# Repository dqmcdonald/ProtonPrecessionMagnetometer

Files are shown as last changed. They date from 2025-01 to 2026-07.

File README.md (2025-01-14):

Design files for a Proton Precession Magnetometer

Based on "Signals from the Subatomic World" by Stefan and Richard Hollos
https://books.google.co.nz/books/about/Signals_from_the_Subatomic_World_How_to.html

There are several related designs here including SVG files for cutting the coil formers and supports and
Kicad files for the pulse controller and signal amplipher. 

Hardware:

	PPM Amplifier v1.0 - initial failed design for signal amplifier

	PPM Amplifier v2.0 

  	PPM Mosfet Bank - PCB for coil switching mosfets

	Pulse Controller - Arduino based controller and ADC for data collection

	Various design files for polarising and sensor coil formers. 

Software:

	PPMPulseControllerADC - Arduino sketch for pulse control and signal 
				collection

	RPiPythonCode - Python scripts to run on the Raspberry Pi - overall
			control and final analysis.

There are some KiCad symbols and footprints in other respositories https://github.com/dqmcdonald/DQM_kicad_new.pretty and https://github.com/dqmcdonald/DQM_kicad

Quentin McDonald

October 2024

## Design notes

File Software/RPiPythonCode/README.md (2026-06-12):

# Proton Precession Magnetometer — Raspberry Pi Software

Python software for controlling and analysing a Proton Precession Magnetometer (PPM).
The system polarises a water sample with an electromagnet, then measures the Larmor
precession frequency of the protons as they relax back into alignment with Earth's
field.  The Larmor frequency is directly proportional to the total magnetic field
strength:

```
B (µT) = f (Hz) / 42.5775
```

---

## Hardware

| Component | Detail |
|---|---|
| Controller | Raspberry Pi (any model with a UART) |
| Microcontroller | Arduino Pro Mini |
| Serial connection | auto-detected (USB adapter or `/dev/serial0`), 250000 baud — override with `--port` |
| Coil | Solenoid wound around a water-filled sample bottle |

The Arduino controls the polarising coil (MOSFET switched) and samples the precession
signal via an ADC.  The Raspberry Pi sends configuration commands and retrieves the
raw sample data over serial.

### Coil and sample orientation

For maximum signal the coil axis must be **perpendicular to Earth's field**.
Earth's field lies entirely in the North–vertical plane, so there are two
equally valid setups:

- **Option A (recommended):** Orient the coil axis **East–West**, level.
  No tilt required — East is always perpendicular to Earth's field.
- **Option B:** Orient the coil axis in the North–South vertical plane,
  tilted `(90° − inclination)` above horizontal with the North end elevated.
  At 68°35′ inclination this is 21.4° above horizontal.

Run `ppm_geometry.py` for a diagram and full explanation tailored to your location.

---

## Installation

```bash
pip install pyserial numpy matplotlib scipy
```

All dependencies run on Raspberry Pi OS without additional system packages.

---

## Running a measurement

```bash
python ppmrun.py [options]
```

Each run creates a timestamped directory under `data/` containing the raw data
files, plots, and a log.

### Common examples

```bash
# Single run with default settings
python ppmrun.py

# Tag the run for easy identification
python ppmrun.py --tag outdoor_test

# Average 5 runs (improves SNR by √5)
python ppmrun.py --runs 5 --tag hillside

# Adjust hardware timing (e.g. longer polarisation)
python ppmrun.py --on-time 8000 --sample-time 2000

# Narrow the bandpass filter around the expected Larmor frequency
python ppmrun.py --low-freq 2200 --high-freq 2700

# Background subtraction: collect 2 coil-off acquisitions first and subtract
# their spectrum (suppresses mains harmonics inside the Larmor band)
python ppmrun.py --runs 3 --background-runs 2

# Re-analyse an existing data file without any hardware
python ppmrun.py --input data/ppm1.dat --tag reanalysis

# Re-analyse using an old no-sample recording as the background
python ppmrun.py --input data/ppm1.dat --background-input data/nosample.dat

# Collect data without generating plots
python ppmrun.py --no-plots
```

### All options

| Option | Default | Description |
|---|---|---|
| `--input FILE` | — | Re-analyse an existing `.dat` file; no hardware required |
| `--tag TAG` | `PPM` | Prefix for the output directory name |
| `--runs N` | `1` | Number of measurement cycles to average |
| `--background-runs N` | `0` | Coil-off acquisitions to collect for background spectral subtraction |
| `--background-input FILE` | — | Existing `.dat` file to use as the background instead of collecting one |
| `--on-time MS` | `6000` | Coil polarisation duration (ms) |
| `--sample-time MS` | `1500` | Sampling duration after coil off (ms) |
| `--sample-rate HZ` | `16000` | Requested ADC sample rate (Hz) |
| `--delay MS` | `500` | Delay between coil-off and sampling start (ms) |
| `--cool-down MS` | `10000` | MOSFET cool-down time between runs (ms) |
| `--low-freq HZ` | `2300` | Bandpass filter lower cutoff (Hz) |
| `--high-freq HZ` | `3300` | Bandpass filter upper cutoff (Hz) |
| `--fft-threshold MAG` | `0.0005` | Minimum periodogram magnitude for peak detection |
| `--no-plots` | off | Skip generating PNG graphs |
| `--output-dir DIR` | `data/` | Base directory for output |

### Output files

Each run produces a directory `data/<TAG>_YYYY_MM_DD_HH_MM_SS/` containing:

| File | Description |
|---|---|
| `run_00.dat`, `run_01.dat`, … | Raw ADC data for each measurement cycle |
| `background_00.dat`, … | Raw ADC data for each background (coil-off) acquisition |
| `original_00.png`, … | Three-panel plot of the raw signal (start / middle / end) |
| `filtered_00.png`, … | Same plot after bandpass filtering |
| `fft_averaged.png` | FFT periodogram averaged across all runs |
| `ppm.log` | Timestamped log of the session |

### Interpreting results

The strongest FFT peak is reported together with the implied field strength:

```
Strongest peak: 2435.3 Hz  →  B = 57.20 µT
Other candidates: 2448.1 Hz (mag=0.0008), 2421.7 Hz (mag=0.0006)
```

Expected Larmor frequency for your location (inclination 68°35′, ~57 200 nT):
**≈ 2435 Hz**.  If the reported peak is substantially higher or lower the signal
may be dominated by interference rather than genuine proton precession — check
hardware connections and coil orientation.

---

## Multi-run averaging

The `--runs N` flag collects N complete measurement cycles and averages their
FFT periodograms before peak detection.  Averaging in the frequency domain
does not require the signals to be phase-aligned; SNR improves by approximately
√N.  Each cycle includes the full polarisation + cool-down sequence, so N = 5
takes roughly `N × (ON_TIME + DELAY + SAMPLE_TIME + COOL_DOWN)` seconds
(≈ 90 s with default timings).

---

## Background subtraction

The `--background-runs N` flag collects N **background acquisitions** before
the measurement runs.  A background acquisition (firmware command `BKGND`)
samples the amplifier output with the polarising coil never energised, so it
records only amplifier noise and ambient interference.  Background runs are
fast: there is no polarise, settle, or cool-down phase.

The averaged background spectrum is rescaled to match the measurement noise
floor (the records are individually normalised, so absolute levels differ) and
subtracted from the measurement spectrum before peak detection.  This
suppresses **stationary** interference — anything present whether or not the
protons were polarised.  The headline case is mains harmonics: the 49th
harmonic of 50 Hz lands at **2450 Hz, inside the Larmor band**, where the
bandpass filter cannot touch it.  The genuine precession peak is unaffected
because it only exists in the polarised runs.

`--background-input FILE` uses an existing `.dat` recording (such as an old
no-sample run) as the background instead of collecting one; this also works in
`--input` re-analysis mode with no hardware attached.  The reported SNR is
always measured against the *unsubtracted* noise floor.

---

## Data file format

`.dat` files use a plain-text format:

```
<num_samples>
<actual_sample_rate_hz>
<sample_0>
<sample_1>
…
```

All values are integers.  Files can be re-analysed at any time with `--input`.

---

## Serial protocol

Command and control is ASCII.  Each command is a 5-character token with an
optional integer parameter, terminated by `\n` (e.g. `ONTIM 6000`), and the
Arduino replies with an acknowledgement line.  `EXECU` triggers a full
polarise-wait-sample cycle; `BKGND` triggers a sample-only background
acquisition with the coil never energised (no settle delay, no cool-down).

Measurement data, however, is returned as a single little-endian **binary**
frame.  This is roughly 3× more compact than a line-based ASCII format and
avoids per-sample text parsing for the tens of thousands of samples in a run:

```
bytes 0-3   marker  b'PPMD'
bytes 4-7   actual_sample_rate  (uint32)
bytes 8-11  num_samples         (uint32)
then        num_samples × int16 samples (signed two's complement)
```

The on-disk `.dat` files remain plain text (see above); only the
over-the-wire transfer is binary.

---

## Geometry diagram

```bash
python ppm_geometry.py                          # uses built-in inclination 68°35′
python ppm_geometry.py --inclination 51.5       # London, for example
python ppm_geometry.py --output my_diagram.png
```

Prints a text explanation of the coil orientation and saves a two-option diagram
showing the East–West horizontal setup (Option A) and the tilted meridian-plane
setup (Option B).

---

## Module reference

### `PPM.py`

Hardware interface.  Communicates with the Arduino over serial.

```python
ppm = PPM.PPMRun(logger)
ppm.configure(on_time=6000, sample_time=1500, sample_rate=16000,
              delay=500, cool_down=10000)
ppm.sendConfiguredValues()
ppm.doMeasurement(output_path="data/my_run/run_00.dat")

# Sample-only background acquisition (coil never energised)
ppm.doMeasurement(output_path="data/my_run/background_00.dat", background=True)

sample_rate = ppm.getActualSampleRate()   # Hz, as measured by Arduino
signal      = ppm.getSignalData()         # numpy array of ADC counts
```

### `PPMCalc.py`

Signal processing.  Works entirely on in-memory data; no hardware dependency.

```python
# Load from a saved file
sample_rate, num_samples, data = PPMCalc.load_from_file("data/ppm1.dat")

calc = PPMCalc.PPMCalc(sample_rate, sample_time_ms, data)

calc.plotSignal("raw.png")                # three-panel start/middle/end plot
calc.filterSignal(2300, 3300)             # Butterworth bandpass filter in-place
calc.plotSignal("filtered.png")
calc.plotAmplitudeEnvelope("envelope.png")  # RMS amplitude vs time

peaks = calc.doFFT("fft.png",             # returns [(freq_hz, magnitude), …]
                   low_freq=2300,         # sorted by magnitude descending
                   high_freq=3300,
                   threshold=0.0005)
```

### `ppmrun.py`

Main entry point.  Orchestrates hardware collection, analysis, and reporting.
Importable functions:

| Function | Description |
|---|---|
| `build_parser()` | Returns the `argparse.ArgumentParser` |
| `setup_run_dir(base_dir, tag)` | Creates and returns a timestamped run directory |
| `load_input_file(filepath)` | Loads a `.dat` file for re-analysis |
| `analyse(runs_data, args, run_dir, …)` | Filters, averages FFTs (optionally background-subtracted), returns `(peaks, snr)` |
| `background_periodogram(background_data, args)` | Averaged spectrum of background acquisitions |
| `subtract_background(f, den, bg_f, bg_den, lo, hi)` | Rescales and subtracts a background spectrum |
| `report_peaks(peaks, logger, snr)` | Prints peak frequencies, field strength, and SNR |

---

## Tests

```bash
python -m unittest discover -v
```

87 tests covering signal processing, file I/O, hardware communication (serial
port mocked, including the binary data frame and background acquisitions),
CLI argument parsing, background spectral subtraction, and the analysis
pipeline.  The test suite runs without hardware and without `pyserial`
installed.

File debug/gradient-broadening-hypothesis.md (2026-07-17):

# Why has there *never* been a signal? — binary-failure analysis & the gradient-broadening hypothesis (2026-07-12)

After the 07-12 "site1" runs (larger sample bottle filling one sensor coil,
rig moved ~20 m from the building) still showed nothing — comb-notch Larmor
gap empty, envelope flat, sample ≈ no-sample — the question changed from
*"why is the signal weak?"* to *"why has nothing with FID shape ever
appeared, at any point, in any data set?"* This note works that question
through the physics budget and the verification record, and lands on one
surviving hypothesis with a concrete, mostly-free test plan.

> **STATUS 2026-07-16 — ✅ HYPOTHESIS VINDICATED. Test 3 (off-site,
> non-basalt) produced the FIRST CONFIRMED PROTON FID.** The rig, **unchanged**
> from its basalt configuration, was driven ~10 km off the volcanic peninsula
> to the Groynes (braided-river sediment/gravel flats) and showed a clean
> decaying proton line: **2431.4 Hz, SNR 26–32 dB/run, T2\* ≈ 1.0 s**, present
> ONLY with the water sample, killed by a ferrous toolbox set beside the coils,
> and off the 50 Hz mains comb (2431 = 48.6 × 50). **B = 57.11 µT, matching the
> regional observatory to ~0.1%.** This lands squarely on the §4 Test 3 fork —
> *"signal appears off-site → gradient broadening confirmed."* The 2-month total
> null was **environmental**: basalt static-field gradients crushed T2\* below
> the ~40 ms amplifier-blind window at home; on sediment T2\* returns to ~1 s and
> the FID sits in plain sight, exactly as §3 predicted. Full data + analysis:
> `Software/RPiPythonCode/data/groynes/` and the 2026-07-16 section of
> `magnetometer-debug-notes.md`.
>
> **UPDATE 2026-07-17 — Test 1 (gradient survey) run; see §4 Test 1 RESULT.**
> The home site's lower deck measures **5660 nT across 150 mm (37.7 nT/mm)** —
> 19× the 300 nT threshold ⇒ ΔB ≈ 3200 nT across the bottle ⇒ **T2\* ≈ 2.3 ms**,
> dead inside the 40 ms blind window. The null is now explained *quantitatively*
> at the home site itself, not just by inference from the off-site success.
> **But the killer looks like a discrete shallow object (~4–6 cm down — a deck
> screw / bracket), not the basalt**: the anomaly is a 75 mm-wide +6 µT spike, not
> a regional gradient. The broad +0.7–2.0 µT pedestal from the mass enclosed under
> the deck (tank/pipework/rebar) is *nearly harmless* — a uniform offset shifts
> the Larmor frequency but does not broaden the line. **So the lower deck may be
> recoverable by moving ~150 mm, and "basalt" may be the wrong villain at home.**
> Note the phone cannot clear any site: its drift floor (~830 nT / 30 s) is ~100×
> the 7.5 nT that T2\*≈1 s requires — it can only *reject*.
>
> **What this settles and what remains.** The *instrument* is now proven
> end-to-end — the design works. The open problem is no longer "is there a
> signal" but "make it work AT HOME on basalt," which is a **gradient-mitigation**
> task, not rig debugging. Both home-enabling levers attack the same "FID dies
> inside the ~40 ms blind window" bottleneck from opposite ends:
> **(a) smaller sample** — lengthen the gradient-limited T2\* so more FID survives
> the dead time (free, passive; costs signal amplitude — see the tradeoff
> analysis in the 2026-07-16 debug-notes section); **(b) Test 2b input clamp** —
> shorten the dead time so a full-size, short-T2\* sample is observable (hardware,
> keeps signal). See the ranked next-steps list in `magnetometer-debug-notes.md`.
>
> ---
> *Superseded status (2026-07-14, kept for the reasoning trail): hypothesis
> UNTESTED but CORNERED — `delay = 5` showed the blind window is set by
> amplifier overload recovery (~40 ms), not firmware `DELAY`; that bounded T2\*
> to either ≲ 40 ms (hidden) or nonexistent, promoting Test 3 to the decisive
> fork. Test 3 has now resolved it in favour of the hypothesis. Details in §4.*

---

## 1. The physics budget says detection should be EASY — so the failure is binary

From Design calc 2 (2026-06-13, `magnetometer-debug-notes.md`): water proton
magnetization at the measured ~8 A polarizing current gives **ε_pk ≈ 0.3 µV**
at the sensor coil, → **SNR ≈ 40+ dB single-shot untuned**, more with the
tuned tank (measured Q ≈ 5). Every scaling input in that calc is now
*measured*, not assumed: 8 A restored (07-04), quench non-adiabatic (07-03),
tank tuned to 2435 Hz (06-21), filling factor maximized (07-12 big bottle).

**Cross-check against the book's own result:** Fig 7.6 (FFT of filtered
data, Longmont CO) shows the proton peak at ~1650 counts over a ~100-count
floor — only **16× ≈ 24 dB**. The book's signal is *not* extraordinarily
strong; it is exactly what a working rig at this design point produces, and
it is *within the SNR range this rig already logs for mains harmonics*.

**Implication:** we are not 3 dB of averaging away from a detection. A
signal predicted at 25–40 dB that shows **0 dB, always,** means some element
is zeroing it categorically — a binary failure, not a marginal one.

## 2. Binary failures already excluded by the verification record

| Candidate binary failure | Excluded by | Date |
|---|---|---|
| Polarize pulse not firing | LED red over on-time + compass deflect + clamp 8 A | 07-03/04 |
| Adiabatic (slow) quench | Shunt: full collapse ≤ 66 µs vs 411 µs Larmor period | 06-12, 07-03/04 |
| Sensor coil miswired / gradiometer backwards | Sig-gen test-coil: signal ONLY inside one coil, **null when centred** — that null is the signature of correct series-opposition; a same-sense miswire would *add* for a centred source | 06-13 |
| Sensor coil open / wrong L / tank off-frequency | Ring-down: 412–416 µs period = 2.40–2.43 kHz, L ≈ 5.5 mH consistent | 06-19/21 |
| Receive chain dead (coil→amp→ADC→software) | 2436–2440 Hz injection through sensor coil: 52–60 dB, B calibration correct to 0.1% | 06-13, 06-21 |
| Pipeline fabricating/losing peaks | Grounded & shorted runs: clean "No peaks found" | 06-13, 06-21 |
| Polarizing-axis geometry null | Impossible for a horizontal EW axis: field (dip 68.6°) ⊥ East axis regardless of declination (cos∠ = cos I·sin D ≤ ~0.13 for any plausible D → ≥ 82° from parallel). NS is only cos-factor worse (×0.93), yet equally empty — orientation can modulate, not null | 06-25→07-12 data |
| Mains masking a buried line | Comb-notch: Larmor gap (2412–2438 Hz) is *empty* after notching, sample ≈ reference | 07-01, 07-12 |
| Filling factor | Big bottle fills the coil volume | 07-12 |

Nothing on this list can be the killer. What's left must be something the
tests so far are structurally blind to.

## 3. The surviving suspect: T2* crushed by local static-field gradients

### The loophole in every decay test run to date

All acquisitions use `DELAY ≥ 25 ms` between quench and first sample, and
the decay discriminators (quarter-ratio in `comb_notch.py`; even the 07-12
fine 15 ms-window test) only see **t > 25 ms**. If T2* ≈ 10 ms:

- at t = 25 ms the FID amplitude is already e^(−2.5) ≈ **8%** of ~0.3 µV ≈ 25 nV;
- its energy is spread over Δf = 1/(π·T2*) ≈ **30+ Hz** — wider than the
  25 Hz Larmor gap itself;

→ invisible to every test at any averaging depth. **A short-T2* FID has
never been excluded — it has never been *observable* with these settings.**

### Why short T2* is plausible at THIS site and not the book's

T2* in Earth's field is set by ΔB across the sample: Δf = 0.0426 Hz/nT · ΔB,
T2* ≈ 1/(π·Δf).

| ΔB across 10 cm sample | Linewidth | T2* |
|---|---|---|
| 30 nT | 1.3 Hz | 0.25 s (book-like) |
| 300 nT | 13 Hz | 24 ms (marginal at DELAY 25) |
| 500 nT | 21 Hz | **15 ms (dead before sampling)** |

- **Geology:** the book's rig ran in Longmont CO — flat sedimentary plains,
  typical gradients ~10 nT/m. This site is a **basalt volcanic peninsula**
  with documented anomalies of ±1000s nT over metres (06-24 addendum) —
  gradients of 3–5 µT/m near inhomogeneous flows are entirely plausible,
  giving 300–500 nT across the sample.
- **Rig-local ferrous sources:** a single steel screw at 10 cm produces
  µT-scale ΔB; platform brackets, the SLA battery, and a steel bottle cap
  are all candidates.
- Book Fig 7.6's peak is ~1–2 bins (~0.5–1 Hz) wide → their T2* ≳ 0.5 s.
  The authors could afford to *drop the first 0.2 s* of every record (Ch. 7)
  and still see it. On basalt that luxury may not exist.
- **Irony:** the 07-12 larger bottle *worsens* gradient broadening — more
  protons, but spanning more ΔB. (If gradients dominate, a *smaller* sample
  has a longer T2*.)

This directly formalizes the "could the local environment be broadening the
signal?" question raised 2026-07-12 — the answer is: it's the one mechanism
left standing, and it's testable for free.

## 4. Test plan (ranked)

### Test 1 — Static gradient survey at the sensor position (free, ~30 min, decisive)

Phone magnetometer (Physics Toolbox or similar) taped to a **wooden** stick;
rig, battery, and anything ferrous moved a few metres away. Map total field
|B| on a grid over ±15 cm around where the sample sits (e.g. 5×5 horizontal
+ two heights), phone in fixed orientation, average a few seconds per point.
Separately wave it near the platform hardware and the bottle cap.

**Decision thresholds:**
- ΔB > ~300 nT across the sample volume → **gradient broadening is the
  killer**; fix is site/hardware (Tests 2–3), not electronics.
- ΔB < ~100–200 nT → gradients exonerated; go to Test 4.

Caveat: phone resolution/noise ~0.1–0.6 µT — average readings, keep
orientation fixed; it resolves the >300 nT threshold but not much below it.

#### ✅ RESULT 2026-07-17 — lower deck FAILS by 19×; and the killer is a *discrete shallow object*, not the basalt

Phone (Physics Toolbox) on a 1 m plywood batten, fixed N/S orientation, 150 mm
traverse, 5 s dwells, two heights 100 mm apart. Lower deck (the historic
measurement position) vs upper deck (+3.5 m). Data + analysis:
`phone_magnetometer_data/` (`plot_gradient_survey.py` → `gradient_survey_2026-07-17.png`).

| | lower deck | upper deck (+3.5 m) |
|---|---|---|
| |B| median | 58.95 µT | 56.65 µT |
| spread across 150 mm | **5660 nT** | 1015 nT |
| mean gradient | **37.7 nT/mm** | ≤ 6.8 nT/mm |
| ΔB across the 85 mm bottle | **3207 nT** | ≤ 575 nT |
| implied linewidth / T2\* | 137 Hz / **2.3 ms** | ≥ 24 Hz / ≤ 13 ms |
| **phone's own drift floor** | 568 nT | 834 nT |
| verdict | **REAL — 10× the floor** | **1.2× the floor — unresolvable** |

**Lower deck: condemned.** 5660 nT is 19× the pre-registered 300 nT threshold and
10× the phone's own drift, so it is unambiguously real. ΔB ≈ 3200 nT across the
bottle ⇒ **T2\* ≈ 2.3 ms** — born and dead deep inside the ~40 ms blind window,
with room to spare. This is a complete, quantitative explanation of the 2-month
null and it lands exactly where §3's table predicted.

**Upper deck: NOT exonerated — un-measured.** Its 1015 nT is only **1.2× the
phone's own drift floor**, i.e. statistically indistinguishable from the phone
lying motionless on a table. The §4 caveat above turns out to be *optimistic*
over a traverse this long: while stationary the phone wanders 810–890 nT p2p and
random-walks to ~830 nT over 28 s — ~100× the **7.5 nT** that the Groynes
T2\*≈1 s actually implies. **The phone is a *reject* instrument, not an *accept*
one.** It cannot clear any site, and no better phone protocol changes that.

##### The lower-deck anomaly is TWO sources, and only one of them matters

The traverse is not a smooth gradient — it is flat at 57.9 µT, steps to a 63.2 µT
plateau, steps back to 59.1, settles at 58.4. Level-1 dwells at 0 / 75 / 150 mm,
as anomaly above the 57.11 µT regional field: **+0.74 / +6.09 / +2.03 µT.**

1. **A sharp SPIKE** — peak +6.1 µT, down 4.4× within 75 mm. Inverting the
   falloff puts the source **~58 mm away if compact (1/r³), ~41 mm if a long
   pipe/bar (1/r²)**. Either way it is *small and shallow* — a few cm under the
   boards. A tank or rebar mesh cannot do this: it would give a broad flat-topped
   anomaly metres wide, not a 75 mm-scale peak. §3 already notes *"a single steel
   screw at 10 cm produces µT-scale ΔB"* — at ~5 cm, **a single deck screw, nail
   plate, or joist bracket fully accounts for this spike.**
2. **A broad PEDESTAL** — *every* lower-deck dwell sits +0.7 to +2.0 µT above
   regional. *This* is the signature of the large hidden mass (old water tank /
   pipework / rebar known to be enclosed under the wooden deck).

**Crucially, the pedestal is nearly harmless.** A uniform offset shifts the Larmor
frequency; it does not broaden the line. **Only the gradient broadens.** So the
big buried tank is very likely *not* what has been killing the signal — the
shallow spike is.

**⇒ The lower deck may be recoverable without moving decks at all.** The spike is
localized; the flat regions between dwells are at the phone's floor (i.e. also
un-measured, not proven bad). **The open question is where the rig actually sat
relative to the +6 µT spike** — if the sample has been sitting on top of a deck
screw, pulling that screw may be the entire fix. Worth 5 minutes with the phone
before hauling the rig upstairs.

**A source this shallow makes Test 3b (raise the sensor) the strongest lever on
the list — see the 2026-07-17 update there.** Modelled as a dipole at d ≈ 5 cm
falling as 1/(d+h)³, the attenuation of this spike is **~340× at h = 0.3 m** and
**~9,000× at h = 1 m**, versus only **~32× for moving 150 mm sideways.** A short
non-ferrous stand plausibly beats both relocating and Test 2b, because it attacks
ΔB itself rather than fighting the dead time. Ranked home actions after this
survey: **(1) find/pull the screw, (2) raise the sensor ~0.3–1 m on a wood/PVC
stand, (3) shrink the sample, (4) Test 2b.**

**Method note for any repeat — do NOT repeat the slow traverse.** A 30 s sweep is
the *worst* use of this sensor: it accumulates the full random walk between first
and last point. The drift scales as 90 nT @ 1 s → ~140–230 nT @ 3 s → ~570–830 nT
@ 28 s. Use **rapid A/B/A/B swaps** (2 s per point, 8–10 repeats): each difference
carries only ~125–195 nT of drift, and √N averaging gives **~40–60 nT** — a ~15×
improvement, and the only phone protocol that clears 300 nT with confidence. It
still tops out ~5× above the 7.5 nT budget, which is the point.

*Data caveats:* the phone screensaver (~30 s timeout) truncated both logs — 4–5 of
the planned 6 dwells survived in each, so the 100 mm vertical pair never got
measured. Everything after each gap is at a different sensor attitude (phone
picked up) and was discarded. Neither loss affects the verdicts above.

### Test 2 — Minimum-DELAY run (one config change) — ✅ RUN 2026-07-14; RESULT BELOW

Firmware accepts any `DELAY` value (no lower bound in
`PPMPulseControllerADC.ino`; it's a plain `delay(sample_delay)`). Quench
ring is done in ~0.3 ms and the tank rings down with τ = Q/(πf) ≈ 0.7 ms, so
**`delay = 5`** is safe. Run sample + matched no-sample, then inspect the
first ~30 ms of the comb-notched gap-band envelope at ~2 ms resolution.
A fast-decaying early bump present only with sample = the broadened FID
caught directly. (Watch for amp/transformer recovery artifacts in the
no-sample control — they'll be common to both if benign.)

#### ⚠ RESULT 2026-07-14 — the parenthetical caveat above turned out to be the whole story

Ran `delay = 5` (`data/delay/SAMPLE_5MS_2026_07_14_16_39_12`, 12 signal +
6 background). The coil-pulsed runs do show a big decaying in-band excess the
coil-off backgrounds lack — head(5–35 ms)/tail(1–2 s) envelope ratio
**6.26 ± 0.43** across all 12 runs vs **1.02** for backgrounds. **It is not an
FID:**

| observation | value | reading |
|---|---|---|
| peak count, 5–10 ms after quench | 31276 = **95% of full scale** (RMS 20565 vs steady 2060) | front end is **railed** |
| envelope decay constant | **τ ≈ 38 ms** | tank would be 0.65 ms; water T2\* is 1–2.5 s → neither |
| strongest early bin | **2349 Hz** | 47 × 50 mains, already proven pinned to mains (06-28 retune test) |
| Larmor gap (2405–2445) excess | only 1.9× over background | nothing there |

It is the pulse-induced ring parking on a mains harmonic, seen through a
saturated amplifier — a *steady* line only appears to "decay" because the
clipped gain is recovering.

**This test cannot answer the question in its current form, and Test 2's premise
was wrong.** The blind window is not set by the firmware `DELAY` at all — it is
set by **amplifier overload recovery**. The first genuinely usable sample is
~15–25 ms and the front end is not settled until **~40 ms**, essentially where
`delay = 25` already was. Shortening `DELAY` moves the *sampling* window earlier
but the *amplifier* is still saturated there, so nothing is gained.

**Consequence for the hypothesis: it is neither confirmed nor refuted — it is
still untestable.** If T2\* really is 10–15 ms, the FID is born and dies entirely
inside the interval where the front end is blind. The hypothesis' central
loophole ("no decay test has ever been able to see a short-T2\* FID") therefore
*stands*, but the fix is not a shorter delay — see Test 2b.

#### Dead-time budget: ours vs the book — and the T2\* bound it implies

The book has **no input protection either**; its answer to the overload is
simply to wait it out — `DELAY = 100 ms`, then discard the first 2000 points at
16384 Hz (= 122 ms), so **~222 ms of dead time** before it starts looking. That
is affordable *at Longmont*: at T2\* = 1–2.5 s it costs only ~9–20% of the FID.
The architecture therefore **quietly assumes a long T2\***. Against a 10–15 ms
T2\*, 222 ms of dead time leaves e^(−222/12) ≈ 10⁻⁸ of the signal — not degraded,
annihilated. **So a working book rig tells us nothing about whether this design
*could* work at a short-T2\* site: at the book's site the question never arises.**

**Our dead time is ~40 ms of amplifier recovery — about 5× better than the
book's 222 ms.** We are looking considerably *earlier* than a known-working
instrument, not later. That inverts the usual reading of a null result:

> If a normal, long-T2\* proton signal existed at this site, we would see it
> **more easily than the book does**, not less. We don't.

Combining that with the 07-14 envelope data bounds T2\* directly:

- **T2\* between ~50 ms and 2 s — EXCLUDED.** An FID in that range would leave a
  decaying excess in the 55–205 ms window; there is none (1.14× then 1.03× over
  background, and even that is the amplifier's own recovery tail).
- **T2\* ≲ 40 ms — still completely invisible**, because the front end is blind
  exactly there.

There is no comfortable middle left: **either T2\* is short enough to hide inside
the 40 ms blind window (the hypothesis, now cornered into almost exactly the
10–15 ms it predicted), or there is no signal at all.** Both remaining branches
are settled by Test 3, which needs no hardware change — see there.

### Test 2b — Stop the front end saturating (NEW; the home-enabling hardware fix)

Nothing downstream can see a short-T2\* FID until the amplifier survives the
quench without clipping. Fix: a clamp at the **INA217 inputs** (U1, the first
stage). The existing ±9.1 V zener limiter sits at the *output* of the chain
(OP177G): it protects the ADC but does nothing for the in-amp being slammed.
Target: recovery in milliseconds, not tens of them, so that a 10–15 ms FID is
actually observable. Re-run Test 2 afterwards.

**What the clamp does — and does not — do.** It is *not* meant to keep U1
linear through the transient (no passive diode can: U1's gain is 1958, so it
saturates at only ~5 mV differential — see amp-v2.0-design-review.md item 1 —
and a silicon clamp holds ±0.6 V, still ~120× into overload). Its job is to
**limit overdrive depth**, since overload-recovery time scales with how hard
the input was driven: clamping a ~30 V kick to ~0.6 V cuts overdrive from
~6000× to ~120× (~50×), which is the lever that should pull the 40 ms recovery
down toward a few ms.

**Where the diodes go — each input to GROUND (recommended for this topology).**
The sensor coil lands on J2 with its electrical **centre grounded at J2.3**
(the gradiometer mid-point; amp-v2.0-design-review.md item 2), so the two coil
ends drive **U1 pin 4 (V_IN−)** and **pin 5 (V_IN+)** push-pull about ground.
Put an **anti-parallel diode pair from each input node to GND** (4 diodes, or
two dual packages) — this bounds each pin to ±one diode drop and, because the
centre tap already references ground, clamps both the differential and the
common-mode excursion.

```
 J2.1 ─[½ coil]─┬─ Rs(opt) ─┬──────── U1 pin 4 (V_IN−)
 J2.3 ─ GND     │           ⊥ D1a▼ D1b▲ → GND
 J2.2 ─[½ coil]─┴─ Rs(opt) ─┬──────── U1 pin 5 (V_IN+)
                            ⊥ D2a▼ D2b▲ → GND
```

Alternatives: *across the coil* (pin 4↔pin 5) is a simpler 2-diode differential
clamp — fine here since the grounded CT largely pins the common mode — but it
leaves common-mode unbounded, so to-ground is preferred. *Clamping to the ±12 V
rails* is the textbook in-amp method but clamps at ±12.6 V, far too loose for a
part that saturates at 5 mV — not useful here.

**Diode spec.** The usual worry (clamp leakage injecting offset into a µV path)
is a **non-issue here**: the source impedance is only ~3 Ω through half the
coil, so even 25 nA of leakage is ~75 nV of offset and the shot noise is
~0.01 pV/√Hz. So the choice is driven by **clamp tightness and surge survival**,
not leakage.

| Parameter | Want | Note |
|---|---|---|
| Type | fast **silicon** switching diode | 0.6 V clamp; Schottky (0.3 V) clamps marginally tighter and its µA leakage is tolerable at 3 Ω, but U1 saturates either way so the gain is small |
| trr | < ~50 ns | catch the fast quench edge |
| Surge IFSM | ≥ ~1–2 A non-repetitive | survive the kick |
| Capacitance | < ~5 pF | irrelevant at 2.4 kHz / low-Z |

Concrete parts: **1N4148 / 1N4148W** (cheap, trr ~4 ns, ~2 A surge, <1 nA typ
leakage — two per input to GND); or **BAV199** (SOT-23 dual low-leakage, tidy
per-input pair); **BAS416** if belt-and-braces ultra-low leakage is wanted (not
needed at 3 Ω). Avoid Schottky only if the front end later moves to a high-Z
input.

**Series resistor Rs (optional).** The coil's ~5.4 mH already limits di/dt into
the clamp, so a bare 1N4148 will likely survive. To guarantee it, add
**10–22 Ω** per input between coil and clamp node (clamp on the IC side of Rs).
Noise cost is small — 2× 13 Ω raises front-end noise ~1.3 → ~1.45 nV/√Hz
(~12 %). Keep ≤ ~22 Ω; 100 Ω would double the noise.

**Before cutting copper:** scope U1 pin 4/5 to GND (10× probe) during a quench
to measure the *actual* transient amplitude and duration — that confirms the
surge rating and whether Rs is needed. **Expect partial success:** the ±0.6 V
clamp reduces recovery depth but does not restore linearity, so if the scope
still shows recovery too long after clamping, escalate to **active input
blanking** — a small FET that shorts/disconnects the U1 inputs during the
polarize+quench window and releases just before sampling. That is the definitive
fix (keeps U1 out of overload entirely) but a bigger change; try the passive
clamp first. (U1 also has weak internal input-protection diodes; the external
clamp offloads them regardless.)

**Control still owed on Test 2 either way:** `BKGND` never energises the coil,
so it cannot reproduce a pulse-induced transient, and the 07-14 session had no
coil-pulsed no-sample run. Run one at `delay = 5` (same settings, bottle
removed). If the early excess is unchanged without the sample, it is 100%
amp/mains, as the numbers above imply.

### Test 3 — One session on non-basalt ground — ✅ **RUN 2026-07-16: SIGNAL APPEARED — hypothesis confirmed**

> **RESULT (Groynes, sediment/gravel flats, ~10 km off-basalt, rig unchanged):**
> first confirmed proton FID — 2431.4 Hz, SNR 26–32 dB/run, **T2\* ≈ 1.0 s**,
> sample-dependent, off the mains comb, killed by a nearby ferrous mass, B =
> 57.11 µT (observatory-matched to 0.1%). This is the "signal appears off-site"
> branch below → **gradient broadening confirmed**. See the top-of-file STATUS
> block and the 2026-07-16 debug-notes section for the full five-proof writeup
> and next steps. The rest of this section is the pre-run rationale.

A beach / alluvial flat kills the basalt gradient AND the mains comb in one
trip (rig is already fully battery-portable). If Test 1 shows big gradients,
this is the confirming experiment: a clean site should produce a
book-quality narrow line if broadening is the whole story.

**Promoted 2026-07-14** (planned for ~2026-07-16). Given the T2\* bound above,
this is now the experiment that settles the question, and it needs **no hardware
change at all**. At a low-gradient site T2\* should return to 1–2.5 s, and such
an FID is only ~2–4% decayed by the time our amplifier clears at 40 ms — it would
sit there in plain sight with the rig exactly as it stands today.

- **Signal appears off-site** → gradient broadening **confirmed**. The basalt
  site then needs Test 2b (input clamp) to be usable at all, and we know exactly
  why.
- **Nothing appears off-site either** → the hypothesis is **dead**, and the fault
  is something the verification record has not caught.

Use **`delay = 25`**, not 5: the 5 ms buys nothing while the amplifier is blind
for ~40 ms regardless, and 25 keeps the capture directly comparable with every
historical run. Take a coil-pulsed no-sample control at the same site.

### Test 3b — Raise the sensor off the ground: Test 3 done *vertically* (home fix, ~free to test)

Test 3 escaped the basalt by moving ~10 km **horizontally**. Height is the same
escape done **vertically, in place** — a partial relocation that stays at home.
It attacks a *different* part of the bottleneck than the smaller-sample / input-
clamp levers: those help a short-T2\* FID *survive the dead time*; raising the
sensor instead tries to **lengthen T2\* itself by reducing the gradient the sample
sits in.**

**Why it should work (and how far).** For a distributed near-surface source like
basalt, elevation acts as **upward continuation** — a low-pass spatial filter. A
gradient component of horizontal wavelength λ is attenuated with height h by
≈ **exp(−2π·h/λ)**:

| gradient content | at h = 1 m | reading |
|---|---|---|
| short-wavelength inhomogeneity, λ ≈ 2 m | exp(−π) ≈ **0.04** (~23×) | the steepest gradients — killed fast |
| regional / flow-scale, λ ≈ 30 m | ≈ 0.8 (~20% off) | barely touched, but already *gentle* (little ΔB across 10 cm) |

The gradient crushing T2\* is almost certainly dominated by the short-wavelength
content — an infinite *uniform* half-space has zero gradient, so all of ΔB comes
from the lateral departures-from-uniformity, i.e. exactly what height suppresses.
Dragging 400 nT toward the book-like <30 nT needs ~10–15×, which 1–2 m plausibly
buys **if** the anomaly is short-wavelength.

**The bound.** Height only helps against **ground/geology**. It does **nothing**
against **rig-local ferrous** (bottle cap, brackets, battery, a stray screw) —
those ride up with the sensor, so their r is unchanged. Height and de-ferrousing
(§B.4) are complementary, not substitutes; the survey (Test 1) separates the two.

**The free test — it's already latent in Test 1.** Test 1 maps |B| at *two
heights*; that two-height data **is** the vertical-decay measurement. It tells you
directly whether raising the rig buys the needed ~10–15× or only ~1.5× **before
building anything.** If the two-height ratio is promising, confirm with a live
run on a **non-ferrous** (wood/PVC) stand, sample raised ≥ 1 m, `delay = 25`,
plus the coil-pulsed no-sample control; watch `envelope_NN.png` for a lengthened
T2\*.

> **⚠ UPDATE 2026-07-17 — Test 1 has run; this section needs two corrections, and
> the net is STRONGLY in this lever's favour. See §4 Test 1 RESULT.**
>
> **1. The "free test" did not happen.** The phone screensaver (~30 s timeout)
> truncated both logs before the second height level completed, so **the
> two-height pair was never measured.** The only vertical data is the
> lower-vs-upper-deck comparison (Δh = 3.5 m: 5660 → 1015 nT), which is a coarse
> stand-in — and it confounds height with location, since the decks are not the
> same spot. It is *consistent* with height helping; it does not isolate it.
>
> **2. The λ table above is the WRONG model for what was actually found, and it
> badly understates this lever.** That table assumes a *distributed* basalt
> source. The measured killer is a **compact object ~5 cm below the sensor**
> (a deck screw or bracket — see Test 1 RESULT). A compact shallow source is the
> **shortest-wavelength content that exists**, i.e. exactly the case upward
> continuation annihilates rather than merely attenuates. Modelled as a dipole
> falling as 1/(d+h)³ with d = 5 cm:
>
> | raise the sensor by | attenuation of the +6 µT spike |
> |---|---|
> | 0.3 m | **~340×** |
> | 1.0 m | **~9,000×** |
> | 2.0 m | ~69,000× |
>
> For comparison, moving **150 mm sideways** buys only ~32×. **For a source this
> shallow, height beats lateral offset by orders of magnitude** — a ~300 mm
> non-ferrous stand may be all that is required, and it is cheaper than either
> relocating decks or Test 2b.
>
> **3. The "geology only" bound needs restating.** This section says height helps
> against ground/geology but not rig-local ferrous. The measured source is
> *neither*: it is in the **deck structure** — it does not ride up with the
> sensor (so height works on it), but it also is not the basalt (so §B.4's
> de-ferrousing works on it too, by moving away or pulling the screw). The
> correct dichotomy is **"does it move with the sensor?"**, not
> "geology vs ferrous". This one doesn't. **Height and §B.4 are both live.**

Caveats: keep the whole support and polarizing-coil geometry non-ferrous; there
is a mechanical ceiling, and against a long-wavelength anomaly you hit
diminishing returns before book quality (the survey tells you which regime you're
in first). If height becomes an operating parameter it **must be logged** — the
sensitivity cuts both ways, and inconsistent height would itself masquerade as a
field change.

### Test 4 — Only if the survey is clean: re-verify the budget's inputs

If gradients are exonerated, some budget assumption is broken. Measure
(a) the polarizing field actually present *at the sample* — phone
magnetometer at reduced current (~0.5 A so the sensor isn't saturated),
scale linearly to 8 A; expect ~60–70 G equivalent at centre; and
(b) absolute receive sensitivity — a calibrated µV-level injection
(divider + test coil per the 06-13 setup) to put a hard number on the
smallest detectable coil EMF.

## 5. Tilt sweep: demoted

The planned tilt sweep can't explain or fix a *total* null: geometry gives
the horizontal-EW polarizing axis ≥ 82° from the field for any plausible
declination error, and orientation errors only cost cos-factors (NS, which
is geometrically 21° worse, is just as empty). Run the gradient survey
first; revisit tilt only as an optimization *after* a first detection.

---

*Session data behind this note: `Software/RPiPythonCode/data/site1/`
(SAMPLE/NOSAMPLE × EW/NS, 2026-07-12), comb-notch plots
`comb_notch_spectrum_EW.png` / `_NS.png` in the same dir. Prior EMF budget:
"Design calc 2" in `magnetometer-debug-notes.md` (2026-06-13).*

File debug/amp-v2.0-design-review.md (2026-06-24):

# PPM Amplifier v2.0 — KiCad Design Review (2026-06-13)

Reviewed: `Hardware/PPM Amplifier v2.0` (`.kicad_sch` + `.kicad_pcb`).
Tools run: schematic analyzer, PCB analyzer (`--full`), cross-domain, EMC
pre-compliance, ngspice. 45 components, 53 nets, 130×60 mm, 2-layer, all-SMD.

**Verification basis: CONSISTENCY ONLY.** No MPNs on the BOM (0/27) and no
`datasheets/` directory (analyzer DS-001 + SS-001 errors). Every pin-level claim
below is read from the *custom* `DQM:` library symbols and the netlist — it is
**not** verified against manufacturer datasheets. The two custom analog ICs
(U1/U2) are the weakest point and need datasheet confirmation (see Blocker 1).

---

## Verdict

The architecture is sound and the layout is genuinely good for a high-gain
analog board (clean left-to-right flow, transformer breaking the DC chain,
full decoupling, output limiter). After verifying the parts from the board
photos and confirming the coil wiring, **both original blockers are cleared**:
the in-amps and transformer are correct and genuine, and the input bias-return
is provided by the grounded coil centre tap (J2.3). **No design blockers
remain.** If this board still gives no signal, the cause is upstream of the amp
(proton-signal generation/coupling, or the tank simply not tuned via SW1), not
in the amplifier design. Remaining items below are layout/robustness
improvements, not blockers.

---

## Blockers — verify before trusting the board

### 1. U1/U2 in-amp — VERIFIED CORRECT (resolved from board photos + datasheet)
Board photos show the chips marked `ti INA217 3BAVQKT` in a 16-pin package.
The INA217 **is** offered in a **SOL-16 (wide SO-16, "DW") package**
(INA217AIDW) — not just DIP-8 — so these are **genuine INA217** and the
16-pin `SOIC-16W` footprint is correct.

Pinout verified pin-by-pin against the TI INA217 datasheet SOL-16 diagram:

| Board pin | Wired to | Datasheet (SOL-16) | Match |
|---|---|---|---|
| 2 & 15 | R1/R2 = 5.11 Ω | RG1, RG2 | ✓ |
| 4 | J2.1 / cap bank | V_IN− | ✓ |
| 5 | J2.2 / SW1 | V_IN+ | ✓ |
| 7 | −12 V | V− | ✓ |
| 10 | GND | REF | ✓ |
| 11 | T1 primary | V_OUT | ✓ |
| 13 | +12 V | V+ | ✓ |
| 1,3,6,8,9,12,14,16 | NC | NC | ✓ |

Every pin matches. Gain = 1 + 10 kΩ/R_G = 1 + 10000/5.11 = **1958/stage →
3.83 M total**, matching the 3.8 M design figure. In-amp stages are correctly
specified, footprinted, wired, and genuine. **No action.**

### 2. Input DC bias-return — RESOLVED (grounded coil centre tap)
Earlier flagged as a blocker because the U1 inputs (pins 4/5) connect only to the
coil + DC-blocking tuning caps, with no resistor to ground. **User confirmed the
coil's electrical centre is tied to GND at J2.3** (the gradiometer mid-point).
That gives each input a **~3 Ω DC path to ground through its half of the coil** —
a fully defined common mode and a proper bias-current return for the INA217's
bipolar (µA) inputs. **No action.**

Note: this is the *correct* solution and better than discrete resistors — a
megohm-to-ground would drop µA×MΩ ≈ volts of offset on a bipolar-input part;
the ~3 Ω coil path drops only microvolts. Caveat (operational, not a flaw): the
bias return exists only when the coil is connected. Powering the board with the
input **open** (no coil) will rail — expected; a shorted-input test is fine.

---

## High — should fix

### 3. T1 wiring — VERIFIED CORRECT (downgraded from a flag)
Resolved after looking up the part. The **42TL016 is 600 Ω : 600 Ω, 1:1,
center-tapped** (±3 dB 300 Hz–3.4 kHz, 75 mW). Standard 6-pin layout:
primary 1-2-3 with **pin 2 = center tap**; secondary 4-5-6 with **pin 5 =
center tap** (matches the symbol — pin 2 is named "PM" = primary mid).

Your wiring: pin 1 ← U1 output, pin 3 → GND, **pin 2 (primary CT) open**;
pin 5 (secondary CT) → GND, pins 4/6 → U2's two inputs. This is **correct**:
the primary is driven full-winding end-to-end (1→3) for the full 1:1 ratio with
the CT unused, and the grounded secondary CT converts to a balanced ±
differential drive into U2. A floating *center tap* is the intended state, not
a fault.

What the transformer buys the design: (1) 1:1 interstage coupling; (2) **DC
block** — U1's offset (×~2000) can't cross it, so the 3.8 M gain chain doesn't
rail; (3) single-ended→balanced conversion for U2's in-amp inputs (good CMRR);
(4) the **band-defining bandpass** (~300 Hz–3.4 kHz) bracketing the 2435 Hz
Larmor line, rejecting sub-300 Hz drift/hum and >3.4 kHz junk (incl. the
near-Nyquist oscillation class seen on the other amp).

**Only action:** add an explicit no-connect (×) flag on pin 2 to silence ERC.
**Bench note:** a 600 Ω secondary into a high-Z in-amp input is lightly damped
and may peak/ring around the band. Usually desirable (sharpens the 2.4 kHz
bandpass); if it rings on a scope, add a ~10–100 kΩ damping resistor across the
secondary (pins 4–6).

### 4. Decoupling placement (EMC DC-001/DC-003)
The schematic decoupling is correct (10 µF + 100 nF per rail on all three ICs).
But the layout places several 100 nF caps (C20–C25) **far from the IC pins and
far from a stitching via**. On a 3.8 M-gain board, a long decoupling return loop
is a classic HF-instability path — the same oscillation class you just measured
on the AliExpress amp. **Action:** pull C20–C25 hard against each IC's V+/V−
pins and drop a ground via immediately at each cap.

---

## Medium — good practice

- **Ground plane — RESOLVED.** User confirmed (PCB image) the GND pour is
  **continuous across the whole board** (both layers, filled, unbroken under
  U1/U2/T1/U3 and the input traces), brought out to the system at a single
  through-hole `J8 "1 GND"`. The single external tie is good practice for a µV
  front-end (star ground — one entry point avoids ground loops with the rest of
  the instrument). One thing to keep healthy: the *inter-layer* stitching
  between the top and bottom pours — the analyzer found 6 GND vias; make sure a
  few of them sit **right at each IC's ground pin and beside each decoupling
  cap** (see item 4) so return currents have a short local path between layers,
  not just the one external tie. Not a slot/continuity problem — a
  via-distribution nicety.
- **Courtyard overlap C13 ↔ U1 (PM-001, 0.57 mm²).** Nudge them apart.
- **U3 datasheet/name mismatch.** Value `OP177G` (ADI precision op-amp), symbol
  `DQM:OPA177G` (TI naming), but the attached datasheet URL points to the
  **OP279** (a different, rail-to-rail part). Cosmetic, but fix the link so the
  next reviewer isn't misled.
- **R4 value mismatch** schematic `10.2K 1%` vs PCB `10.2K` (XV-002). Harmless;
  re-sync.

---

## What's good (keep it)

- **Layout topology is well suited to high gain:** strict left→right flow —
  J2 in (x≈48) → cap bank/SW1 → U1 → T1 → U2 → U3 → P2 out (x≈167), ~**119 mm
  input-to-output separation.** Gross output→input feedback coupling is
  unlikely. Nicely done.
- **Transformer between the two ×~1958 stages breaks the DC gain chain** — U1's
  offset (×~2000) can't cascade into U2. The 3.8 M gain exists only in the
  transformer's AC passband (~2.3 kHz). This is the right way to build it.
- **Full per-rail decoupling** (10 µF bulk + 100 nF HF) on all three ICs.
- **Output limiter:** U3 (OP177) is a unity-gain inverter with anti-series
  9.1 V zeners (D1/D2) clamping the output to ≈±9.8 V — protects the ADC.
  ngspice confirms gain = −1.0 (0 dB).
- **The tuning cap bank is on this board.** C1–C12 (0.001–0.56 µF) are switched
  by SW1 *across the coil/inputs* — i.e. your LC-tank tuning cap is here and
  selectable. Max ≈0.61 µF matches the Larmor-tuning calc. (So "do the tuning"
  = pick the right SW1 combination, not add external parts.)

---

## Not performed / limits

- **Datasheet verification:** not done — no MPNs, no `datasheets/`, no DigiKey
  creds. All pin/gain claims are consistency-only. **Blocker 1 is unresolved
  until you supply the U1/U2 part number.**
- **Thermal:** N/A — all three ICs dissipate <0.1 W; not thermally limited.
- **Lifecycle/obsolescence:** not done — needs MPNs + network.
- **Gerbers:** none present in the project.
- **SPICE:** only U3 was auto-simulatable (transformer-coupled in-amp stages
  can't be simulated from detected subcircuits). It passed.

---

## Top 3 actions, in order
1. Read the U1/U2 chip top-mark and confirm the **actual part + pinout** (Blocker 1).
2. Add **input bias-return resistors** to GND, unless the coil already grounds
   the common mode (Blocker 2).
3. Tighten **C20–C25 decoupling** to the IC pins with a via at each (High 4).

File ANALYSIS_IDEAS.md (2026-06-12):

# Analysis & Pulse-Program Ideas

Ideas for extending the PPM's signal analysis, with implementation status.

The current pipeline (as of June 2026): normalise → Butterworth bandpass →
Hann-windowed periodogram (averaged over runs, optionally
background-subtracted) → peak detection with parabolic sub-bin interpolation →
field + SNR report.  Plus the block-RMS envelope/T2 fit in
`PPMCalc.plotAmplitudeEnvelope()`.

Context for the numbers below: at 16 000 Hz for 1.5 s the FFT bin width is
~0.67 Hz, which corresponds to ~16 nT.  That was the resolution floor until
peak interpolation (§1.1) was added; the remaining items in §1 push toward
the Cramér–Rao limit, which is far below one bin.

## Status at a glance

| Item | Section | Status |
|---|---|---|
| Parabolic peak interpolation | §1.1 | ✅ Implemented |
| Hann windowing | §2.5 | ✅ Implemented |
| Per-run SNR reporting | §3.1 | ✅ Implemented |
| Background acquisition (`BKGND`) | §4.1 | ✅ Implemented |
| Background spectral subtraction | §2.4 | ✅ Implemented |
| Hilbert envelope / phase-slope estimation | §1.2 | Next up |
| Zero-phase SOS filtering | §2.1, §2.2 | Next up (with §1.2) |
| Decaying-sinusoid time-domain fit | §1.3 | Planned |
| Zero-crossing counting | §1.4 | Planned |
| Spectrogram diagnostics | §1.5 | Planned |
| Mains harmonic notching | §2.3 | Superseded in practice by §2.4 |
| Matched (exponential) windowing | §2.5 | Planned |
| Lorentzian lineshape fit (B ± σ) | §3.2 | Planned |
| Cross-run statistics / Allan deviation | §3.3 | Planned |
| IGRF sanity check | §3.4 | Planned |
| Robust normalisation | §3.5 | Planned (small fix) |
| T1 measurement sweep | §4.2 | Planned (Pi-side only) |
| Delay sweep | §4.3 | Planned (Pi-side only) |
| Continuous logging mode | §4.4 | Planned |
| Polarity alternation / phase cycling | §4.5 | Idea (needs H-bridge hardware) |
| Earth's-field NMR pulse sequences | §4.6 | Out of scope |
| Timer-paced ADC sampling | §5 | Planned (firmware) |

---

## 1. Better frequency estimation (beyond the raw FFT peak)

### 1.1 Parabolic interpolation of the FFT peak  *(cheapest win — IMPLEMENTED)*

> Implemented as `PPMCalc.interpolate_peak()`; applied in both
> `PPMCalc.doFFT()` and `ppmrun.analyse()`.

Fit a parabola (or Gaussian) through the peak periodogram bin and its two
neighbours; the vertex gives a sub-bin frequency estimate. Typically 10–50×
better precision than the bin centre, for a few lines of code in
`PPMCalc.doFFT()`:

```python
# y1, y2, y3 = den at bins k-1, k, k+1
delta = 0.5 * (y1 - y3) / (y1 - 2 * y2 + y3)   # offset in bins, |delta| < 0.5
f_est = f[k] + delta * (f[1] - f[0])
```

### 1.2 Hilbert-transform phase-slope estimation

Take `scipy.signal.hilbert` of the bandpassed signal, unwrap the instantaneous
phase, and fit a straight line of phase vs. time — the slope is 2πf. For a
single decaying sinusoid in noise this approaches the Cramér–Rao bound and is
the standard technique in modern PPM firmware.

Bonus: the magnitude of the analytic signal is a **per-sample amplitude
envelope** — a much better input to the T2 exponential fit than the 31 ms
block-RMS currently used.

Caveat: phase-based methods care about filter phase distortion, so this path
needs zero-phase filtering (see §2.2). Also restrict the phase fit to the
early, high-SNR part of the record (e.g. while the Hilbert envelope is above
2–3× the noise floor) — once the signal decays into noise the phase walks
randomly and degrades the fit.

### 1.3 Direct nonlinear fit of a decaying sinusoid

Fit the time-domain model

    s(t) = A · exp(−t/τ) · sin(2πft + φ) + C

with `scipy.optimize.curve_fit`, seeded by the FFT peak (f) and Hilbert
envelope (A, τ). This is the statistically optimal estimator and returns
f, T2*, and amplitude **with uncertainties** in a single fit.

### 1.4 Zero-crossing / period counting

The classic commercial-PPM technique: count N zero crossings of the filtered
signal over a measured elapsed time, f = N / (2·T). Simple and robust, and a
good cross-check against the spectral estimate — disagreement between the two
is itself a useful data-quality flag.

### 1.5 Spectrogram (STFT)  *(diagnostic gold)*

Plot frequency vs. time over the record with `scipy.signal.spectrogram`:

- clean precession → a single horizontal ridge decaying in brightness;
- field gradients across the bottle → a broadened ridge (shortened T2*);
- field changing mid-measurement → a drifting ridge;
- interference → ridges that **don't** decay.

A ~15-line `plotSpectrogram()` method on `PPMCalc` would make most hardware
problems visible at a glance.

---

## 2. Filtering improvements

### 2.1 Second-order sections

An order-5 bandpass in `(b, a)` transfer-function form at fs = 16 kHz is on
the edge of numerical stability. Use `butter(..., output='sos')` +
`scipy.signal.sosfilt` — drop-in replacement, numerically safe at any order.

### 2.2 Zero-phase filtering

`sosfiltfilt` instead of `lfilter`. Phase doesn't matter for the periodogram
(as the current code notes), but it **does** matter for the Hilbert
phase-slope and time-domain-fit methods (§1.2, §1.3). `filtfilt` also removes
the filter's startup transient from the front of the record, which currently
eats some of the highest-SNR early samples.

### 2.3 Mains harmonic notching

**The 49th harmonic of 50 Hz is 2450 Hz — essentially on top of the expected
Larmor frequency (~2435 Hz at 57 µT).** The bandpass cannot reject it.
Options:

- `scipy.signal.iircomb` at 50 Hz (notches every harmonic), or individual
  `iirnotch` filters at 2400 / 2450 / 2500 Hz;
- but a notch exactly at f_L costs signal, so the better mitigation is usually
  background subtraction (§2.4 — now implemented, making explicit notching
  largely unnecessary; revisit only if non-stationary interference appears
  that subtraction cannot remove).

### 2.4 Background spectral subtraction  *(IMPLEMENTED)*

Record a background run in the same session (no sample, or no polarise pulse —
see §4.1) and subtract its periodogram from the measurement periodogram.
Amplifier noise and mains interference are stationary across the two; the
precession peak is not. This suppresses the harmonic comb without touching the
signal. Existing recordings such as `nosample.dat` / `newamp_no_sample.dat`
can be used as the background via `--background-input`.

> Implemented: `--background-runs N` collects coil-off acquisitions before
> the measurement runs; `--background-input FILE` uses an existing recording
> (works in `--input` re-analysis mode too).  The background spectrum is
> rescaled to the measurement noise floor (median per-bin ratio over the
> analysis band) and subtracted before peak detection; SNR is still reported
> against the unsubtracted floor.  See `ppmrun.subtract_background()`.

### 2.5 Windowing / matched weighting  *(Hann window IMPLEMENTED)*

- `sig.periodogram(..., window='hann')` reduces spectral leakage from the
  record edges. *(Now used by `PPMCalc.doFFT()` and `ppmrun.analyse()`.)*
- Better still for a decaying signal: weight the data by the expected
  `exp(−t/τ)` envelope (a *matched* window). Maximises peak SNR at the cost of
  some linewidth.

---

## 3. Characterising the data (quality metrics worth reporting)

### 3.1 Per-run SNR  *(IMPLEMENTED)*

Peak power divided by the median PSD in a sideband (e.g. ±100–300 Hz away from
the peak). Reporting this on every run makes thresholds like
`--fft-threshold` self-calibrating, and lets the code declare "no signal"
explicitly instead of returning the tallest noise spike.

> Implemented as `PPMCalc.estimate_snr()`; `ppmrun.analyse()` logs the SNR of
> every run and the final report includes the averaged-spectrum SNR in dB.

### 3.2 Lorentzian lineshape fit

A free-induction decay has a Lorentzian spectral lineshape with
FWHM = 1/(π·T2*). Fitting it gives centre frequency, linewidth, and amplitude
with a covariance matrix — so the result can be reported as **B ± σ in nT**,
not just B. A linewidth much wider than the envelope-fit τ predicts indicates
field gradients across the bottle (a coil-geometry/positioning problem that
can be acted on).

### 3.3 Cross-run statistics & Allan deviation

With `--runs N`, also report the per-run frequency estimates and their
scatter — the standard deviation across runs is the real-world repeatability.
For long sessions an Allan deviation plot distinguishes white noise (more
averaging helps) from drift (it doesn't), and tells you the optimum averaging
time.

### 3.4 IGRF sanity check

The expected field at a given lat/long is a one-call lookup (e.g. the
`ppigrf` package). Flag any peak more than a few µT from the IGRF prediction —
this automatically catches interference masquerading as signal.

### 3.5 Robust normalisation  *(small fix)*

The max–min normalisation in `PPMCalc.__init__` is fragile: a single transient
spike (e.g. residual coil kick) sets the scale for the whole record.
Normalising by the standard deviation is more robust and changes nothing else
downstream.

---

## 4. Pulse programs

The firmware implements two sequences: the full measurement cycle
(polarise → settle → sample, `EXECU`) and the background acquisition
(sample only, `BKGND`, §4.1).  The existing command set already supports
several further "programs" orchestrated entirely from the Pi, plus a couple
needing firmware or hardware changes.

### 4.1 Background acquisition  *(IMPLEMENTED)*

A sample-only mode that skips the polarise phase entirely. Companion to
spectral subtraction (§2.4), and a clean noise-floor characterisation of the
amplifier chain.

> Implemented as the dedicated firmware command `BKGND`: sample + transmit
> only, coil never energised, no settle delay or cool-down (queued like EXECU
> if received during cool-down).  On the Pi side,
> `PPMRun.doMeasurement(background=True)` triggers it.

### 4.2 T1 measurement  *(Pi-side only)*

Sweep `--on-time` (e.g. 0.5, 1, 2, 4, 8 s) and fit signal amplitude vs.
polarise time to `A·(1 − exp(−t/T1))`. Answers whether 6 s of polarisation is
actually buying anything for the sample in use, and is a good figure of merit
when comparing samples (tap water vs. doped water, etc.).

### 4.3 Delay sweep  *(Pi-side only)*

Sweep `--delay` downward to find how early sampling can start before the coil
transient saturates the ADC. The early signal is the strongest — every 100 ms
of unnecessary delay costs roughly `exp(−0.1/τ)` of amplitude, significant
when T2* is short.

### 4.4 Continuous logging mode  *(Pi-side)*

Repeat cycles indefinitely, appending a timestamped `(time, B, σ_B, SNR)` row
to a CSV per cycle. This turns the instrument from a one-shot device into a
magnetometer that can see diurnal field variation and magnetic storms —
arguably the most rewarding payoff for a PPM — and is what makes the Allan
deviation analysis (§3.3) meaningful.

### 4.5 Polarity alternation / phase cycling  *(hardware + firmware)*

With an H-bridge coil driver, alternating the polarisation direction flips the
sign of the precession signal but not of coherent interference; subtracting
consecutive pairs cancels the interference. A bigger project, but the
canonical PPM trick for noisy/urban environments.

### 4.6 True Earth's-field NMR sequences  *(out of scope, for reference)*

Spin echoes and 90° AC pulses would allow measuring real T2 rather than T2*,
but require an audio-frequency excitation coil and transmit chain — a
different instrument, really. Noted here as the boundary of what a
polarise-and-listen PPM can do.

---

## 5. Firmware note: timer-paced sampling

`recordSignal()` free-runs the ADC loop with no pacing — the RTC interrupt
measures the *average* rate, but per-sample jitter (e.g. the RTC ISR firing
mid-loop) acts like phase noise and broadens the spectral line. Timer-paced
sampling (wait on a timer compare flag before each conversion) makes the
sample spacing uniform. Worth doing before chasing sub-bin
frequency-estimation gains (§1), since jitter sets a floor on what those
methods can achieve.

---

## Suggested priority order

1. ~~**Parabolic peak interpolation + per-run SNR + Hann window** (§1.1, §3.1,
   §2.5) — an afternoon's work, large precision win.~~ **Done.**
2. ~~**Background acquisition pulse program + spectral subtraction** (§4.1,
   §2.4) — the best interference fix given the 2450 Hz mains harmonic.~~
   **Done.**
3. **Hilbert envelope / phase-slope analysis** (§1.2) with zero-phase SOS
   filtering (§2.1, §2.2).
4. **Continuous logging mode** (§4.4) with cross-run statistics (§3.3).
5. Everything else as interest and hardware time allow.

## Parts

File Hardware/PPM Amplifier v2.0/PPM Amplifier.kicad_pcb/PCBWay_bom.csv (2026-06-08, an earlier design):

Designator | Quantity | Value | Footprint | Package | MPN | DNP | Mount_Type | Description
C1 | 1 | 0.56uf | C_0805_2012Metric_Pad1.18x1.45mm_HandSolder |  |  |  | smt | Unpolarized capacitor
C10 | 1 | 0.0039uF | C_0805_2012Metric_Pad1.18x1.45mm_HandSolder |  |  |  | smt | Unpolarized capacitor
C11 | 1 | 0.0022uF | C_0805_2012Metric_Pad1.18x1.45mm_HandSolder |  |  |  | smt | Unpolarized capacitor
C12 | 1 | 0.001uF | C_0805_2012Metric_Pad1.18x1.45mm_HandSolder |  |  |  | smt | Unpolarized capacitor
C13, C14 | 2 | 10uF | CP_Elec_5x3 |  |  |  | smt | Polarized capacitor, small symbol
C15 | 1 | 100nf | C_0805_2012Metric_Pad1.18x1.45mm_HandSolder |  |  |  | smt | Unpolarized capacitor, small symbol
C16 | 1 | 100nF | C_0805_2012Metric_Pad1.18x1.45mm_HandSolder |  |  |  | smt | Unpolarized capacitor, small symbol
C17 | 1 | 1uF | C_0805_2012Metric_Pad1.18x1.45mm_HandSolder |  |  |  | smt | Unpolarized capacitor, small symbol
C2 | 1 | 0.39uF | C_0805_2012Metric_Pad1.18x1.45mm_HandSolder |  |  |  | smt | Unpolarized capacitor
C3 | 1 | 0.22uF | C_0805_2012Metric_Pad1.18x1.45mm_HandSolder |  |  |  | smt | Unpolarized capacitor
C4 | 1 | 0.1uF | C_0805_2012Metric_Pad1.18x1.45mm_HandSolder |  |  |  | smt | Unpolarized capacitor
C5 | 1 | 0.056uF | C_0805_2012Metric_Pad1.18x1.45mm_HandSolder |  |  |  | smt | Unpolarized capacitor
C6 | 1 | 0.039uF | C_0805_2012Metric_Pad1.18x1.45mm_HandSolder |  |  |  | smt | Unpolarized capacitor
C7 | 1 | 0.022uF | C_0805_2012Metric_Pad1.18x1.45mm_HandSolder |  |  |  | smt | Unpolarized capacitor
C8 | 1 | 0.01uF | C_0805_2012Metric_Pad1.18x1.45mm_HandSolder |  |  |  | smt | Unpolarized capacitor
C9 | 1 | 0.0056 | C_0805_2012Metric_Pad1.18x1.45mm_HandSolder |  |  |  | smt | Unpolarized capacitor
D1, D2 | 2 | 9.1V | D_DO-41_SOD81_P7.62mm_Horizontal |  |  |  | tht | Zener diode
J1 | 1 | Power In | PinHeader_1x03_P2.54mm_Vertical |  |  |  | tht | Generic connector, single row, 01x03, script generated (kicad-library-utils/schlib/autogen/connector/)
J2 | 1 | Signal In | PinHeader_1x03_P2.54mm_Vertical |  |  |  | tht | Generic connector, single row, 01x03, script generated (kicad-library-utils/schlib/autogen/connector/)
J3 | 1 | TP1 | PinHeader_1x02_P2.54mm_Vertical |  |  |  | tht | Generic connector, single row, 01x02, script generated (kicad-library-utils/schlib/autogen/connector/)
J4 | 1 | TP2 | PinHeader_1x02_P2.54mm_Vertical |  |  |  | tht | Generic connector, single row, 01x02, script generated (kicad-library-utils/schlib/autogen/connector/)
J5 | 1 | TP3 | PinHeader_1x02_P2.54mm_Vertical |  |  |  | tht | Generic connector, single row, 01x02, script generated (kicad-library-utils/schlib/autogen/connector/)
J6 | 1 | Power LED | PinHeader_2x01_P2.54mm_Vertical |  |  |  | tht | Generic connector, single row, 01x02, script generated (kicad-library-utils/schlib/autogen/connector/)
P2 | 1 | Signal Out | PinHeader_1x02_P2.54mm_Vertical |  |  |  | tht | Symbole general de connecteur
R1, R2 | 2 | 5.11 1% | R_0805_2012Metric_Pad1.20x1.40mm_HandSolder |  |  |  | smt | Resistor
R3, R4 | 2 | 10.2K 1% | R_0805_2012Metric_Pad1.20x1.40mm_HandSolder |  |  |  | smt | Resistor
R5 | 1 | 330 Ohm | R_0805_2012Metric_Pad1.20x1.40mm_HandSolder |  |  |  | smt | Resistor
SW1 | 1 | SW_DIP_x12 | SW_DIP_SPSTx12_Slide_6.7x32.04mm_W8.61mm_P2.54mm_LowProfile |  |  |  | smt | 12x DIP Switch, Single Pole Single Throw (SPST) switch, small symbol
T1 | 1 | 42TL016 | Transformer_42TL016 |  |  |  | tht | Transformer, single primary, split secondary
U1, U2 | 2 | ~ | SOIC-16W_7.5x10.3mm_P1.27mm |  |  |  | smt
U3 | 1 | OP177G | DIP-8_W7.62mm_LongPads |  |  |  | tht | Single Rail-to-Rail High Output Current Operational Amplifiers, SOIC-8

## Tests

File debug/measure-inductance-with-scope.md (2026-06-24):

# Measuring Sensor-Coil Inductance with an Oscilloscope

Goal: measure the sensor coil's inductance (L ≈ 7 mH expected: two ~3.5 mH
coils in series) using a scope + signal generator, independent of the LC meter.
The scope measures *frequency* far more accurately than a cheap LC meter
measures inductance (the Siglent even has a hardware frequency counter), so the
resonance method below sidesteps the LC meter entirely and gives the number we
actually care about for tuning the tank.

---

## Method 1 (recommended): LC ring-down

Hang a known capacitor across the coil to form a tank, "kick" it with a square
wave, and read the ringing frequency. L falls straight out of the resonance
formula.

```
  SigGen ──[ R_s 4.7k ]──┬──────────┬──── scope CH1 (x10 probe)
  square wave            │          │
   ~100 Hz, few Vpp     ═══ C      ███ L   (sensor coil ≈ 7 mH)
                         0.1 µF      ███
   SigGen GND ───────────┴──────────┴──── scope GND
```

- **C**: a film cap (polypropylene/polyester) you trust — measure it first or
  use its nominal. 0.1 µF puts the ring at ~6 kHz (plenty of cycles to read).
- **R_s ≈ 4.7 kΩ**: isolates the generator's 50 Ω so it doesn't damp the tank.
  Value isn't critical.
- **Drive**: square wave, ~100 Hz, a few volts. Each edge is a step that excites
  the tank; it rings and decays before the next edge.

**Read it:** AC-couple the scope, trigger on the ring, measure one ringing
period T (or let the hardware counter / an FFT give f0 directly). Then:

    L = 1 / [ (2π f0)² · C ]

**What to expect** if L really is 7 mH and C = 0.1 µF: **f0 ≈ 6.0 kHz**.
Quick gut check: 7 mH × 0.1 µF → 6.0 kHz; read 5 kHz → L ≈ 10 mH; 7 kHz → ≈ 5 mH.

**Bonus — Q for free:** count how many cycles it takes for the ring envelope to
decay to ~37% of its initial amplitude; **Q ≈ π × (that cycle count)**. At 6 kHz
expect ~14 cycles (Q rises with frequency, so this won't equal the Q≈18 at
2435 Hz — that's fine).

**Double bonus:** swap in the candidate **tuning cap (~0.56–0.62 µF)** and the
ring should land at **~2435 Hz** — confirming L, the cap value, and the tuning
calc all at once.

---

## Method 2 (no cap, cross-check): RL time-constant

Independent number with no capacitor:

```
  SigGen ──[ R 100Ω 1% ]──┬──── scope CH1 (across coil)
  square wave 1 kHz       ███
   ~5 Vpp                 ███ L (coil)
                          │
  GND ────────────────────┴────
```

Probe **across the coil**: at each edge the voltage jumps up, then decays
exponentially to ~0 with τ = L / (R + R_coil + 50 Ω). Measure τ (the 37% point
of the decay), then:

    L = τ · (R + R_coil + 50)

With R = 100 Ω and R_coil ≈ 5.9 Ω, expect **τ ≈ 45 µs** for 7 mH. Use ~20 µs/div.
Less precise than resonance (time-constant reads are softer, and you need
R_total accurately) — treat it as the sanity cross-check. If both methods agree,
the LC meter was fine; if they agree with each other but not the meter, trust
these.

---

## Accuracy notes

- Resonance accuracy is limited by **cap tolerance**: L ∝ 1/C, so ±5% cap →
  ±5% L. Use a film cap and, if possible, measure it (capacitance ranges on
  cheap LC meters are usually more trustworthy than the inductance ranges).
  Measuring 2–3 caps and averaging tightens it.
- Use a **x10 probe** so probe capacitance (~100 pF) doesn't perturb a 0.1 µF
  tank — negligible here, but good habit.
- Measure with the coil in its **final wiring** (both sensor coils in series, as
  used) so you get the real 7 mH the tank will see, not one coil.

---

Reference values:
- Sensor coils: 22 AWG, 552 turns, ~3.5 mH each, ~5.9 Ω incl. cable; two in
  series-opposition → L ≈ 7 mH total.
- Target tuning: f0 = 2435 Hz (local field 57198 nT, Larmor ≈ 2435 Hz)
  → C ≈ 0.61 µF, Q ≈ 18, BW ≈ 135 Hz.

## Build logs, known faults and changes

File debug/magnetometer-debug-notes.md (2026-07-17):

# Proton Precession Magnetometer — Debugging Notes

Source: *Signals from the Subatomic World: How to Build a Proton Precession
Magnetometer* (Stefan & J. Richard Hollos, Exstrom Laboratories, ©2008) —
file `signalsfromsubatomicworld.pdf` in /Users/que/Documents/EBooks.

Generated from a debugging discussion on 2026-06-03.

---

## ⇒ START HERE — CURRENT STATUS & TOP NEXT STEP (as of 2026-06-25)

> **UPDATE 2026-06-25:** the E–W horizontal orientation has now been tried (one
> point of the sweep). Still no FID — and it revealed the rig is **MAINS-LIMITED**
> (a 50 Hz harmonic comb dominates, with 2350/2450 Hz lines sitting right where
> the basalt Larmor likely is). **The immediate top priority is now to REDUCE
> MAINS PICKUP** (move outdoors/away from the building, battery-power everything,
> use `--background-runs`), *then* resume the orientation sweep below. See the
> 2026-06-25 follow-up for detail. The orientation reasoning still stands — E–W
> was just one angle, and on basalt the true perpendicular may need azimuth/tilt
> tweaks — but every angle is mains-limited until the interference is tamed.

**The whole signal chain is verified EXCEPT one link.** Everything below has been
tested and exonerated over this log:

- **Polarization** — 8.6 A coil current, ~90 G field (compass + Hall sensor),
  fast **non-adiabatic quench ~120 µs** ≪ the 411 µs Larmor period (6/12, 6/23). ✓
- **Sensor-coil cancellation** (series-opposition gradiometer) — spatial-null
  test passes (6/13). ✓
- **Amplifier** — book INA217 amp restored; the chronic 7.7 kHz oscillation is
  gone (6/21). ✓
- **Acquisition → FFT → frequency/field calibration** — an injected sig-gen tone
  is detected at the right frequency and back-calculates the right field, 52–60 dB
  SNR (6/13, 6/21). ✓
- **Sensor tank resonance** — measured L ≈ 5.4 mH, low Q ≈ 5 (BW ≈ 500 Hz),
  tunable via the SW1 bank (6/19, 6/21). ✓

**The one untested link = is a real precessing magnetization actually being
generated and presented to the sensor?** None of the above tests touch this, and
it comes down almost entirely to **ORIENTATION**.

### TOP NEXT STEP: empirically find the coil orientation

Signal ∝ the angle θ between the coil axis and the **local** field — **maximal
when the axis is perpendicular to the field, exactly ZERO when parallel**
(≈ sin²θ). This is the only remaining *all-or-nothing* variable: it can null the
signal to zero with perfect electronics, which is exactly the "works, but same
with/without sample" symptom. After the non-adiabatic quench the magnetization
points along the old polarizing axis; only its component transverse to Earth's
field precesses, so an axis near parallel to the field detects nothing.

**⚠ GEOMETRY TRAP — "tilt to 68°" may be aligning the axis ALONG the field
(zero signal).** The rule is *axis ⊥ field*. The field points magnetic-north and
dips ~68.5° below horizontal, so the field *line* runs S-and-up at 68.5°. Pointing
the coil **south, tilted up ~68.5°** lays the axis right along that line →
antiparallel to B → sin²θ ≈ 0 → **no precession**, with perfect electronics. The
correct meridian-plane tilt is the *complement*: axis at **(90° − I) ≈ 21.5° from
horizontal** (= 68.5° from vertical), NOT 68.5° from horizontal. "Tilt to the
inclination" is the classic mis-statement that flips exactly this — check whether
the rig's 68° was measured from horizontal or vertical.

**FOOLPROOF FIX — point the axis horizontal, magnetic EAST–WEST.** The field lies
in the N–S vertical (meridian) plane, so it has **zero E–W component**; therefore
*any horizontal axis pointing magnetic E–W is automatically ⊥ to the field*
(θ = 90°, the optimum) **regardless of the inclination**. Set the coil axis
horizontal, perpendicular to the compass needle. No inclination number needed,
and immune to the basalt anomaly in the *dip*. **Try this first.**

**Basalt twist — do NOT trust the 68°35′ model inclination.** That angle is from
the IGRF *model*; the 2380 Hz line already shows the local field is offset
~1000+ nT from the model (basalt crustal anomaly), and a crustal anomaly tilts
the field *direction* too, not just its magnitude. **Find the right tilt by
experiment, not calculation** — and cross-check the local dip independently:
- **Dip needle / dip circle** — magnetised needle on a *horizontal* pivot swinging
  in the meridian plane settles at the true local inclination (anomaly included).
  Cheap to build (needle + low-friction axle + protractor). The classic
  independent inclination measurement.
- **Smartphone 3-axis magnetometer app** — reads the field vector incl. dip;
  crude (±few µT, needs figure-8 calibration, keep away from metal) but free and
  genuinely independent; enough to flag a gross anomaly.
- On basalt the rock can deflect the **compass itself** — check magnetic north
  from two spots a few metres apart; if the needle swings, lean on the on-rig
  max-signal sweep, not a single compass reading.
- (Declination needs an independent *true* north — shadow at solar noon, Polaris,
  or a GPS-tracked straight line — but the rig doesn't need it; the compass needle
  already gives the local horizontal field direction the E–W trick uses.)

How:
1. Start from the **E–W horizontal** axis above. Then take a `sample` + matched
   `no-sample` pair at a grid of tilts around it (≈ ±30° in ~10–15° steps; add a
   couple of azimuths if the platform allows) to map the response.
2. At each, run `Software/RPiPythonCode/compare_runs.py --per-run` and **search
   WIDE in frequency (~2200–2600 Hz)** — hunt for the one peak that is *both*
   sample-dependent *and* decaying (per-run decay ≫ 1 at a stable freq), wherever
   it lands.
3. The orientation where that decaying, sample-only peak emerges/maximizes is the
   answer — and it simultaneously gives you the true local field *direction*
   (worth having, since the model value is untrustworthy on basalt).

**Stack the cheap signal-maximizers first** so the sweep has something to show:
- **Fill the sensor coil bore** (filling factor, ~3–5× / 10–14 dB) — conformal bag
  per the 2026-06-13 "Sample volume / filling factor" entry; **one coil only**
  (gradiometer).
- **Keep DELAY short (~150 ms)** — longer only loses FID to T2\* decay (basalt
  gradients likely shorten T2\*); see the 6/24 addendum's delay analysis.
- Distilled/degassed, bubble-free water; non-magnetic everything.

**If a full orientation sweep still shows nothing** → the remaining axis is raw
signal strength / dephasing: T2\* too short from basalt gradients (try a *smaller*
sample in the most homogeneous part of the bore — trades filling factor for line
width), or polarization not uniformly covering the sample. Second-order; settle
orientation first.

*(Rationale and the supporting measurements are in the 2026-06-24 follow-up +
addendum below. Tools: `compare_runs.py` for sample-vs-no-sample overlays,
`suppress_resonance.py` to peel the steady tank line once a co-located signal is
suspected.)*

---

## The symptom

> "I get the same signal whether or not there's a sample in the coil. The
> value depends on which capacitors are selected via the DIP switch."

## What that symptom means

The thing whose amplitude tracks the DIP switch is the **LC tank resonating**,
not the proton signal:

- Sample/canceling coils (L ≈ 2 × 3.5 mH ≈ 7 mH) + the selected capacitor form
  a resonant circuit at **f = 1/(2π√LC)**.
- Change the cap → change resonant frequency → change how the ~3.8-million-gain
  amplifier responds to whatever broadband energy is around. This happens with
  or without a sample, because it has nothing to do with protons.

The **real** proton precession signal is different:
- A *transient* that decays over ~1–3 s (free induction decay).
- *Differential* — only appears because the bottle is in ONE of the two coils.
- *Microvolts* — invisible without the Chapter 7 processing.
- Only visible **after** bandpass filter + FFT.

Book's own go/no-go test (p. 108): take an FFT WITH the sample and one WITHOUT;
the proton peak should appear/disappear. "Same with/without" means we're seeing
background (tank ringing or oscillation), **not** precession. So the real
question is *"why is there no precession signal underneath the background?"*

Two failure classes: **(A) not measuring the right thing**, and **(B) not
generating a precession signal at all.**

---

## Decisive test #1: short the amplifier input

Disconnect the coils, **short the amp input**, run a normal acquisition + FFT.

- Output still tuned & tracks the DIP switch  → amplifier + tank loop is
  **self-oscillating** (3.8M gain + resonant input near a resonant audio
  transformer → huge loop gain at the tank frequency if input couples to
  output). This fits the symptom perfectly. Fix = §5.5 layout rules: input one
  end / output the other, short leads, full ground plane, and if needed a
  grounded tin/copper wall physically separating input from output.
- Output goes quiet  → amp is fine; problem is upstream (polarization /
  geometry — see checklist 3–4).

## Decisive test #2: plot the time-domain data (not just a number/FFT)

- Constant amplitude, never decays  → amplifier **oscillation**.
- Fast decay (tens of ms), sample-independent  → harmless **tank ring-down**
  from the switching transient (should be ~gone after the 0.1 s trigger delay).
- Slower decay over ~1–2 s, present ONLY with the sample  → that's the real
  **FID**. 

---

## Prioritized debug checklist

1. **Confirm detection method (cheapest first).** Are you reading a raw scope
   amplitude / single number, or the with-vs-without-sample FFT comparison?
   The µV signal is invisible without averaging + 6th-order Butterworth
   bandpass (≈2100–2400 Hz) + FFT, after dropping the first ~2000 transient
   points. Always compare TWO FFTs (sample vs no-sample).

2. **Rule out amplifier oscillation** — the input-short test above. Top suspect
   given the exact symptom.

3. **Verify polarization is actually happening** (no polarization → no signal):
   - **Easiest check first — the built-in indicator LED.** The pulse controller
     has a 2N3906 + LED on AT90S2313 pin PB0 that lights *whenever polarization
     current is applied to the coil* (book p.38). Watch it during a pulse: no
     light → the pulse/firmware/serial command isn't driving the coil and
     there's nothing to detect. Light → current is at least being commanded.
   - Measure current through the **polarizing coil** during the pulse — design
     value ~9.6 A (12 V Meanwell ÷ [1.1 Ω coil + 0.15 Ω MOSFETs]). Clamp meter
     or scope the coil voltage.
   - Scope the **turn-off** across the polarizing coil — must collapse fast &
     clean. Design quenches ~10 A with a ~270 V flyback, which across L=4.3 mH
     gives dI/dt = 270/0.0043 ≈ 63 A/ms → current gone in ~160 µs. Too-slow
     (adiabatic) cutoff → magnetization just follows the field down → ZERO
     precession; the book states this explicitly in Ch3.1. Watch for
     MOSFET-heating slowdown (on-resistance rises with temp → current drops →
     weaker signal over long pulse trains; p.35 + Ch7.1.2).
   - Use a real pulse length (worked example uses 6 s) and confirm the pulse
     sequence + 0.1 s trigger delay are firing.

4. **Verify geometry & orientation (a top cause of a dead null):**
   - Sample bottle in ONE sensor coil only; sensor coils sit INSIDE the
     polarizing coil (Fig 4.6).
   - **The polarizing-coil axis MUST be ~perpendicular to Earth's field** — the
     whole point of the tiltable platform. In the N hemisphere, tilt the coil to
     the local **magnetic inclination angle** (≈65° in Longmont CO; get yours
     from IGRF/NOAA, §2.4). If the polarizing field is parallel/anti-parallel to
     Earth's field the magnetization is never knocked off-axis, so there is **no
     precession to detect** — which produces exactly the "same with/without
     sample" symptom. Re-tilt and retest a few angles around the calculated one.
   - Polarization field should be ≈75 Gauss (B≈0.0075 T) at the coil center
     (p.23); a weak field gives a weak/null signal.

5. **Verify coil cancellation wiring** (p. 60–61 test): put both coils inside
   the polarizing coil, drive the POLARIZING coil from a sig-gen at ~2 kHz.
   Amp output should be **greatly reduced** if the two coils are wound opposite
   & series-connected correctly. If it's large instead, the coils are adding
   (wired wrong) → reverse one coil's connection.

6. **Sample & environment:** deionized/distilled water, bottle full (deionized
   gives a bigger peak, p. 112). Move away from mains/motors/vehicles/rebar;
   coils on a wood/plastic stand off the ground (p. 59).

7. **Tune to the actual local frequency:** estimate field (GPS → IGRF/NOAA
   calculator, §5.7) → precession frequency → pick caps near it. This only
   *amplifies* a real signal; it can't create one (hence lower priority).

---

## Best bets

Output tracks cap selection and is sample-independent → two most likely roots:

1. **Amplifier (+ tank) self-oscillating** — input-short test settles it in
   ~5 minutes.
2. **No precession being generated** — polarization current absent, turn-off
   too slow, or polarizing coil parallel to Earth's field — *combined with*
   reading raw amplitude instead of the with/without-sample FFT.

## To narrow it down, report back:
- (a) How you currently read the "signal" — raw scope trace vs. the ADL → FFT
  pipeline.
- (b) What you see when you SHORT the amp input.
- (c) What the polarizing-coil **turn-off** waveform looks like on a scope.

---

## Update 2026-06-10 — turn-off waveforms captured (ppm_data/)

**New evidence:**
- Energized coil deflects a compass from ~600 mm → polarization field is real
  and strong. Failure class B narrows to the **turn-off**, not the pulse.
- `SDS00011.png` (no coil, 2 V/div, 5 ms/div): output decays 9.88 V → 40 mV
  over 5.4 ms (τ ≈ 1 ms). Switch opens fine; node bleed-down, nothing more.
- `SDS00012.png` (coil attached, 5 V/div, 5 ms/div): from +12 V, fast negative
  flyback spike (scope Pk-Pk > 50 V, spike too fast to render), then an
  **underdamped ring at ~41.5 Hz settling over ~24 ms**.

**Verdict — the quench is ~100× too slow.** The protons feel the *current*
(field), and current is still sloshing for ~24 ms. The Larmor period is
~0.45 ms (≈2.2 kHz), so the field decays over ~50 precession periods →
**adiabatic** → magnetization follows the field down → **zero FID**. The book
design quenches in ~160 µs (270 V across 4.3 mH), i.e. under half a precession
period. This fully explains "same signal with/without sample."

**What the 41.5 Hz ring implies:** f = 1/(2π√LC) with L = 4.3 mH →
C ≈ 3.4 mF. Millifarads = power-supply bulk capacitance, not parasitics. After
turn-off the coil is still exchanging energy with the supply's output caps —
the circuit is NOT being cleanly broken. Likewise the flyback being clamped at
~tens of volts instead of ~270 V says something is providing a current path.

**Suspects, in order:**
1. An added flyback diode / TVS / snubber across the coil or the FETs. A
   natural "protection" addition — but here the high-voltage flyback IS the
   mechanism; it must be allowed to happen. Remove it.
2. MOSFET body diodes conducting the flyback back into the supply caps —
   check the stack matches the book: 8× IRF6215 p-channel as two
   parallel-of-four banks **in series**, oriented to block ~300 V. A single
   bank (150 V) or wrong orientation clamps/recirculates.
3. FETs avalanching at low voltage (under-rated substitutes).
4. Slow gate turn-off through the 4N35 (slow opto) leaving the FETs in linear
   mode — would slow the quench but predicts a ramp, not a 41 Hz ring; lower
   probability.

**Next measurements:**
- Note where the probe was connected (across coil vs drain–ground).
- Re-capture turn-off at ~500 µs/div, single-shot, trigger on falling edge,
  to see the true spike amplitude and the first millisecond.
- **Best test: 0.05–0.1 Ω shunt in the coil's ground leg, scope across it** —
  that's the current = the field. Goal: current reaches zero in ≲0.5 ms and
  stays there.
- Inspect/remove any diode, TVS, or capacitor across the coil or FET stack.
- ⚠ **Scope safety:** shots were taken with the probe at 1X. Once fixed, this
  node swings to ~−270 V — beyond most 1X probe ratings. Use 10X.

Still open (secondary): the input-short test for amplifier self-oscillation.
The slow quench explains the *absence* of an FID; the DIP-tracking background
may additionally be amp oscillation. Both can be true.

### Follow-up 2026-06-10: probe placement confirmed + shunt sizing

**Probe was connected directly across the coil** — so the 41.5 Hz ring IS the
coil voltage, hence the coil current/field really does slosh for ~24 ms.
Diagnosis confirmed; no probe-placement ambiguity left.

This sharpens the suspect list: a cleanly opened switch with nothing across
the coil would ring at tens of kHz (nF parasitics, hundreds of volts). Seeing
41 Hz requires ~3.4 mF effectively across the coil terminals — supply-bulk-cap
scale — so during turn-off a closed loop still connects the coil to big
capacitance (clamp diode, snubber, or a topology that leaves the supply in
the loop).

**Quick checks to find the path:**
1. Power off, disconnect the coil, DMM in **diode-test mode across the board's
   coil output terminals** (both polarities): ~0.5 V either way = a diode
   across the output. Capacitance mode on the same terminals: mF-scale = bulk
   caps sitting across it.
2. Compare the pulse controller against the book's Ch. 3 schematic: high-side
   switch, 8× IRF6215 p-channel, two parallel-of-four banks in series (300 V
   blocking). A low-side N-FET variant, a single 150 V bank, or any added
   protection diode/TVS would each produce exactly the observed waveform.
   *(Asked user which MOSFETs/topology they built — answer pending.)*
3. Current-shunt capture to verify any fix.

**Shunt resistor sizing (~10 A):**
- 0.1 Ω → 10 W continuous (gives 1 V at 10 A — easy to scope);
  0.05 Ω → 5 W. The 6 s energize counts as continuous thermally — size for
  full power with headroom, don't rely on pulse ratings.
- Best DIY option: **ten 1 Ω / 2–3 W metal-film resistors in parallel** =
  0.1 Ω, 20–30 W, very low inductance.
- Or a purpose-made non-inductive power shunt (TO-220 thick-film,
  0.05–0.1 Ω, 25–50 W on a small heatsink).
- **Avoid a single wirewound ceramic-block resistor** — inductive, and the
  measurement target is a ~100 µs current edge (1 µH of shunt inductance
  fakes a spike on the edge).
- A 1–2 s energize is enough for this test (only the turn-off matters) and
  keeps the shunt cool. The added 0.1 Ω drops loop current ~8% — irrelevant
  for diagnosis; remove the shunt for real measurements later.

### Follow-up 2026-06-10 (later): MOSFET bank schematic/PCB reviewed — bank is per-book; suspicion moves to the GATE DRIVE

User added `ppm_data/MMPMosfetBankSchematic.pdf` and `PPMMosfetBankPCB.pdf`
(KiCad, "PPM Mosfet Bank", Dec 2024). **The bank matches the book's Fig 3.1
(p. 37) exactly:** 8× IRF6215; J2 "12V In" → Q1–Q4 sources; Q1–Q4 drains →
Q5–Q8 sources (mid node); Q5–Q8 drains → J3 "To Coil"; all 8 gates commoned
to J1 "Gate Out". No diode, TVS, snubber, or capacitor anywhere on the board.
PCB traces are adequately wide. **The bank board cannot by itself produce a
41 Hz / 24 ms ring — there's nothing on it but FETs.**

**Conclusion: the slow quench must come from (a) the gate drive, or (b)
damaged FETs.** Most likely (a): if the gate bus rises from ~1 V to ~12 V
slowly (ms-scale), the FETs crawl through their linear region for tens of ms,
acting as a varying resistor that keeps the coil connected to the supply's
bulk caps → exactly the observed clamped flyback + 41 Hz ring through ~3.4 mF.

**The book's gate drive (Fig 3.1, p. 36–37):** gate bus pulled up to the SAME
+12 V rail through R2 = 470 Ω; 4N35 output transistor pulls it down via
R1 = 330 Ω; AT90S2313 PB0 drives the 4N35 LED (PB0 high → opto off → gate
≈ 12 V → Vgs ≈ 0 → FETs OFF; PB0 low → opto on → gate ≈ 1 V → Vgs ≈ −11 V →
ON). Turn-off speed per book values: τ ≈ R2 × ΣCiss ≈ 470 Ω × ~15 nF ≈ 7 µs.
Anything slower than ~100 µs at the gate is a problem; ms-scale = smoking gun.

**Note:** SDS00011 (no coil, τ ≈ 1 ms decay) is ambiguous — that decay is
equally consistent with the 1 MΩ probe discharging ~1 nF of FET/cable
capacitance OR with a ~1 ms slow gate. The gate measurement resolves it.

**Decisive next measurements:**
1. **Scope the gate bus (J1, referenced to supply ground) across a turn-off.**
   Expect a clean ~1 V → ~12 V step in tens of µs. Slow ramp / RC crawl /
   wiggle → gate-drive problem found.
2. Compare the user's gate-drive circuit against book Fig 3.1 (R2 470 Ω to
   the same +12 V, 4N35, R1 330 Ω). Watch for: larger pull-up resistor, any
   capacitor on the gate bus, long unreferenced gate wiring (J1 is a single
   pin — gate return is via the power leads), or a different driver entirely.
   *(Asked user for their gate-drive schematic.)*
3. After any fix: check FETs for gate-oxide damage (DMM gate-source leakage),
   since during a proper −270 V flyback the upper bank's Vgs can be driven
   far past the ±20 V rating if the gate is held stiffly — the book's
   high-impedance 470 Ω drive lets the gate get dragged along; a stiff/buffered
   driver would not, and can punch through the oxide on the first real quench.

### Follow-up 2026-06-10 (later still): controller schematic reviewed + DMM result decoded

**DMM diode-mode across the coil terminals: ~1.1 V conducting + → −, open
− → +.** Decoded: 1.1 V ≈ two ~0.55 V body-diode drops in series — the path
J3 → Q5-8 body diodes → mid → Q1-4 body diodes → +12 rail. This (a) confirms
the two-banks-in-series wiring is real and correctly oriented, and (b) shows
**no clamp diode in the flyback direction** (− → + is open; flyback drives J3
*below* ground, and nothing conducts that way). Bank exonerated again.

**Controller (`PulseControllerSchematic.pdf`, Arduino Pro Mini based):**
MOSFET Trigger section is essentially the book's circuit: R1 = 470 Ω pull-up
from +12 V to the gate bus (J5 "MOSFET Gates"), 4N35 output transistor pulls
the bus low to turn FETs on; LED driven from +3.3 V via R2 = 100 Ω
(≈21 mA), switched by Arduino pin D4 (replaces AT90S2313 PB0). C5 = 1 µF
50 V ceramic drawn near the +12 V entry. Healthy turn-off: opto storage
(tens of µs) + Miller-limited drain slew (~40 µs) + 270 V quench (~160 µs)
→ total well under the 0.45 ms Larmor period. So *as drawn* this should work
— meaning a build/placement fault is likely. **Two specific checks:**

1. **Where does C5 actually connect on the PCB?** If it sits on the GATE side
   of R1 (gate bus to GND) instead of the +12 V rail side, turn-off slows to
   τ ≈ 470 Ω × 1 µF ≈ 0.5 ms — enough to push the quench adiabatic. Verify
   which R1 pad C5's trace ties to.
2. **Is R1 present/intact?** Power off, measure ~470 Ω from the J5 gate line
   to +12 V. If the pull-up is open/missing, the gate has NO turn-off path —
   it floats near 1 V on the FETs' Ciss when the opto lets go, FETs linger ON
   for tens of ms, and the coil stays coupled to the supply → would explain
   the entire 24 ms / 41 Hz picture (supply control-loop ringing after the
   10 A load dump, seen through still-conducting FETs).

**Gate scope shot remains decisive.** At turn-off, gate bus (J5 ref. ground):
- Clean ~1 V → ~12 V step in tens of µs (brief Miller plateau) → gate is
  fine, look elsewhere.
- ~0.5 ms RC exponential → C5 is on the gate bus.
- Stuck near 1 V for ms before drifting up → open/missing pull-up R1 (or
  opto/wiring fault).

### Follow-up 2026-06-10: prediction if the gate pull-up (R5) is 470 kΩ

Hypothesis to test by measurement: the 470 Ω gate pull-up was populated as
**470 kΩ** (yellow-violet-yellow vs yellow-violet-brown). Prediction:

- Turn-on, steady current, compass deflection, indicator LED: all unaffected
  (the opto pulls the gate low regardless of pull-up value) — matches symptoms.
- Turn-off: pull-up current only ≈23 µA → τ ≈ 470 kΩ × 15 nF ≈ **7 ms**, plus
  several ms of Miller plateau (~150 nC at 23 µA) → FETs in linear region for
  ~10–25 ms → coil stays coupled to supply bulk caps → clamped flyback +
  41 Hz/24 ms ring. **Quantitative match to SDS00012.**
- Gate scope signature: slow exponential 1 V → 12 V, τ ≈ 7 ms, Miller shelf
  near 7–8 V, settled in ~20–30 ms (vs τ ≈ 0.5 ms if C5 is on the gate bus;
  vs stuck at ~1 V if R5 is open).
- No scope needed: power off, ohms from J5 gate line to +12 V reads 470 Ω vs
  470 k directly.

### Follow-up 2026-06-11: gate bus scoped — GATE DRIVE EXONERATED; SDS00012 now in question

New data (`ppm_data/oscope_index.txt`): R1 measured **470 Ω** (photo confirms
yellow-violet-brown; 470k hypothesis dead). Gate captures:

- `SDS00013.png` (gate, no coil, 2 V/div, 20 µs/div): clean rise 2.12 V →
  12.08 V in **~29 µs**. Textbook-healthy turn-off; C5 is NOT on the gate bus,
  pull-up intact. All gate-drive failure hypotheses eliminated.
- `SDS00014.png` (gate, coil attached, 5 V/div, 50 µs/div): rise starts from
  ~1.8 V, an HF oscillation burst during the linear-region transit (classic
  parasitic oscillation of 8 paralleled FETs on a common gate bus — book
  design has no per-gate resistors; brief, probably tolerable), a coupled
  spike to ~+24 V (Vgs ≈ +12 V, within ±20 V rating), then a decaying
  **~66 kHz ring**, fully settled at 12 V by **~290 µs**.

**Why this is big:** 66 kHz is exactly the coil's natural resonance with
parasitics (4.3 mH ‖ ~1.3 nF → 67 kHz) — the signature of a coil that HAS
been cleanly disconnected. Total turn-off event ≈ 290 µs < 0.45 ms Larmor
period. As seen from the gate, **the quench looks fine.**

**Contradiction:** SDS00012 (coil voltage) showed a 41 Hz ring over 24 ms.
With the gate provably at 12 V within ~30 µs, lingering-on FETs cannot
explain that. A multi-volt 41 Hz signal across the grounded 1.1 Ω/4.3 mH
coil would imply amps of circulating current with no apparent loop.
Candidate reconciliations:
1. The 41 Hz event is the **Meanwell's load-dump recovery** (control-loop
   ring after losing 10 A — tens of Hz over tens of ms is textbook SMPS
   behavior) appearing at the coil node as a measurement artifact (1X probe,
   FET output capacitance/common-mode), with NO real coil current → quench
   is actually fine and the no-FID cause is elsewhere (amp oscillation,
   coil orientation, detection method).
2. One FET bank **avalanches** (~150–170 V; series banks don't share voltage
   equally) — clamps the flyback below the designed 270 V but still quenches
   10 A in ~250 µs → physics OK, FET stress only.
3. FETs genuinely leaky/damaged → real slow current. (Argues against: DMM
   showed open in the flyback direction; 66 kHz ring says clean break.)

**Gate low level ~2 V (vs book's ~1 V): NOT a problem.** Vgs ≈ −10 V = fully
enhanced; coil current unaffected. Level is set by the 4N35 sinking the
~21 mA pull-up current with only ~21 mA LED drive — min CTR ≈ 100 %, so it
sits at the saturation edge with Vce ≈ 1–2 V. Harmless; could drop R2
(100 → 47–68 Ω) for margin but it is not the bug.

**Decisive next measurements (current, not voltage):**
1. **Shunt capture** (0.05 Ω in the coil ground leg): one shot at
   ~100 µs/div for the quench shape, one at ~5 ms/div to check whether ANY
   41 Hz current exists. Current gone in ≲0.5 ms and staying gone =
   polarization/quench fully exonerated.
2. Re-capture coil voltage at **10X probe, ~100 µs/div, single-shot** to
   read the true flyback peak: ~270 V = per design; flat-topped ~150–170 V =
   one bank avalanching.
3. If quench exonerated → return to the amp **input-short test** and
   **polarizing-coil tilt to local magnetic inclination**, and confirm
   detection is the with/without-sample FFT comparison.

### Planned 2026-06-12: shunt capture + external-signal tests of coil/amp

Shunt resistors ordered. Plan: shunt current capture (two timebases, per
above), then external-signal exploration of the detector coils + amplifier.

**Recipes for the external-signal tests:**

1. **Don't inject a sig-gen directly into the amp.** Gain ≈ 3.8 M → the
   ±10 V limiter clips at ~2.6 µV input. A generator's minimum (~10 mV) is
   ~4000× too much. Either build a heavy divider (e.g. 10 kΩ : 1 Ω ≈
   10,000:1, mounted AT the amp input, fed with 10–100 mV), or better:
2. **Couple inductively — the book's own method (p. 60–61 cancellation
   test):** sensor coils in their normal place inside the polarizing coil;
   drive the POLARIZING coil from the sig-gen at ~2 kHz (a few hundred mV is
   plenty). Expected: amp output GREATLY reduced vs driving a single coil,
   because the opposed series coils cancel. Large output instead = coils
   adding → one coil's connections reversed. This tests coils, wiring,
   cancellation, and amp in one shot.
3. **Input-short test (the old decisive test #1):** coils disconnected, amp
   input shorted, run normal acquisition + FFT. Output still tuned/tracking
   DIP caps = amp self-oscillation (fix per §5.5 layout: input/output
   separation, ground plane, shield wall). Quiet = amp fine.
4. **Tank tuning check:** with a weak inductively-coupled tone, sweep
   1.5–2.5 kHz and confirm the response peaks where f = 1/(2π√LC) predicts
   for the selected DIP caps; verifies the cap bank does what the labels say.
5. **Fake FID end-to-end test:** gate the sig-gen to a short decaying burst
   at the expected Larmor frequency (~2.2 kHz, ~1–2 s), couple it weakly
   (small loop a meter away from the sensor coils), and run the FULL
   acquisition + Butterworth + FFT pipeline. If the pipeline can't find a
   known synthetic "FID", fix detection before chasing physics.
6. Sig-gen ground can defeat the differential/cancellation scheme — prefer
   battery-powered or transformer/loop coupling; keep the generator's ground
   clip off the amp input.

### Follow-up 2026-06-12: QUENCH EXONERATED — SDS00016 + clamp meter

New data: clamp meter on the coil lead reads **8.6 A** during the pulse
(design ~9.6 A; 12 V/8.6 A ≈ 1.4 Ω loop = coil 1.1 + FETs 0.15 + wiring —
normal; field ≈ 67 G vs 75 G design, ~10% low, harmless).

`SDS00016.png` — turn-off across the coil, 10X probe with scope channel set
1X at 10 V/div (so actual = display × 10), 50 µs/div:
- Baseline ~+11 V (coil terminal during the 8.6 A on-state).
- Turn-off: snaps to **−312 V, flat-topped for ~80 µs** = both series FET
  banks avalanche-clamping at ~156 V each — this IS the book's designed
  energy dump (their "~270 V").
- Cross-check: quench time = L·I/V = 4.3 mH × 8.6 A / 312 V ≈ **120 µs** —
  matches the waveform. Well under the 0.45 ms Larmor period.
- Afterward: small ~50–60 kHz coil-resonance ring decaying in ~150 µs, then
  FLAT. No 41 Hz, no 24 ms tail.

**Conclusions:**
- The quench is per-design; the adiabatic-turn-off theory is DEAD.
- SDS00012's 41 Hz/24 ms ring was an artifact (Meanwell load-dump recovery
  viewed with a 1X probe at slow timebase), as suspected on 6/11.
- Signal GENERATION is now verified end to end (current + quench). The
  shunt capture is now optional (one 5 ms/div shot would formally confirm
  zero post-quench current, but the case is effectively settled).
- Remaining suspects for "no FID", in test order: (1) amp self-oscillation
  → input-short test; (2) sensor-coil cancellation wiring → p.60-61
  sig-gen test; (3) acquisition/processing → fake-FID pipeline test;
  (4) **polarizing-coil tilt** — axis must be ~perpendicular to Earth's
  field (local magnetic inclination from NOAA/IGRF); wrong tilt gives this
  exact symptom with perfect electronics.

### Follow-up 2026-06-13: CANCELLATION + FULL DETECTION CHAIN VERIFIED

Two external-signal tests run (the recipes planned 2026-06-12), plus two
design calculations that follow from the results.

**Test A — sensor-coil cancellation (spatial null).** Drove a homemade test
coil (sig-gen through a 1 kΩ series load) and moved it relative to the two
sensor coils. `ppm_data/SDS00017.png`: yellow = 60 mV drive, magenta = amp
output at **2436 Hz** (hardware freq counter top-right reads 2.43621 kHz;
ignore the `1/ΔX = 694 Hz` cursor — those cursors span several cycles).
Result: a signal appears **only when the test coil is inside ONE sensor coil**;
it nulls when the coil is between them or on top of both. That is exactly the
series-opposition (gradiometer) signature — a source coupling equally to both
coils cancels. **Cancellation wiring is correct.** ✓
- Minor note: the magenta amp output is clipped/flattened on the bottom =
  output-stage DC-offset saturation at this (large) drive level. Irrelevant
  for µV proton signals (deep in the linear region), but a saturated amp
  recovers slowly — keep `DELAY` long enough to clear quench-transient
  saturation, but see the T2* caveat below for why it shouldn't be *too* long.

**Test B — full pipeline via injection + shorted control.** Ran the real
`PPM.py` acquisition+FFT pipeline on sig-gen tones near the proton frequency
(`Software/RPiPythonCode/data/SIGGEN*_2026_06_13_*`) and on a detached/shorted
input (`SHORT_2026_06_13_13_07_35`):
- SIGGEN 2436 Hz & 2438 Hz at 100 mV and 500 mV → clean single FFT peak,
  **58–60 dB SNR**, noise floor ~0 on that scale. The chain converts
  2436.23 Hz → **B = 57.219 µT**, matching the local field (57198 nT, Larmor
  ≈ 2435 Hz). So the injection sits *right at the real proton frequency* and
  the chain reports the right field — acquisition, FFT, interpolation,
  peak-pick and B-calc are all verified at the exact regime that matters.
- SHORT run → "No peaks found above threshold" (processing is NOT fabricating
  signals — good negative control). Noise floor ~1e-6 PSD (~45 dB headroom).
  **But** conducted-interference spurs at ~2620 / 2900 / 3110 Hz appear with
  the input shorted (switching/digital harmonics into the amp, not coil
  pickup). All above 2435 Hz so they won't be confused with a proton peak,
  but worth filtering; 2620 Hz is only ~185 Hz out.

**What is now crossed off the suspect list (from the 6/12 list):**
- ~~Sensor-coil cancellation~~ → working (Test A spatial null).
- ~~Acquisition/processing chain~~ → working (Test B injection + shorted control).
- ~~Amp gross self-oscillation~~ → not oscillating (shorted run is just
  noise + conducted spurs, no runaway tank peak).
- (Quench/polarization already exonerated 6/12.)

**Remaining suspect is now strongly isolated to PROTON-SIGNAL
GENERATION/COUPLING at the sensor** — is enough precessing magnetization
produced, and is its EMF above the µV-scale noise floor.

#### Design calc 1 — tuning capacitor to resonate the sensor tank at 2435 Hz

Sensor inductance L ≈ 2 × 3.5 mH = **7.0 mH** (two coils series; spatially
separated so mutual coupling ≈ 0, self-inductances add). Target f₀ = 2435 Hz.

    C = 1 / [(2πf₀)² L] = 1 / [(2π·2435)² · 0.007] ≈ 0.61 µF

(Book's own example — same 7 mH at 2247 Hz — gives 0.72 µF, a sane DIP-bank
value, so this checks out.) Sensitivity (C tracks L directly): 6.5 mH→0.66 µF,
7.0→0.61, 7.5→0.57, 8.0→0.53 µF.

Tank properties: Q = ω₀L/R = (2π·2435·0.007)/5.9 ≈ **18** (unloaded; amp/
transformer load pulls it down). Gives ~**18× (~25 dB) voltage gain** on the
proton EMF *before* the amp, and a **−3 dB bandwidth ≈ 135 Hz** — wide enough
to be forgiving on tuning (±5% on C stays in band), narrow enough to start
rejecting the 2620/2900/3110 Hz spurs. Build notes: **measure L first** with
an LCR meter (the 3.5 mH/coil is nominal); use **polypropylene film** caps
(low loss/stable, won't spoil Q); 0.47+0.15 µF = 0.62 µF or 0.56 µF + trim;
load the existing 12-position DIP bank with values bracketing 0.61 µF and
sweep to peak. Caveat: resonance helps if the floor is amp/interference-set
(which the SHORT test suggests); if coil Johnson noise dominated, it would
lift signal and noise together (SNR flat) but still add interference rejection.

#### Design calc 2 — expected proton FID EMF for this coil + a water sample

Curie-law magnetization in the polarizing field:

    M₀ = N_p γ² ℏ² B_p / (4 k_B T)

with N_p = 6.69e28 m⁻³ (2 H per H₂O molecule), γ = 2.675e8 rad/s/T,
B_p = 0.0075 T (≈75 G; ~67 G at the measured 8.6 A), T = 293 K
→ **M₀ ≈ 2.5e-5 A/m** (an equivalent source field μ₀M₀ ≈ 31 pT — the
classic tiny proton signal, right order of magnitude).

Coil geometry (book gives 552 turns / 3.5 mH but no dimensions; reverse-
engineered via Wheeler's multilayer formula): **r ≈ 2.0 cm, l ≈ 10 cm,
~4 layers** fits 3.5 mH → A = πr² = 1.26e-3 m², sample volume in one coil
≈ 126 mL. Peak FID EMF by reciprocity (full M₀ goes transverse after a
perpendicular quench):

    ε_pk = ω₀ μ₀ N_c A M₀
         = (15300)(1.257e-6)(552)(1.26e-3)(2.5e-5)
         ≈ 0.33 µV peak  (≈ 0.23 µV RMS)

Noise comparison: coil Johnson noise √(4k_BT·5.9Ω) = 0.31 nV/√Hz; system
input-referred ~2 nV/√Hz; in a 1.5 s record (≈0.67 Hz bin) noise ≈ 1.6 nV.
→ **SNR_raw ≈ 230/1.6 ≈ 140 (~43 dB) untuned**, and ~25 dB more with the tank.
Scaling for adjusting to real numbers: ε_pk ∝ B_p · N_c · r² · f₀ (double the
radius → 4× signal; the 67→75 G uncertainty is only ±12%).

**Implication — the signal should be ~40 dB over the floor even untuned**, so
the gap is upstream of detection. Two high-value, cheap experiments:
1. **Shorten `DELAY`.** The runs used `DELAY 500` (500 ms before sampling).
   In Earth's field T2* (set by field inhomogeneity over the sample) is often
   only ~100–300 ms; at T2*≈200 ms, waiting 500 ms leaves only ~8% of the FID
   (e^−2.5). **Try DELAY 100–150 ms** — just enough for the amp to recover
   from the quench transient. Free, high-leverage test.
2. **Perpendicularity** — ε ∝ sin θ of the polarizing axis vs Earth's field;
   confirm the platform tilt against the local inclination (68°35′).

**Next-up:** estimate T2* from a field-gradient assumption, and/or sanity-check
the polarizing-coil tilt against the 68°35′ inclination; then re-run with a
shorter DELAY and a tuned tank.

---

### Follow-up 2026-06-13 (evening): FIRST SAMPLE RUNS — NO SIGNAL, FRONT-END OSCILLATION FOUND

First real attempts at detection (still **untuned** — no tank cap yet). Runs in
`Software/RPiPythonCode/data/`: `sample_*` (distilled water), `2xsample_*`
(two bottles), `nosample_*`, `Kerosine_*`, `delayreduced200ms_*`,
`2xsampleampgain*`. All look like noise. Numerical analysis of `run_00.dat`
(N=24000, sample_rate ≈ 16.2 kHz, 1.48 s window) gives:

| Run | rms total | rms @~7.7 kHz | rms in-band 2.3–3.3 kHz | env decay end/start |
|---|---|---|---|---|
| Distilled water| 19.9 | 17.8 | 2.20 | 1.06 |
| 2× water | 20.0 | 17.9 | 2.10 | 0.97 |
| No sample | 20.0 | 17.7 | 2.24 | 1.06 |
| Kerosene | 20.2 | 18.7 | 1.30 | 0.98 |
| Coil SHORTED | 21.4 | 19.2 | 1.17 | 1.00 |

**Three independent proofs there is no proton signal:**
1. **Water ≈ no-sample in every band** (2.20 vs 2.24). The sample changes nothing.
2. **No envelope decay** (end/start ≈ 1.0). A real FID *must* decay over a 1.48 s
   window (T2* ~0.5–2 s → expect ≈0.3–0.5). Flat envelope = steady interference.
3. **Same total RMS with the coil detached and terminals shorted** (21.4) as with
   a sample (20). The dominant noise is **not coming through the coil** — it is
   generated downstream of it.

**ROOT CAUSE FOUND — chronic front-end oscillation.** The single biggest feature
in *every* run, including coil-shorted, is a coherent tone at **~7.6–7.8 kHz,
~18–19 counts RMS — ~90 % of total noise power.** Present with the input shorted
⇒ the amplifier is self-oscillating (or a switching/clock artifact is injecting),
**not pickup.** This confirms the long-standing "amp oscillation" suspect.
- Apparent frequency drifts run-to-run (7639 / 7565 / 7765 Hz) and sits just
  below Nyquist (8112 Hz @ 16.2 kHz) — likely an oscillation slightly *above*
  Nyquist aliasing down. **There is no anti-alias filter**, so anything 8–16 kHz
  folds straight into the proton band.
- Raw ADC sits on a large DC offset (~−13 800 counts) using only **~90 of 65 536
  counts** of swing — most of the dynamic range is wasted.

**Why it buries the proton signal:** expected EMF ~0.33 µV needs the full ~3.8 M
gain; an amp oscillating at 7.7 kHz is by definition unstable, and the
oscillation + DC offset eat the headroom and desensitize it.

**Prioritized fixes (in order):**
1. **Add the tuning cap / build the LC tank (~0.61 µF) — biggest single win.**
   Resonance does two jobs at once: boosts the proton EMF by **Q ≈ 18×** *and*
   gives a narrow bandpass that rejects the 7.7 kHz **before the amp.**
2. **Kill the oscillation — but note these runs used a CHEAP AliExpress amp
   module, NOT the book's amp.** So the ~7.7 kHz ring is the AliExpress board's
   problem, not the INA217 design's. **Plan (2026-06-13): restore the original
   book amp** (two INA217 stages ~1958× each → audio-transformer ~2.3 kHz
   bandpass → OP177G ±10 V limiter, ±12 V lantern batteries) and re-run. If the
   book amp *also* rings: tighten supply decoupling at each INA217's pins
   (0.1 µF + 10 µF), check transformer loading / lead dress, suspect the OP177G
   limiter stage. Either way, re-do the shorted-input + envelope-decay checks on
   the restored amp to confirm a clean baseline before trusting any sample run.
3. **Add an anti-alias low-pass (~3–4 kHz)** ahead of the ADC — essential
   regardless; you are sampling at 16 kHz with nothing filtering 8–16 kHz.
4. **Re-center the DC bias** to mid-scale so the ADC range is actually used.

Note: `2xsampleampgain*` (raised amp gain) and `delayreduced200ms_*` (DELAY
500→200 ms) made no difference — consistent with the gap being the front-end
oscillation + no tank, not gain or DELAY.

---

### Sample volume / filling factor (2026-06-13)

The FID EMF scales ~**linearly with the polarised sample volume inside the
sensing coil** — the *filling factor* η (fraction of the coil's sensitive bore
occupied by polarised water):

    ε_pk ∝ ω₀ · M₀ · V_sample-in-coil ≈ ω₀ · M₀ · V_coil · η

So small bottles that only partly fill the bore leave signal on the table. Going
from (say) η≈0.25 to η≈1 by filling the bore is a **~3–5× (~10–14 dB) signal
gain** — directly raising signal vs the noise floor. The earlier ~0.33 µV EMF
estimate assumed a particular fill; under-filled bottles give *less* than that.

**Plan:** seal distilled water in a **flexible bag that conforms to and fills one
sensing coil's bore** (beats a cylindrical bottle — no corner air gaps).

Rules / caveats:
- **⚠ GRADIOMETER: fill ONE coil only.** The sensor is series-opposition; a
  sample spanning both coils partly **cancels** (confirmed: signal only when in
  one coil). Keep the reference coil empty for common-mode rejection.
- **Polarising field must cover the whole enlarged sample**, uniformly — any
  part outside the polarising coil isn't polarised and contributes nothing.
- **T2\* vs homogeneity:** a bigger sample spans more field gradient → faster
  dephasing → shorter T2\*/broader line. Fill the *homogeneous* region; don't
  oversize beyond the coil bore.
- **No air bubbles** (dead volume) — seal the bag completely full.
- **Non-magnetic everything** — no metal clips/ties/ferromagnetic contaminants;
  they distort local field and wreck T2\*. Distilled (ideally degassed) water.

Complementary to the amp restore + SW1 tank tuning: those raise gain/Q, this
raises the source signal. All three stack.

---

## Sensor coil characterization & tank tuning (2026-06-19)

Measured the coil resonance directly with the **ring-down method** (see
`measure-inductance-with-scope.md`): drove the sensor coils with a 100 Hz
square wave, **98.8 nF film cap** temporarily across the termini (this cap is a
*test fixture only* — NOT the SW1 bank), scoped the damped LC ring on the tank.
Captures: `ppm_data/SDS00018.png`, `ppm_data/SDS00019.png`.

Ring period from on-screen cursors → resonant frequency → coil inductance
(L = 1 / ((2πf)²·C), C = 98.8 nF):

| Capture | ring period | f_res | derived L |
|---|---|---|---|
| SDS00018 | 142 µs | 7.04 kHz | 5.17 mH |
| SDS00019 | 148 µs | 6.76 kHz | 5.62 mH |
| **avg** | — | **~6.9 kHz** | **L ≈ 5.4 mH (±5%)** |

**Measured L ≈ 5.4 mH for the tank as tested** — note this is higher than the
book's nominal 3.5 mH/coil; use the *measured* value for tuning. The ring dies
in ~4–5 cycles → low loaded Q (~5), so resonance is broad (BW ≈ f/Q ≈ 500 Hz);
the scope's input loading inflates the damping, so realized Q at signal feeding
the amp may differ — re-measure once wired to the amp.

### Tuning the SW1 bank to the Larmor frequency

Larmor freq here = 0.042577 Hz/nT × 57198 nT = **2435 Hz** (matches the
`SIGGEN2436HZ` test runs). To resonate L ≈ 5.4 mH at 2435 Hz needs
**C ≈ 790 nF** (range 760–810 nF across the L uncertainty band).

SW1 bank caps are all in **parallel** (each DIP switch gates one cap between the
signal node and common); total C = sum of ON switches:

| Sw | Cap | nF |  | Sw | Cap | nF |
|----|-----|----|--|----|-----|----|
| 1 | C1 | 560 |  | 7 | C7 | 22 |
| 2 | C2 | 390 |  | 8 | C8 | 10 |
| 3 | C3 | 220 |  | 9 | C9 | 5.6 |
| 4 | C4 | 100 |  | 10 | C10 | 3.9 |
| 5 | C5 | 56 |  | 11 | C11 | 2.2 |
| 6 | C6 | 39 |  | 12 | C12 | 1 |

**→ Set switches 1 + 3 + 8 ON (C1 0.56 + C3 0.22 + C8 0.01 = 790 nF →
resonance ≈ 2440 Hz.)** Three switches, lands on the Larmor frequency.

**Fine-trim** with the small caps while watching the actual precession signal:
+12 (1 nF), +11 (2.2), +10 (3.9) lower f slightly; swap C8→C9 (5.6) raises it.
Confirm by repeating the ring-down with the bank set to 1+3+8 — target ring
period ≈ 410 µs (1/2440 Hz).

---

### Follow-up 2026-06-21: BOOK AMP CONFIRMED — 7.7 kHz OSCILLATION ELIMINATED

End-to-end runs with the **restored book amp** (INA217 ×2 → audio-transformer
bandpass → OP177G limiter), a signal generator driving **2440 Hz** into the
sensor coil, three cap-bank settings, plus a **grounded-input** baseline. Runs
in `Software/RPiPythonCode/data/`: `SIGNAL2440CAP1-3-8_*`,
`SIGNAL2440CAP1-3-8-11_*`, `SIGNAL2440CAP1-3-8-10-11_*`, `GROUNDED_*`
(N=24000, fs≈16224, 1.48 s, 3 runs each, df≈0.68 Hz).

**1. The chronic 7.7 kHz oscillation is GONE.** It was ~90 % of noise power on
the AliExpress module, present even shorted. On the book amp, with input
grounded, the 7–8 kHz band holds **0.02 %** of power. Restoring the book amp
fixed it, exactly as planned in the 2026-06-13 entry.

| Power in band, input grounded/shorted | Old AliExpress amp | New book amp |
|---|---|---|
| 7.5–8.0 kHz | ~90 % | **0.01 %** |
| 7.0–8.0 kHz | dominant | **0.02 %** |

**2. The ~7320 Hz peak in the SIGNAL runs is harmless.** It is exactly
3 × 2440 = 7320 Hz — the **3rd harmonic** of the injected tone (~−45 dB, mild
distortion of a deliberately strong drive). It **disappears in the grounded
run** (7–8 kHz collapses to broadband noise, peaks wandering 7145/7162/7318 Hz),
proving it is not an oscillation.

**3. Pipeline + calibration validated.** All three SIGNAL runs recover the tone
at 2439.7–2440.1 Hz (<1 bin error) with per-run SNR 52–55 dB; computed field
57.301–57.310 µT vs the expected 2440/42.5774 = **57.307 µT** — γ_p constant in
`PPMCalc.py` is correct to ~5 sig figs. Cap-bank setting barely moved SNR
(52–55 dB across all three) because the injected tone swamps the tank — tuning
only matters for the tiny real proton signal. The grounded run correctly
reported **"No peaks found above threshold"** (good null test).

**4. New dominant baseline noise = a 200–500 Hz cluster (NOT mains).** Grounded
per-band power: 0–200 Hz 11 %, **200–500 Hz 75 %**, 500–2000 Hz 12 %, proton
band 2.3–3.3 kHz only **0.95 %**, 3.3–8.1 kHz 0.7 %. ~98 % is below 2 kHz.
Checked against exact mains harmonics: **no power at 50/100/150/300/350 Hz or
60/120 Hz.** The energy is a dense cluster centred ~200–260 Hz (strongest lines
~237 Hz and ~201 Hz with closely-spaced ~2 Hz satellites) — the signature of a
**mechanical/microphonic resonance** (transformer lamination buzz or coil
vibration), not power-line hum. It is large in absolute counts (grounded total
RMS ~27 k vs ~18 k for signal runs) so it eats ADC headroom, but it is well
outside the proton band and rejectable by the transformer + digital bandpass.
**Next noise target:** chase the 200–260 Hz microphonic source (damp/clamp the
transformer and coil, check lead dress and any vibration coupling).

---

### Follow-up 2026-06-23: SHUNT + HALL-SENSOR CAPTURES — TURN-OFF CONFIRMED FAST FROM TWO NEW VANTAGE POINTS

The long-planned current-shunt capture (planned 6/10, 6/12) was finally taken,
plus a capture of the field as the Hall sensor actually sees it. These confirm,
from two *independent* vantage points, what the coil-terminal captures
(SDS00011–16) already implied: the polarizing field collapses non-adiabatically.

- `SDS00022.png` — **voltage across a ~0.1 Ω shunt** (10× 1 Ω 2 W) in the coil
  leg, i.e. **coil current**; AC-coupled, 20 µs/div, 10× probe. Flat baseline
  (steady polarizing current), then at turn-off a burst ringing at
  **11.74 kHz** (cursors = one cycle, 85.2 µs), decaying over ~2–3 cycles.
- `SDS00023.png` — **field at the UGN3503UA Hall sensor**, 20 µs/div, 10× probe.
  Periodic ripple during polarization, large excursion at turn-off ringing at
  **11.90 kHz** (one cycle = 84 µs), settling within a couple hundred µs.

**Verdict — fast enough.** Larmor period at 2435 Hz is **T ≈ 411 µs**. The
dominant field collapse is the first sharp edge (a few µs, ~100× shorter than
T) → solidly non-adiabatic. The residual ring at **~12 kHz is ~5× the Larmor
frequency**, so the protons cannot track it; it averages out rather than
re-tipping or re-polarizing the magnetization. Both shunt (current) and Hall
(field) agree on the same ~12 kHz ring and the same fast initial edge.

**LC ring identified:** L ≈ 5.4 mH with f ≈ 11.7 kHz ⇒ C ≈ 34 nF — consistent
with a ~33 nF snubber across the coil (+ FET Coss).

**Bonus — polarizing field strength from the Hall step.** The UGN3503UA is
1.3 mV/G, so the turn-off step on `SDS00023` gives the field that collapsed:
ΔY = 122 mV ÷ 1.3 mV/G ≈ **94 G ≈ 9.4 mT** inside the coil. The step ≈ B_pol
because the field drops from B_pol to ~Earth (~0.57 G, negligible). This is
comfortably above the book's design target of **≈75 G (7.5 mT)** at coil
centre — independent confirmation (beyond the 600 mm compass deflection) that
the polarizing field is on-spec in *magnitude*, not just present.
*Caveats:* AC coupling reads the step fine but not the absolute level; the
12 kHz ring makes cursor placement on the edge uncertain (dominant error);
result assumes the channel's 10× factor was applied (else it'd be a nonsensical
~940 G). Call it **~90 G, ±a bit.** For a clean number, DC-couple the Hall
output and subtract two static levels: B_pol = (V_on − V_quiescent[≈2.5 V]) /
1.3 mV/G — good to a few % and lets you map field *uniformity* by moving the
sensor inside the coil.

**Side note (not a turn-off fault):** that ~12 kHz ring is real field energy at
the sensor for ~200 µs after turn-off. Harmless to the precession physics, but
if it couples into the INA217 front-end it adds to the dead-time before the FID
is usable. If ever worth killing faster, tune an R–C snubber/clamp to damp it —
trading a slightly slower (still fast enough) edge for a shorter tail.

> Index note: `oscope_index.txt` had an off-by-one (labelled these SDS00023/4);
> corrected so SDS00022 = shunt, SDS00023 = UGN3503UA.

---

### Follow-up 2026-06-24: FIRST TUNED SAMPLE vs NO-SAMPLE RUNS — STILL NO FID; DOMINANT LINE IS THE TANK (true Larmor uncertain on basalt — see same-day addendum below, which walks back the "mistuned, retune to 2435" framing)

First sample/no-sample comparison with the **full chain in place** (book amp +
SW1 tank tuned + real polarise-sample cycles, no signal injection). Runs in
`Software/RPiPythonCode/data/`, all `ONTIM 6000 / SAMPT 1500 / SAMRA 16000 /
COOLD 10000`, differing only in DELAY and analysis band:

| Run | Sample | DELAY | Band | n |
|---|---|---|---|---|
| `SAMPLE_…11_02_05` | yes | 500 ms | 2300–3300 | 3 |
| `SAMPLED150_…11_04_07` | yes | 150 ms | 2300–3300 | 3 |
| `SAMPLED150_…11_06_10` | yes | 150 ms | 2300–3300 | 6 |
| `SAMPLE_WIDE_…11_09_40` | yes | 150 ms | wide | 6 |
| `NO_SAMPLE_WIDE_…11_13_44` | **no** | 150 ms | wide | 6 |

**No proton signal — three independent proofs (same logic as 6/13 evening, now
with the good amp + tank):**
1. **No-sample ≈ sample.** Reprocessed through the PPMCalc pipeline, the
   no-sample averaged spectrum peaks at **2373 Hz / 18.5 dB**, the sample at
   **2382 Hz / 18.5 dB** — same line, same strength. Removing the water removes
   nothing.
2. **Wrong frequency.** Every run peaks **2373–2387 Hz**, consistently ~50–60 Hz
   *below* the 2435 Hz Larmor target. Not a field-model error (that's ~2.4 %).
3. **No envelope decay.** Filtered RMS start/end ratio ≈ 0.95–1.0 in every run
   (zero-phase filtered, so not a causal-filter transient). A real FID must
   decay over the 1.48 s window; flat = steady line.

**The line IS the pickup tank, and it's mistuned.** Inserting the sample shifts
the resonance **2373 → 2382 Hz (~9 Hz up)** — the water dielectrically/inductively
loads the sensor coil, which only a *coil-resonance* line would do (external
interference wouldn't move). So the dominant feature is the LC tank ringing on
ambient/microphonic noise — and it sits at ~2380 Hz, **~55 Hz below** the 2435 Hz
Larmor frequency despite the 6/19 ring-down + 6/21 injection saying 1+3+8 ≈
2440 Hz. A tank centred at 2380 is doubly bad: it (a) manufactures the steady
2380 line and (b) **attenuates a real 2435 Hz proton signal on its resonance
skirt** (worse the higher Q). Likely loaded-Q pull and/or component drift vs the
unloaded ring-down; the live noise-excited resonance is the number that matters.

**DELAY and wide band changed nothing.** 500→150 ms DELAY left the peak at
~2383–2387 Hz (a shorter DELAY should *boost* a decaying signal; it didn't —
consistent with no FID). Widening the band to 2000–4000 Hz revealed no hidden
peak at 2435 Hz, only more steady lines (2650/2750/3050 Hz family).

**Post-processing attempts to dig out a buried FID (none succeeded — confirming
nothing is there in *this* data):**
- *Spectral background subtraction* (no-sample as background): confounded by the
  ~9 Hz sample-induced shift — the resonance doesn't line up, so the residual is
  the shifted line, not a proton peak.
- *Tail-fit resonance peel* (new tool, below): removes ~45 % of the 2380 line
  (its coherent part; the noise-excited narrowband pedestal remains), and **no
  peak emerges at 2435 Hz**; residual-head start/end ratio for sample (1.12) ≈
  no-sample (1.17).

**New analysis tools added to the repo (committed, branch
`add-run-comparison-tools`):**
- `Software/RPiPythonCode/compare_runs.py` — overlays two run sets (averaged
  spectrum + RMS envelope) to test for a real, decaying, sample-dependent signal.
- `Software/RPiPythonCode/suppress_resonance.py` — peels the steady tank line by
  fitting a constant-amplitude sinusoid on the (proton-free) record tail and
  subtracting it across the whole record, exposing any decaying head underneath.
  Exact only for a *coherent* line; suppresses (doesn't erase) a noise-excited
  one. Its real use comes *after* retuning, when line and signal coincide at
  2435 Hz and a notch would kill both.

**Highest-value next step is hardware, not software — retune the tank onto
2435 Hz** so it *amplifies* the protons instead of attenuating them (reduce total
C slightly: f ∝ 1/√C, so ~2380→2435 Hz needs C down ~4–5 %, e.g. trim the small
SW1 caps; re-verify with a ring-down *while loaded by the amp*, not unloaded).
Then re-run sample vs no-sample and use `suppress_resonance.py` to separate the
co-located line from any FID by its decay. Also still open: chase the 200–260 Hz
microphonic (6/21) that drives the resonance, and confirm polarising-coil tilt
vs the 68°35′ inclination. If a retuned, lower-noise tank *still* shows no
sample-dependent decaying head, the gap is source coupling (filling factor /
T2\*), not detection.

#### Addendum 2026-06-24 (same session) — two corrections after thinking it through

Prompted by two good questions from the user; both refine the entry above.

**(1) "How long does the ringing last? Is it weaker with a longer DELAY?"**
Measured in **raw ADC counts** (DC-removed only — *not* PPMCalc's per-record
range normalisation, which would erase absolute-amplitude differences between
runs). In-band (2300–3300 Hz) RMS:

| Run | DELAY | mean in-band RMS (counts) | per-run spread |
|---|---|---|---|
| SAMPLE | 500 ms | 1645 | 1621–1676 |
| SAMPLED150 | 150 ms | 1688 | 1669–1709 |
| SAMPLED150 ×6 | 150 ms | 1678 | 1621–1755 |

The 500 ms run is only ~2.6 % below the 150 ms run — **less than the ±4 %
run-to-run scatter** — so it is **not** meaningfully weaker. Within each record,
first-150 ms vs last-150 ms ratio ≈ 1.02 (DELAY 500) and 0.97 (DELAY 150) =
flat. A decaying component (FID or long ring-down) with τ of a few hundred ms
would show a clear drop when sampling starts 350 ms later, and head > tail;
neither happens → the in-band energy is a **steady, continuously re-driven
resonance**, not a ring-down. The *quench-excited* tank ring-down decays with
τ = Q/(πf) ≈ 0.7–2.4 ms (Q≈5–18 at ~2400 Hz) — gone within ~10 ms, long before
sampling starts at either delay (consistent with the 6/23 captures settling in
~150–200 µs). So the only "ringing" still present at 150–2000 ms is the steady
noise-driven line.

**(2) "2435 Hz is only the *likely* signal location — the field changes daily and
I'm on a basalt volcanic peninsula."** Correct, and it walks back two over-claims
in the entry above:
- **2435 Hz is the IGRF *model* value (57198 nT) and does not include the local
  crustal anomaly.** On basalt/volcanic terrain, static anomalies of ±hundreds-
  to-thousands of nT are normal; diurnal (Sq) variation adds a few nT / few Hz,
  more in a storm. So the true local Larmor could plausibly sit anywhere
  ~2300–2500 Hz. The observed 2380 Hz line = **55.74 µT**, only ~1450 nT below
  the model — entirely consistent with a basalt anomaly. (There is also a
  ~2450 Hz line = the **49th harmonic of 50 Hz mains**, the one the code warns
  about — so "the peak" is at least two interferers, not one clean feature.)
- **Therefore the "tank is mistuned ~55 Hz low → retune to 2435 Hz" advice was
  premature.** If the field really is ~55.8 µT, then 2380 Hz *is* Larmor and the
  tank may already be on target — retuning to 2435 would move *away* from the
  signal. And the tank is low-Q (~5, BW ≈ 500 Hz), so it already spans
  ~2200–2650 Hz; exact tuning isn't critical for first detection.
- **The "wrong frequency" item in the three-proofs list is the weak one** and
  should not be leaned on. The two field-independent proofs — no-sample matches
  sample, and no envelope decay — are what actually rule out a proton signal
  here, and they hold regardless of the basalt offset.

**Revised next step:** don't chase a number. **Search wide (~2200–2600 Hz) and
let the real Larmor reveal itself as the one peak that both appears only with the
sample and decays**, wherever it lands. Pinning the local field to better than
~±1000 nT needs an independent reference (or a working FID to report it) — the
model value isn't trustworthy on basalt.

#### Follow-up 2026-06-24 (later) — Arduino boot-handshake bug found & fixed

Noticed in the logs that the controller did **not acknowledge the settings for
the first run** of each session: `Sending command: 'ONTIM 6000'` →
`Received response: ''` (empty) for the first 4–5 commands, with the boot banner
`'Proton Precession Magnetometer - Coil Controller'` appearing mid-stream as a
bogus reply to `COOLD`. Cause: **opening the serial port toggles DTR and resets
the Arduino**, which then boots ~1–2 s before it listens; the host was firing the
config commands into a still-booting board. Only run 1 is affected (one port-open
per session); runs 2+ ack normally (`OK ONTIM: 6000` …).

**Data-quality implication:** `run_00` of each 2026-06-24 multi-run session
probably executed with the Arduino's **power-on default timing, not the logged
values** — in particular the SAMPLED150 / WIDE sessions' `run_00` may have used
the firmware default `DELAY`, not 150 ms. Treat `run_00` of those sessions as
suspect (drop it, or re-run). Doesn't change the no-FID conclusion (runs 2+ are
valid and tell the same story), but worth knowing.

**Fix (committed):** `PPM.PPMRun.__init__` now waits for the boot banner
(`READY_BANNER` = "Coil Controller", up to `READY_TIMEOUT_S` = 5 s) before
sending anything, via a new `_wait_for_ready()`; flushes the input buffer once
the banner is seen so the first real command gets a clean ack. Timeout is
non-fatal (boards that don't auto-reset just proceed). The log now shows a
`Controller ready: '…'` line at the start of each session. Tests added.

---

### Follow-up 2026-06-25 — FIRST E–W HORIZONTAL RUNS: NO FID, RIG IS MAINS-LIMITED

Acted on the 6/24 orientation advice: coil **horizontal, axis magnetic E–W**
(automatically ⊥ to the field regardless of inclination). Two matched 6-run
sets via the new `ppm.ini` (`on-time 6000 / sample-time 2000 / sample-rate
16000 / delay 100 / cool-down 10000`): `SAMPLE_E-W_2026_06_25_10_25_59` and
`NOSAMPLE_E-W_2026_06_25_10_31_02`.

**No proton FID.** A band-wide decay scan (2300–2500 Hz, per-run head/tail RMS,
zero-phase ±15 Hz) finds **no frequency where the sample set decays more than
no-sample** — ratios scatter ~1.0 everywhere in both sets. `compare_runs.py
--per-run` confirms flat decay (0.83–1.14) at the dominant lines.

**Two extra controls (also noise):** `SAMPLE_REV_E-W_…10_47_05` (polarising-coil
terminals reversed) and `SAMPLE_REV2_E-W_…10_52_19` (sample in the *other*
sensor coil). Both peak at ~2350 Hz like the no-sample baseline, and the
band-wide decay scan (2320–2480 Hz) flags **no sample-only decaying feature** in
either. Caveat on why these are weak *presence* tests: a real FID's **power
spectrum is invariant** under both — reversing B_p flips the FID's initial phase
180° (same magnitude/frequency), and moving the sample to the opposed gradiometer
coil flips its sign (again phase-only). So they can't reveal a signal the FFT
magnitude already misses; they're **wiring/artifact sanity checks**, and they
pass (response independent of polarity and of which coil → rules out a
sample-detuning-one-coil artifact). The real discriminator stays decay +
sample-dependence, still negative. (Bonus: these are the first runs with the
two-phase handshake fix — `Controller ready (boot output drained)` in both logs,
so their `run_00` used correct settings.)

**The rig is now MAINS-LIMITED.** The averaged spectrum is a clean **50 Hz
harmonic comb** — sharp lines at 2250/2300/2350/2400/2450/2550 Hz (= 45–51 × 50,
odd harmonics strongest = transformer/SMPS signature). No-sample is dominated by
the **2350 Hz (47th)** line, sample by **2450 Hz (49th)**: the broad low-Q tank
amplifies whichever harmonic it sits nearest, and inserting the sample loads the
coil and nudges the tank from ~2350 to ~2450 (both steady interference, neither
decays). Per-run SNR rose to 30–38 dB (vs 20–25 on 6/24) — just **sharper
interference**, not signal. So the E–W orientation changed the pickup as
expected geometrically but coupled the horizontal loop strongly to building
mains wiring.

**⚠ Coincidence that raises the stakes:** the likely basalt Larmor (55–57.5 µT)
is **2349–2449 Hz — right on the 2350/2450 mains harmonics**. If the true Larmor
lands on a harmonic it is spectrally indistinguishable from mains; **only the
decay separates them.** So killing the mains AND leaning on decay-based detection
both matter.

**Revised top priority — reduce mains pickup (ahead of more orientation
sweeping):**
1. Get **away from mains**: outdoors, away from the building, wooden/plastic
   stand (book p.59). The horizontal E–W loop is coupling to wall/floor wiring.
2. **Battery-power everything**, including the acquisition Pi/laptop, or keep
   mains gear far away on long leads.
3. **Contemporaneous background subtraction** — `ppmrun.py --background-runs N`
   (built for stationary mains harmonics). Imperfect here because the dominant
   harmonic differs sample vs no-sample, but it knocks down the common comb.
4. **Then resume the orientation sweep** — E–W is one perpendicular point; on
   basalt the true perpendicular may need azimuth/tilt tweaks. Sweep *after*
   taming mains, else every angle is mains-limited.

**Handshake fix refined (the boot bug wasn't fully solved on 6/24).** These logs
showed the firmware prints a **multi-line memory self-test ("Memory check
passed: read 42 from address …") AFTER the banner**, so run 1's command acks
were still offset by that chatter (and could overflow the Arduino's 64-byte RX
buffer) — `run_00` of these E–W sessions remains suspect. `_wait_for_ready()` is
now **two-phase**: wait for the banner, then **drain until the serial line is
quiet** (a read returns nothing) before flushing, so trailing self-test output
no longer pollutes the first command. Regression test added (`Memory check`
lines after the banner). Doesn't change today's conclusion (runs 1–5 agree).

#### Follow-up 2026-06-25 (later) — SAMPLE WATER IS "OXYGEN ENHANCED" (paramagnetic — bad)

Realised the "distilled water" sample is **"oxygen enhanced"** bottled water
(puredew.co.nz) — i.e. deliberately supersaturated with O₂. **Dissolved O₂ is
paramagnetic**, which shortens the proton relaxation times:
- **T1** (polarisation) shorter — mildly *helpful* (saturates faster; air-sat
  water T1 ≈ 2.3 s vs ~3.6 s degassed; supersaturated could be < 1 s).
- **T2 / T2\*** (FID decay & line width) shorter — *harmful*: faster decay, broader
  line, signal energy spread over more FFT bins → lower peak. PPMs specifically
  want **degassed** water for a long, narrow FID.

It does **not** reduce signal amplitude (Curie M₀ is unaffected), so it is *not*
the sole cause of the null — orientation and mains are bigger and confirmed. But
it attacks the one quantity that decides whether any FID survives to the ADC:
the signal only outlives the `DELAY` (100 ms) if T2\* > delay. On basalt, T2\* is
*already* short from field gradients (~100–300 ms); stacking paramagnetic O₂ on
top can push the combined T2\* below the delay, so the FID decays away before
sampling — which would look **exactly like the flat, no-decay records seen all
along.** A plausible *contributor* to the null, and free to remove.

**Action:** switch to **plain distilled water** (auto-parts / supermarket, NOT
oxygen-enhanced), **degas it** (boil ~10–15 min, cool in a sealed completely-full
container), and **fill the sample bottle to the brim, no air gap** (stops
re-oxygenation, kills bubble dead-volume). **Test when dry:** oxygen-enhanced vs
freshly-degassed back-to-back at the same orientation (look for a decaying head
only with degassed via `compare_runs.py --per-run`), and try a very short
`DELAY` (≤ 50 ms) to catch a fast-decaying FID. Stacks with the mains fix and the
filling-factor note (2026-06-13).

#### Follow-up 2026-06-25 (later) — 200–260 Hz microphonic ~100× down; noise traded for mains (DIFFERENT LOCATION, near the power-line entry)

Checked whether the 6/21 **200–260 Hz microphonic** (transformer/coil vibration;
was 70% of grounded-run power, peak ~237 Hz) survives in today's runs. Absolute
band RMS in 200–260 Hz (counts): today's E–W runs **~228–242**, vs 6/21
**grounded 22,669** and 6/21 **SIGNAL2440 (coil-connected) 915** → roughly a
**100× drop** (and ~4× below even the coil-connected 6/21 run). Today's strongest
low-frequency line is **150 Hz** (3rd mains harmonic), not 237 Hz. So the
microphonic is no longer a player.

**Why the change — location.** Today's runs were at a **different location,
closer to where the overhead power lines enter the house.** That explains the
whole shift: the noise traded from **microphonic-limited (6/21)** to
**heavily mains-limited (6/25, the 50 Hz harmonic comb)**. Concrete confirmation
that **position dominates mains pickup** — and a pointer for the fix: the move
went the *wrong* way (toward the service entry). The "reduce mains" action is now
specific: **get well away from the power-line entry / overhead drop — ideally
outdoors, far from the house.**

Caveat: the 6/21 microphonic number is from a *grounded* (input-shorted) run;
today's are live. To confirm the microphonic is genuinely fixed (not just masked
or dependent on how the rig is currently clamped), take a **grounded run in the
present setup** — if 200–260 Hz stays ~230 counts there too, it's truly gone.

#### Option 2026-06-25 — battery instead of the 150 W Meanwell for the coil supply

Considering powering the polarising coil from a **12 V 16 Ah sealed lead-acid
(AGM) deep-cycle battery** (NOMAD E2 ULTRA: 12 V, 16 Ah, max discharge 180 A/2 s,
internal R ≈ 17 mΩ, plain T1/T2 spade terminals — *not* a jump starter, no
electronics). **Verdict: do it.**

- **Capability — trivial.** The ~9.6 A / 6 s pulse barely loads it: sag ≈
  9.6 A × 0.017 Ω ≈ **0.16 V** (stable current). Energy ≈ 0.016 Ah/pulse →
  ~0.1 Ah per 6-run session → **hundreds of runs per charge**; pulsed duty never
  stresses it. A charged SLA rests ~12.7–13 V vs the Meanwell's 12 V, so possibly
  **a few % more coil current/field** (mild signal bonus).
- **Noise benefit (real but secondary):** removes the Meanwell **SMPS switching
  noise** and the **mains-earth ground/conducted path**; floating & mains-free.
- **Main value = it makes the rig portable/mains-free → enables the relocation**
  away from the service entry (the actual fix for the comb).
- **⚠ Will NOT by itself kill the 2350/2450 Hz mains comb** — that is radiated
  pickup into the *sensor coil* (the 6/21 grounded run showed no in-band comb),
  fixed by relocation, not by how the coil supply is powered. Complementary, not
  either/or. (Consistent with the book already battery-powering the *amp*.)
- **Practical:** wire to the MOSFET bank "12 V In" (J2) via T1/T2; **inline fuse
  ~15–20 A at the battery +** (it'll dump 180 A into a fault); keep battery and
  leads **~1 m from the sensor coils and twist the leads**; charge with an
  SLA/AGM charger (14.4–14.6 V).

---

## Update 2026-07-12 — site1 runs (big sample + 20 m from building): still nothing; binary-failure analysis → gradient-broadening hypothesis

Site1 runs (`Software/RPiPythonCode/data/site1/`, larger degassed-water bottle
filling one sensor coil, rig ~20 m from the building): comb-notch Larmor gap
still empty (EW gap peak 5.3 dB / NS 4.1 dB over in-gap median = noise), decay
ratios 1.10/1.13 (need >1.3), and the 20 m move produced **no measurable drop
in mains-harmonic power** (±3 dB run scatter) — so distance is not the lever,
and the EW +58% gap-power excess is broadband noise, not a line.

That prompted a full "why NEVER any signal" review, written up in
**`gradient-broadening-hypothesis.md`** (this dir). Summary: the EMF budget
(Design calc 2 above) predicts 25–40 dB single-shot — and the book's own
Fig 7.6 peak is only ~24 dB — so the failure is **binary**, and every binary
candidate is excluded by the verification record **except one: T2* crushed to
≲10–15 ms by static field gradients** (basalt geology ± ferrous rig parts;
300–500 nT across the 10 cm sample suffices). Every decay test to date is
structurally blind to this because sampling starts at DELAY ≥ 25 ms — a
short-T2* FID would be 92% gone and smeared over 30+ Hz before the first
sample. Test plan (ranked, see the doc): (1) phone-magnetometer gradient
survey at the sensor position, threshold ~300 nT across the sample;
(2) `delay = 5` run + fine early-envelope check; (3) one session on
non-basalt ground (beach — also kills the mains comb); (4) if survey clean,
re-verify budget inputs (polarizing field at sample, calibrated µV
injection). Tilt sweep demoted — geometry can't produce a total null from a
horizontal EW axis.
- Amplifier gain ≈ 3.8 M (two INA217 stages, ~1958 each; audio transformer
  bandpass ~2.3 kHz; OP177G limiter clamps ±10 V). Powered by lantern
  batteries (±12 V).
- Sensor coils: 22 AWG, 552 turns, L ≈ 3.5 mH each, ~5.9 Ω incl. cable; two
  wound opposite & in series for common-mode noise cancellation.
- Earth's-field precession frequency ≈ 1.5–2.4 kHz (example: ~2247 Hz,
  Longmont CO).
- DAQ: IOtech ADAC/5501MF, 12-bit, ≥10 ksps; acquire 0.5–3.0 s.
- Processing (Ch. 7): drop first ~2000 points, 6th-order Butterworth BPF,
  FFT, then high-res hrft to locate the peak to ~0.1 Hz.
- PC control program: `adl.c` (Appendix A). Microcontroller: `mag4.asm` for
  AT90S2313 (Appendix B).
- Book web page / calculators: http://www.exstrom.com/magnum.html and the
  Digital Signal Processing page http://www.exstrom.com/journal/sigproc/

## Update 2026-07-14 — `delay = 5` executed (Test 2): no FID, and the front end is BLIND for the first ~40 ms

Ran the gradient-broadening plan's Test 2 (`delay = 5`). Two outcomes: a serial
bug that had to be fixed first, and a physics finding that **amends the test
plan** — see `gradient-broadening-hypothesis.md` §4 Test 2.

### The blocker that had to be cleared first: marker timeouts were the USB-serial link

`ppmrun.py` kept dying with `IOError: Timed out waiting for binary data marker`.
**Root cause: the coil switch-off transient coupling into the USB cable** — the
temporary battery/coil leads were run right alongside the USB lead. The FTDI
adapter **stays enumerated** (macOS `log stream` on usbserial/FTDI shows no
disconnect) but its **UART engine wedges**: every host read returns nothing for
ever, while the Arduino is completely unaffected — its RGB LED walks the whole
normal cycle, i.e. `sendData()` ran and clocked all 64 KB out of the TX pin into
a deaf handle. **Re-opening the port clears it** (the driver reconfigures and
purges the chip). Decisive evidence in
`data/delay/SAMPLE_5MS_2026_07_14_16_31_02/ppm.log`: after the timeout, `READV`
on the existing handle → silence; re-open → `READV` answers instantly. Leads
re-strung away from the USB cable; twisting the coil/battery pair is the further
fix (loop area is what radiates).

**Red herrings — do not re-chase:**
- *The delay value.* 25 ms (30+ clean prior sessions) failed identically, and
  5 ms later ran 6/6 clean. Also `delay` and `cool_down` appear in **both** the
  marker deadline and the real cycle time, so they cancel out of the margin and
  can never squeeze the timeout.
- *The baud rate.* 250000 is an exact divisor of the 16 MHz AVR clock (0% error,
  unlike 115200's ~2.1%); background runs push the identical 64 KB frame at the
  identical baud and have **never** failed; and the failure signature is **zero**
  bytes, not corrupt bytes (a marginal baud gives framing errors, not silence).
- *Board brownout/reset.* No boot banner ever appears in the stream.

Only coil-energising runs ever fail; `BKGND` (coil never energised) runs never
do — that asymmetry is the whole tell. Host-side changes (all in
`Software/RPiPythonCode`, 31 tests pass): `_sync_to_marker()` now captures the
bytes it discards and diagnoses the timeout three ways (boot banner ⇒ board
reset / bytes-but-no-marker ⇒ corrupted frame / silence ⇒ nothing arrived);
`_probe_link()` sends `READV`, then re-opens and asks again, so the traceback
itself says whether the board or the link died; `reopen()`; `--retries`
(default 2) repeats a cycle whose frame was lost. Retries are logged as
warnings, so **retries/session is a hardware-health metric** — the 12-run
session below needed 4.

⚠ **Do NOT "fix" the transient with a plain freewheel diode across the coil** —
its L/R decay is milliseconds, i.e. adiabatic against the ~411 µs Larmor period,
and would destroy the FID. If clamping is ever needed, use a TVS/zener
(µs collapse). The existing quench already avalanche-clamps at ~−312 V in
~50–66 µs and is verified good (07-03/07-04); nothing there needs changing.

### The physics result: no FID, and a NEW blocker

Session `data/delay/SAMPLE_5MS_2026_07_14_16_39_12` (12 signal + 6 background,
on-time 6000 / sample-time 2000 / sample-rate 16000 / **delay 5** / cool-down
10000). Analysis scripts in session scratchpad (`early.py`, `early2.py`).

The coil-pulsed runs show a **big decaying in-band excess** the coil-off
backgrounds lack — head(5–35 ms)/tail(1–2 s) envelope ratio **6.26 ± 0.43**
across all 12 runs vs **1.02** for backgrounds. It is **not** a proton signal:

| observation | value | reading |
|---|---|---|
| peak count, 5–10 ms after quench | 31276 = **95% of full scale** (RMS 20565 vs steady 2060) | front end is **railed**; OP177G ±9.1 V limiter clamping |
| envelope decay constant | **τ ≈ 38 ms** | tank (Q≈5) would be Q/πf ≈ 0.65 ms; water T2\* is 1–2.5 s → neither |
| strongest early-window bin | **2349 Hz** | 47 × 50 = the mains harmonic already proven pinned to mains (06-28 retune test) |
| Larmor gap (2405–2445) early excess | only 1.9× over background | nothing there |

So the early excess is the **pulse-induced ring parking on a mains harmonic,
seen through a saturated amplifier** — the 06-28 mechanism, now visible in full
because we are finally looking early enough. A *steady* line appears to "decay"
simply because the clipped gain is recovering.

**The amendment that matters: `delay = 5` does not buy the window the hypothesis
needs.** The first genuinely usable sample is still ~15–25 ms, and the front end
is not settled until ~40 ms — essentially where `delay = 25` already put us. **If
T2\* really is crushed to 10–15 ms, the FID is born and dies entirely inside the
interval where the amplifier is blind.** Shortening the delay further cannot fix
that; only stopping the overload can. The blocker is no longer firmware dead
time, it is **input overload recovery in the amp**.

Likely fix (to check against the book before building): a clamp at the **INA217
inputs** — anti-parallel diodes conduct during the transient and are effectively
open at µV levels. The existing ±9.1 V zener limiter is at the *output* of the
chain: it protects the ADC but does nothing for the in-amp being slammed.

**Control still missing:** `BKGND` never energises the coil, so it cannot
reproduce a pulse-induced transient. The decisive control is a **coil-pulsed
no-sample run at `delay = 5`** (same settings, bottle removed). If the early
excess is unchanged without the sample, it is 100% amp/mains. Run this before
the off-site trip so the trip starts from a clean baseline.

---

## 2026-07-16 — ★ FIRST CONFIRMED PROTON FID (off-basalt, the Groynes) ★

Test 3 of `gradient-broadening-hypothesis.md` was executed and **the signal
appeared.** The fully battery-powered rig — **unchanged** from its basalt
configuration — was driven ~10 km off the volcanic peninsula to "The Groynes,"
a regional park on the sediment/gravel floodplain of a braided river
(magnetically + electrically quiet). Data: `Software/RPiPythonCode/data/groynes/`
(`SAMPLE_EW`, `SAMPLE_NS` 6 runs each; `NOSAMPLE_EW` control; `SAMPLE_TOOLBOX_NS`
a deliberate ferrous-gradient spoiler; `SAMPLE_NS_1RUN` an averaging test).
ppm.ini: on-time 6000 / sample-time 2000 / sample-rate 16000 / **delay 50**,
band 2000–2800.

### The five proofs — every discriminator that was NEGATIVE on basalt is now POSITIVE

| # | Test | Result | Basalt history |
|---|---|---|---|
| 1 | **Locked line** | 2431.4 Hz, SNR 26–32 dB, identical across all 6 runs of EW *and* NS (spread 0.44 Hz ≈ 10 nT) | peak wandered the whole gap run-to-run |
| 2 | **Sample-dependent** | NOSAMPLE control has no line — strongest bin scatters 2312–2511 Hz at ~7–12 dB (noise) | sample ≈ no-sample, always |
| 3 | **Envelope decays** | Hilbert envelope fits **T2\* ≈ 0.8–1.6 s** (clean exponential); controls flat | early/late ratio ≈ 1.0 (flat) every time |
| 4 | **Ferrous mass kills it** | toolbox beside coils → SNR to ~7–13 dB, frequency de-locks (2336–2516) | n/a — new positive control |
| 5 | **Off the mains comb** | 2431 = 48.6 × 50, sits in the 2400/2450 harmonic gap | lines were always ON 50 Hz harmonics |

Proof 4 is the clincher and a **positive, on-demand reproduction of the
broadening mechanism**: only an NMR signal — which depends on B0 homogeneity
across the sample — is destroyed by a nearby ferrous mass; a mains tone or
electronic resonance is unaffected. The toolbox is now a keeper diagnostic.

### Field agreement
2431.4 Hz → **B = 57.11 µT** (γ_p = 42.5775 MHz/T). Nearest observatory
(~20 km, 15-Jul UTC) baseline ~57.16 µT ⇒ agree to **~55 nT = 0.10 %** — the
residual is the site's crustal offset. EW vs NS agree to ~5 nT (57.106 vs
57.10 µT): correct behaviour for a **scalar |B|** instrument, whose reading must
be orientation-independent — and is.

### Averaging finding (the single-run test)
`SAMPLE_NS_1RUN` (1 run) gave 29.5 dB — essentially identical to the 6-run
average (29.0 dB). **The rig is not random-noise-limited here**; one FID already
clears ~29 dB. Value of the 6-run protocol now = rejecting USB-dropout cycles +
confirming the frequency lock + √N-tightening the *field* estimate, NOT digging a
marginal signal out of noise. (Caveat: the FFT line is resolution-limited — 0.5 Hz
bins over a 2 s record — so the ~1.5 Hz FWHM is the window, not the true
linewidth, which from T2\* ≈ 1 s is ~0.3 Hz.)

### Tooling added this session
`PPMCalc.plotFilteredEnvelope()` (+ pipeline hook in `ppmrun.py`, + 4 tests):
every run now auto-generates `envelope_NN.png` — the whole filtered record in one
axis with its Hilbert envelope and an A·exp(−t/T2\*)+C fit, so the decay reads as
one continuous curve (with a `log_scale` option where a true exponential is a
straight line). Committed on branch `add-fid-envelope-plot`.

---

## Next steps (ranked) — now that the instrument is proven

The design **works end-to-end**. Two distinct goals now, with different levers.

### A. The specific question: would a SMALLER sample help? — *Yes, but only at home (basalt), not at a quiet site.*

The gradient-limited linewidth is Δf = (γ/2π)·ΔB = 0.0426 Hz/nT × (G·L), where
G is the local static-field gradient and L the sample extent along it, so the
gradient-limited **T2\* ≈ 1/(π·Δf) ∝ 1/L** — halve the sample, double T2\*.

But note the matched-filter arithmetic first, so we don't over-claim:
peak spectral height ∝ S0·T2\*, and S0 (proton count) ∝ volume ∝ L. So
S0·T2\* ∝ L·(1/L) = **constant** — for a *fully observed* line, shrinking the
sample trades signal for linewidth one-for-one and the SNR of the peak barely
moves. **Smaller sample is not a general sensitivity win.** It is decisive at
home for two reasons that have nothing to do with matched-filter SNR:

1. **Dead-time survival (the big one).** At home the FID must survive the
   ~40 ms amplifier-overload blind window (2026-07-14). If basalt crushes
   T2\* to ~15 ms, only e^(−40/15) ≈ **7 %** of the FID is left when the amp
   clears. Shrink L by ~4× → T2\* ≈ 60 ms → e^(−40/60) ≈ **51 %** left: a ~7×
   gain in *observable* amplitude — the difference between annihilated and
   detectable. The one-for-one SNR trade assumes you can see the whole decay;
   at home you can't, so lengthening T2\* past the dead time is pure win.
2. **Mains-gap fit.** A 30 Hz-wide gradient-broadened line straddles the
   2400/2450 harmonics and is inseparable from mains; a ~3 Hz line drops
   cleanly into the 2412–2438 gap.

**At the Groynes the opposite holds:** T2\* ≈ 1 s is already tank/intrinsic-
limited (the line is resolution-limited, not gradient-broadened), so a smaller
sample there just throws away signal for zero linewidth gain. **So: smaller
sample is a HOME lever, worth trying with a small vial or a thin (~1–2 cm)
tube of degassed water on basalt** — watch `envelope_NN.png` for a longer T2\*
and a line that clears the mains gap. Even a partial recovery quantifies the
mechanism.

### B. Make it work AT HOME (basalt) — the real prize (gradient mitigation)

1. **Smaller sample** — as above (free, do first).
2. **Test 2b — input clamp at the INA217 inputs** (anti-parallel diodes;
   open at µV, conduct on the quench transient). Shortening the ~40 ms overload
   recovery to ~ms lets a full-size, short-T2\* sample be seen *without* giving
   up signal — the complementary lever to the smaller sample. Details:
   `gradient-broadening-hypothesis.md` §4 Test 2b.
3. **Static gradient survey (Test 1)** — ✅ **DONE 2026-07-17. Home lower deck
   = 37.7 nT/mm ⇒ T2\* ≈ 2.3 ms. Prediction confirmed (ΔB ≳ 300 nT), 19× over.**
   And it answered the "geology or ferrous part?" fork: **neither, quite** — the
   anomaly is a 75 mm-wide **+6 µT spike from something small ~4–6 cm under the
   deck boards** (not regional geology, but not rig-local either: it does *not*
   ride up with the sensor). See the 2026-07-17 section below and
   `gradient-broadening-hypothesis.md` §4 Test 1 RESULT. *Still owed: the same
   survey at the Groynes, for the ≪ 100 nT half of the comparison.*
4. **Find the +6 µT object — PROMOTED to cheapest home gain, possibly decisive.**
   §3 always flagged that *a single steel screw at 10 cm is µT-scale*; the survey
   now says there is one at ~5 cm, right where measurements were taken. The
   sample may literally have been sitting on a deck screw. The phone is the ideal
   tool here (5.7 µT target vs 0.1 µT floor — no careful protocol needed, just
   walk and watch the number). **Move 150 mm, or pull the screw, and re-read.**
   Also still worth checking: steel bottle cap, battery position, brackets.
5. **Raise the sensor off the ground** — Test 3 (the escape that worked) done
   *vertically, in place*. Upward continuation low-passes the gradient: a
   λ-wavelength component attenuates as exp(−2π·h/λ), so h ≈ 1 m knocks a
   short-wavelength (few-metre) basalt anomaly down ~20× while a broad regional
   one barely moves. Attacks the *ground* half only (rig-local ferrous rides up
   with the sensor — that's #4's job). Unlike #1/#2 this lengthens T2\* by
   shrinking the gradient rather than fighting the dead time. If adopted as an
   operating parameter, log the height. Full rationale:
   `gradient-broadening-hypothesis.md` §4 Test 3b.
   **↑ MUCH more promising after Test 1 (2026-07-17) than the λ table suggests.**
   That table was written for *distributed* basalt; the measured source is a
   **compact object ~5 cm down**, which is the shortest-wavelength content there
   is — precisely what height annihilates. As a dipole it falls as 1/(d+h)³, so
   raising the sensor **0.3 m ⇒ ~350×** down, **1 m ⇒ ~10⁴×** down. Height beats
   moving 150 mm sideways (~32×) for a source this shallow. *Correction to this
   lever's "free test" claim:* Test 1's two-height pair was **never measured** —
   the phone screensaver truncated both logs first. The lower-vs-upper-deck
   comparison (Δh = 3.5 m, 5660 → 1015 nT) is a coarse stand-in and is consistent
   with height helping, but it confounds height with location.
6. **Shim** — only if 1–5 fall short: a first-order gradient coil or a
   permanent-magnet shim to cancel the local gradient. Advanced; last resort.

### C. Characterise the instrument (at a quiet site, now that there IS a signal)

1. **T1 (polarization buildup)** — vary on-time (e.g. 1/2/4/6/8 s), plot peak
   vs on-time; if it saturates well before 6 s, shorten it to speed the cycle.
2. **T2\* vs sample size / degassing** — the envelope fit is now automated;
   quantify how much degassing (paramagnetic-O2 removal) buys.
3. **Longer sample-time** — 3–4 s to resolve the true ~0.3 Hz linewidth for a
   better field number (diminishing past ~3× T2\*, i.e. ~3 s here).
4. **Don't over-average** — 1 run ≈ 6; spend runs on field-vs-time instead.

### D. Use it as a magnetometer (the point of the project)

1. **Diurnal tracking** at a fixed quiet site vs the observatory curve — the
   0.1 % absolute agreement means the numbers are now trustworthy.
2. **Ferrous-anomaly detection** — the toolbox run already proved sensitivity
   to a nearby ferrous mass; a controlled distance sweep turns that into a
   detector characterisation.

*Immediate suggestion:* one more Groynes-class session to confirm repeatability
and run the T1/on-time sweep, in parallel with the free home levers (small
sample + de-ferrous the platform + gradient survey).

---

## 2026-07-17 — Test 1 gradient survey: the home null explained *at home*, and the villain is a screw, not the basalt

Phone (Physics Toolbox) on a 1 m plywood batten, fixed N/S orientation, 150 mm
traverse, 5 s dwells, two heights 100 mm apart. Lower deck (historic measurement
position) vs upper deck (+3.5 m). Raw data, analysis script and figure:
`phone_magnetometer_data/` → `plot_gradient_survey.py`,
`gradient_survey_2026-07-17.png`. Full writeup:
`gradient-broadening-hypothesis.md` §4 Test 1 RESULT.

| | lower deck | upper deck (+3.5 m) |
|---|---|---|
| |B| median | 58.95 µT | 56.65 µT |
| spread across 150 mm | **5660 nT** | 1015 nT |
| mean gradient | **37.7 nT/mm** | ≤ 6.8 nT/mm |
| ΔB across 85 mm bottle | **3207 nT** | ≤ 575 nT |
| linewidth / T2\* | 137 Hz / **2.3 ms** | ≥ 24 Hz / ≤ 13 ms |
| phone's own drift floor | 568 nT | 834 nT |
| verdict | **REAL — 10× floor** | **1.2× floor — unresolvable** |

### 1. The home null is now explained quantitatively, at home

5660 nT is 19× the pre-registered 300 nT threshold and 10× the phone's own drift.
ΔB ≈ 3200 nT across the bottle ⇒ **T2\* ≈ 2.3 ms** — born and dead deep inside the
~40 ms blind window (2026-07-14). Until now the null was explained by *inference*
from the Groynes success; it is now measured directly at the failing site, and it
lands exactly where the hypothesis' §3 table predicted.

### 2. The villain is a discrete shallow object, NOT the basalt

The traverse is not a smooth gradient: flat 57.9 → **63.2 plateau** → 59.1 → 58.4.
Level-1 dwells at 0/75/150 mm, above the 57.11 µT regional field:
**+0.74 / +6.09 / +2.03 µT.** Inverting the falloff (4.4× down in 75 mm) puts the
source **~58 mm away if compact (1/r³), ~41 mm if a pipe/bar (1/r²)** — small and
shallow, a few cm under the boards. A tank or rebar mesh *cannot* produce a 75 mm
-wide peak; it would give a broad flat-topped anomaly metres across.

So there are **two** sources, and only one matters:

- **The SPIKE** (+6 µT, ~5 cm down): consistent with **a single deck screw, nail
  plate or joist bracket**. Gradient 37.7 nT/mm average — far worse at the peak.
  **This is the killer.**
- **The PEDESTAL** (+0.7–2.0 µT, broad — every lower-deck dwell sits above
  regional): this is the large mass known to be enclosed under the wooden deck
  (old water tank / pipework / rebar). **Nearly harmless** — a uniform offset
  shifts the Larmor frequency but *does not broaden the line*. Only the gradient
  broadens.

**⇒ The lower deck may be recoverable without changing decks.** The spike is
localized; the regions between dwells sit at the phone's floor (un-measured, not
proven bad). **Key unknown: where did the rig actually sit relative to the spike?**
If the sample has been on top of a deck screw, moving 150 mm may be the whole fix.

### 3. The upper deck is NOT exonerated — it is un-measured

Its 1015 nT is only **1.2× the phone's own drift floor**: indistinguishable from
the phone lying motionless on a table. Test 1's resolution caveat proved
*optimistic* over a 30 s traverse — while stationary the phone wanders 810–890 nT
p2p and random-walks to ~830 nT over 28 s, i.e. **~100× the 7.5 nT that the
Groynes T2\*≈1 s implies**. **The phone is a *reject* instrument, not an *accept*
one.** It did its job by condemning the lower deck; it cannot clear anywhere.
Only the PPM can. *Action: run the rig on the upper deck — it is the only
instrument that can resolve the question, and it costs a session.*

### 4. Method note — do NOT repeat the slow traverse

A 30 s sweep is the worst possible use of this sensor: it accumulates the full
random walk between first and last point. Measured drift scaling: **90 nT @ 1 s →
~140–230 nT @ 3 s → ~570–830 nT @ 28 s.** Use **rapid A/B/A/B swaps** — 2 s per
point, 8–10 repeats. Each difference carries only ~125–195 nT of drift, and √N
averaging gives **~40–60 nT**: a ~15× improvement, and the only phone protocol
that clears 300 nT with confidence. Even so it tops out ~5× above the 7.5 nT
budget — which is exactly why no phone survey can green-light a site.

*Data caveats:* the phone screensaver (~30 s timeout) truncated both logs at
~28 s — 4–5 of the planned 6 dwells survived in each, so the 100 mm vertical pair
never got measured. Post-gap samples are at a different sensor attitude (phone
picked up) and were discarded. Neither loss affects the verdicts above; a repeat
should use the A/B protocol in §4 rather than a fixed-screensaver traverse.

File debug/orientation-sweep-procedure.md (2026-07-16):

# Orientation sweep — finding the polarising-coil angle that gives an FID

> **SUPERSEDED 2026-07-16 — orientation was NOT the blocker.** The first
> confirmed FID (Groynes, off-basalt) appeared at the ordinary horizontal E–W
> *and* N–S orientations with no sweep, and EW vs NS read the same field to
> ~5 nT. The blocker was **gradient-broadened T2\*** on basalt, not polarising
> geometry (as `gradient-broadening-hypothesis.md` §5 already argued — a
> horizontal-EW axis is ≥ 82° from the field for any plausible declination, so
> orientation can only *modulate*, never null). Keep this procedure only as a
> later **optimization** once home operation works; the fine azimuth/tilt sweep
> is not a path to a first detection. See `magnetometer-debug-notes.md`
> (2026-07-16) for the live next-steps list.

**Why this is the next move.** With mains combed out (`comb_notch.py`) the
2200–2600 Hz band is clean and still shows *no* decaying, sample-dependent line.
That points upstream of interference to signal *generation*: a proton FID only
appears when the polarising-coil axis is roughly **perpendicular to the local
field**. If the axis is parallel, the magnetisation stays along the field after
quench and never precesses → zero FID. On this basalt site the true field
direction is shifted from the IGRF model by the local crustal anomaly, so the
best angle must be found empirically, not calculated.

## Prerequisite: find a low-mains site — mains floor vs distance

The orientation sweep assumes a **quiet spot**. Everything so far is radiated
50 Hz pickup (battery power removed the conducted path but the coil still acts as
an antenna for the building's mains field). Now that the whole rig runs on
battery, the biggest free lever is **distance** — do this field trip *before* the
orientation sweep and treat it as its own measurement, not a hopeful relocation.

**Physics / what to expect.** House wiring carries live + neutral with near-equal
opposite currents, so it radiates as a magnetic dipole/quadrupole: field falls
~**1/r² to 1/r³**, much faster than a single conductor's 1/r. The near-house
battery baseline was ~**424 counts** of mains-line RMS in 2200–2600 Hz (already
just under the ~580 broadband floor). A 10× distance gain should sink the
harmonics well below the floor and stop them being the sharpest lines in the band
— an obvious, early win.

**The catch — it's not only the house.** The dominant radiator is often the
*overhead distribution / service-drop lines along the road*, or a buried feeder,
which can beat the panel. Aim for "far from **all** mains conductors," and keep
clear of cars, wire fences, rebar, and buried pipes (ferrous → distorts the local
field *and* re-radiates pickup).

**Procedure — change one variable (distance) at a time.**

1. **Fix everything but position.** Same coil, same orientation as the near-house
   battery runs, same tuned tank, same `ppm.ini`, same battery. This isolates
   distance so the comparison is clean — do **not** also change angle here.
2. **Capture a no-sample baseline at each distance.** No-sample (or coil-*pulsed*
   no-sample) is all you need — the goal is to measure the mains floor, not hunt a
   peak yet. Suggested stops: **~3 m (repeat of near-house), 10 m, 30 m, 50 m**,
   as far as the ground/leads allow.
3. **Read the mains-line RMS immediately**, before moving on — the 2200–2600 Hz
   line level (and the strong low harmonics like 450/750 Hz) versus the 424-count
   near-house number tells you at each stop whether distance is working. A clean
   ~1/r²-ish falloff confirms radiated pickup and reveals the **knee** where the
   harmonics drop under the broadband floor — that distance is your sweep site.

Log each stop so the falloff is on record:

| Distance from house | Bearing / notes (overhead lines? fences?) | Mains-line RMS (2200–2600, counts) | Below broadband floor? |
|---|---|---|---|
| ~3 m (near-house ref) | — | ~424 | ≈ at floor |
| 10 m |  |  |  |
| 30 m |  |  |  |
| 50 m |  |  |  |

To get the RMS number, `comb_notch.py` already prints per-harmonic PSD for a run;
compare the in-band harmonic level between stops (same front-end/settings makes
raw counts directly comparable, as in the 2026-07-01 battery-vs-mains check).

**This is a gradient-vs-balance test (the sensor is already a gradiometer).** The
two sensor coils are wired in series-opposition (verified 2026-06-13: signal only
when a source is inside *one* coil, null for a uniform/centred source), so uniform
ambient mains is already rejected — the pair responds only to the field *gradient*
across its baseline. A localized mains source's field falls ~1/r²–1/r³ but its
gradient falls one more power of r (~1/r³–1/r⁴), so the residual should drop
*faster* with distance than a single coil would. Read the falloff accordingly:
- **Mains drops hard as you move out** → it was the near-field *gradient*; distance
  is the right lever, keep going.
- **Mains barely moves** → the gradiometer already rejects the uniform part and
  you're limited by **coil balance** (area·turns/spacing mismatch leaking
  common-mode) or **downstream coupling** (mains into the transformer/amp/leads,
  not the coils). Neither is fixed by distance — the next levers become a
  gradiometer **balance trim** or **transformer/amp shielding**, and it's worth
  quantifying the pair's CMRR (dB a uniform field is suppressed vs one coil).

**Judge success by the floor, not by a peak.** The point of the trip is to prove
the mains floor dropped. *Then* — at the quietest stop, with orientation now free
to vary — resume the science and run the orientation/tilt sweep below. If a real
FID appears at ~2435 Hz (off the comb, decaying, sample-dependent), *that's* the
detection; a quiet site is what finally lets it show. Don't conflate "moved away"
with "found signal."

## The geometry

The same coil polarises and detects, so one criterion covers both: **coil axis ⊥
to the local field vector.** For the model field (inclination 68°35′, pointing
down-and-magnetic-north) a **horizontal axis pointing magnetic East–West** is
automatically ⊥ to both the vertical and the north components — that is the
theoretical optimum and the sweep's centre point. The anomaly can rotate the
field's declination and tilt its plane, so search **azimuth and tilt around E–W**,
not just the horizontal plane.

## Procedure

1. **Fix everything except angle.** Keep the rig in the same low-mains spot
   (away from the service entry), same sample (degassed water), same tuned tank,
   same battery power. Use a non-magnetic mount; keep tools/phone/operator ≳1 m
   away during each capture. Mark each orientation so it is repeatable.

2. **Coarse azimuth sweep, coil horizontal.** Capture at magnetic azimuth
   ≈ **60°, 75°, 90° (E–W), 105°, 120°** (i.e. ±30° around E–W in ~15° steps).
   Sample runs only at this stage — the goal is to spot which angle first shows a
   gap peak that *decays*.

3. **Add tilt at the best azimuth.** Take the strongest azimuth from step 2 and
   sweep coil **tilt ±30° in ~15° steps** (nose up/down from horizontal). The
   anomaly means the true ⊥ plane is usually a few degrees off horizontal.

4. **Confirm at the winner.** At the best azimuth+tilt, take a full
   **sample + matched no-sample** pair (see settings) for the real discriminator.

## Reading each capture — the discriminators

Do **not** trust the single-shot "SNR / strongest bin" line; empty runs hit
30+ dB on mains. A real signal must pass **all three**:

```
python comb_notch.py data/<sample_run> --reference data/<nosample_run> --field 57198
```

- **Gap peak:** a line in the green Larmor gap standing well above the in-gap
  floor (not the 2–3 dB seen so far).
- **Decay:** gap-envelope first/last-quarter ratio **> ~1.3** (an FID falls with
  T2\* ≈ 1–2 s; steady interference sits at ~1.0).
- **Sample excess:** sample gap-power **above** the matched no-sample reference.

The orientation that first makes these three light up together is the answer.

## Best ppmrun.py settings

The committed `ppm.ini` is already close to optimal — the defaults below are what
it ships with; the notes say why and what to try nudging.

| Setting | Value | Why |
|---|---|---|
| `on-time` | `6000` ms | Polarise ~2–3× T1 (water T1 ≈ 2–3 s) → near-saturated magnetisation. Little gained past this. |
| `delay` | `100` ms | Dead time after quench before sampling. Keep **as short as the quench ring allows** (ring is gone <10 ms; scope shows the tank settling in ~150–200 µs) so the FID head is captured. At the confirm step also take a **`--delay 30`** run (see below) — on basalt T2\* may be only ~100–300 ms, so 70 ms less dead time is a meaningful fraction of the whole decay. |
| `sample-time` | `2000` ms | Long enough to *see the decay* across the window — essential for the decay test. |
| `sample-rate` | `16000` Hz | Nyquist 8 kHz; 2435 Hz well oversampled. |
| `runs` | `6`–`8` | Coherent averaging lifts a weak FID out of noise; use more at the confirm step. |
| `cool-down` | `10000` ms | Let coil/driver settle between runs. |
| `low-freq` / `high-freq` | `2200` / `2600` | Wide band (≈51.7–61 µT) covers the basalt-shifted Larmor. **Search wide; let the real peak reveal itself — don't tune to a number.** |
| `fft-threshold` | `0.0005` | As shipped. |

**Background:** prefer a **coil-*pulsed* no-sample** run as `--background-input`
over `--background-runs` (BKGND). The in-band lines are pulse-induced, so the
coil-off BKGND removes only ~4% of them while a pulsed empty run reproduces ~63%
(see 2026-06-28 debug notes). For the sweep, the simplest robust discriminator is
the **sample-vs-no-sample gap comparison** in `comb_notch.py` above.

Example confirm-step commands:

```
# sample at chosen orientation
python ppmrun.py --tag SAMP_AZ90_TILT10 --runs 8

# matched no-sample, same orientation, coil still pulsed
python ppmrun.py --tag NOSAMP_AZ90_TILT10 --runs 8

# short-delay probe: same orientation, catch a fast-decaying FID head
python ppmrun.py --tag SAMP_AZ90_TILT10_D30 --runs 8 --delay 30
```

The `--delay 30` run is the discriminator for a **short-T2\* FID**. If the
100 ms and 30 ms runs give the same gap power, no fast-decaying head is being
missed and dead time is not the limiter. If the 30 ms run shows **more** gap
power *and* a stronger decay (first/last-quarter ratio > ~1.3) than the 100 ms
run, a fast FID is being clipped off the front at 100 ms — shorten `delay` in
`ppm.ini` and re-confirm. Before trusting 30 ms, eyeball the first ~10 ms of a
raw record for ADC railing; the quench ring clears <10 ms, but this delay has
not yet been checked empirically below 150 ms.

## If the whole sweep is still flat

Then orientation is not the limiter and the gap is truly source-coupling:
filling factor / T2\* (sample volume, degassing) or insufficient precessing
magnetisation. Next levers then: bigger/again-degassed sample, verify the
polarisation LED fires each pulse, and re-check quench speed under load. Also
re-run the whole sweep at **`--delay 30`** — a T2\* short enough to vanish
before 100 ms would make a *real* FID look flat at every orientation, and the
shorter dead time is the only thing that recovers it.

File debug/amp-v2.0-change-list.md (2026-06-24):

# PPM Amplifier v2.0 — Change List / Punch List

Actionable companion to `amp-v2.0-design-review.md`. Work top-to-bottom; the
first two gate everything else. Tick the box when done.

Legend: 🔴 blocker · 🟠 should-fix · 🟡 nice-to-have

---

## 🔴 Must verify / fix before trusting the board

- [x] **Identify U1/U2 — DONE, no action.** Board photos: `ti INA217` in 16-pin
      package. INA217 exists in SOL-16 (DW) — genuine part, correct footprint.
      Pinout verified pin-by-pin vs TI datasheet (2/15=RG, 4=VIN−, 5=VIN+,
      7=V−, 10=REF, 11=VOUT, 13=V+, rest NC) — all match. Gain = 1+10k/5.11 =
      1958/stage → 3.83 M total. Correct.

- [x] **Input bias-return — RESOLVED, no action.** Coil electrical centre is
      grounded at **J2.3**, giving each INA217 input a ~3 Ω DC path to GND
      through half the coil — correct bias return for the bipolar inputs (better
      than discrete Megohm resistors, which would drop volts of offset). Caveat:
      only valid with the coil connected; running with the input open will rail
      (expected). **No design blockers remain on this board.**

---

## 🟠 Should fix

- [ ] **T1 pin 2 — RESOLVED, wiring is correct.** The 42TL016 is 600:600, 1:1,
      center-tapped; pin 2 is the **primary center tap** and is correctly left
      open (primary is driven full-winding end-to-end: pin1=U1 out, pin3=GND).
      Secondary CT (pin5) is correctly grounded, pins 4/6 → U2 diff inputs.
      Only action: add an explicit **no-connect (×) flag on pin 2** to silence
      ERC. (Downgraded from "High" after verifying the part — see review doc.)
- [ ] **Tighten decoupling** C20–C25 (100 nF) hard against each IC's V+/V− pins
      and drop a GND via right at each cap. (EMC DC-001/DC-003 — HF-instability
      path on a high-gain board.)

---

## 🟡 Nice-to-have / housekeeping

- [ ] Confirm the **GND pour is continuous and unbroken directly under U1 and
      the input traces** (2-layer board, no dedicated plane — EMC SU-001).
- [ ] Fix **courtyard overlap C13 ↔ U1** (0.57 mm²) — nudge apart.
- [ ] Fix **U3 datasheet link** — currently points to OP279, should be OP177.
      Reconcile value `OP177G` vs symbol name `OPA177G`.
- [ ] Re-sync **R4 value** — schematic `10.2K 1%` vs PCB `10.2K`.
- [ ] (Pre-fab, not functional) Populate **MPNs** on the BOM so datasheet
      verification and sourcing can run (SS-001 / DS-001).

---

## Bench notes
- Tuning is already on this board: **SW1 selects C1–C12 (0.001–0.56 µF) across
  the coil.** Pick the combination that lands the LC tank at ~2435 Hz
  (max ≈0.61 µF). No external tuning cap needed.
- After fixes, re-run the **shorted-input + envelope-decay baseline** (see
  `magnetometer-debug-notes.md`) before any sample run.

### How to do the shorted-input test correctly
J2 pinout: **pin 1 = VIN−** (U1.4), **pin 2 = VIN+** (U1.5), **pin 3 = GND**
(coil-centre node).

1. **Disconnect the coil.**
2. **Jumper all three J2 pins together: 1 = 2 = 3.** This gives zero differential
   input *and* ties both inputs to GND (keeps the INA217 bias return intact).
3. Power up, scope the output: should sit near **0 V DC** and be **quiet** —
   that is the amplifier's true noise/oscillation floor, the baseline to compare
   every coil measurement against.

**Do NOT** short only pin 2↔pin 3 (grounds VIN+ but leaves VIN− floating → that
input rails) or only pin 1↔pin 2 (zero differential but common mode floats, no
bias return → rails). **Pin 3 (GND) must be in the short.**

Optional, more realistic floor: short pin 1↔pin 2 through a **~6 Ω** resistor
(mimics the coil source resistance) with pin 3 grounded. For a first
"is it quiet / not oscillating?" check, the hard short of all three is simpler.

### How to validate the gain
Two gotchas first: (a) total gain ≈ **3.83 M (132 dB)**, so to get a safe ~2 V
output you need only ~**0.5 µV** in → inject through a **calibrated attenuator**,
never directly; (b) gain is **band-limited and clamped**, so test with a
**2435 Hz sine** and keep the output **below the ±9.8 V zener clamp**
(flat-topped output = clamping, reduce input). Common setup: **SW1 all OFF**
(no tank loading), **no coil**, ×10 probe, AC coupling.

J2 drive: feed **J2.2 (VIN+)** from the attenuator's low node; tie
**J2.1 (VIN−)** and **J2.3** to GND. (The attenuator's bottom resistor also
gives VIN+ its DC bias return.)

**Method A — quick stage-1 check (easiest, highest confidence).** The
transformer splits the chain into two identical ×1958 stages, so one stage
validates the design; trust symmetry for the rest.
1. Divider **÷1000**: 10 kΩ series + **10 Ω** to GND; drive VIN+ from the 10 Ω node.
2. Sig-gen ~**0.5 Vpp** @ 2435 Hz → ~0.5 mVpp at the input.
3. Scope **U1 pin 11** (= T1 primary pad).
4. **Gain₁ = V(U1·11) / V_in** → expect **≈1958 (65.8 dB)**, ~1 Vpp out
   (keep ≤ ~2 Vpp to stay linear).

**Method B — full-chain total gain (the real number).**
1. Divider **÷10 000**: 10 kΩ series + **1 Ω** to GND (the 1 Ω also mimics the
   coil's low source impedance). Inject ratio = 1/10001.
2. Sig-gen ≈ **5 mVpp** @ 2435 Hz → ~0.5 µVpp at the input.
3. Scope **P2 (Signal Out)**.
4. **Total gain = V(P2) × 10001 / V_gen** → expect **≈3.83 M (131.7 dB)**,
   ~2 Vpp clean sine.
   - µV injection is touchy: keep the 1 Ω resistor + leads tiny/short, keep the
     gen cable away from the output end, watch for output not tracking input
     linearly (stray pickup or clamping).

**Bonus (free with the same rig):**
- **Sweep frequency** at fixed input, plot V(P2): should **peak ~2.3–2.4 kHz**,
  −3 dB near ~300 Hz and ~3.4 kHz → validates the transformer bandpass.
- **Raise the input** until the output flat-tops at **±9.8 V** → confirms the
  D1/D2 zener clamp.

| Quantity | Predicted |
|---|---|
| Per stage (U1, U2) | 1958× = 65.8 dB |
| Total @ 2435 Hz | 3.83 M = 131.7 dB |
| Output clamp | ±9.8 V (9.1 V zener + diode) |

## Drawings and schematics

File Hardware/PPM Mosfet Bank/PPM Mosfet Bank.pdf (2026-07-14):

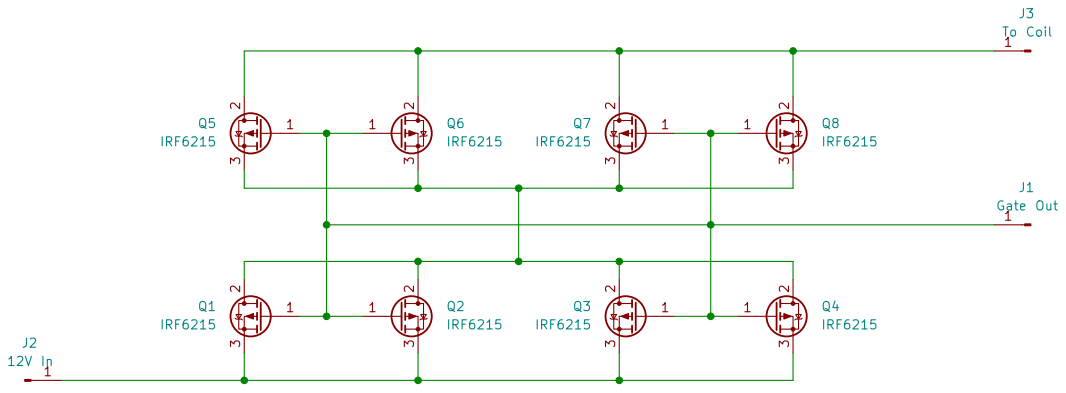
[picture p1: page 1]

D. Q. McDonald
Sheet: /
File: PPM Mosfet Bank.kicad_sch
Title: PPM Mosfet Bank

Size: A4 | Rev: 1.0
KiCad E.D.A. 10.0.1 | Id: 1/1

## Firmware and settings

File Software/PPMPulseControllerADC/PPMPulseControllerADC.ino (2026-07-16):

/***
 * PPMPulseControllerADC.ino — Arduino controller for Proton Precession Magnetometer
 *
 * Receives configuration commands from a Raspberry Pi over serial and manages
 * the full measurement cycle:
 *
 *   1. POLARISE  Energise the coil (COIL_PIN LOW) for coil_activation_time ms.
 *                The strong DC field aligns proton spins in the water sample
 *                along the coil axis (T1 relaxation, ~3 s for tap water;
 *                default 6 s ≈ 2 × T1 captures most available magnetisation).
 *
 *   2. SETTLE    Switch coil off; wait sample_delay ms for the large inductive
 *                transient to decay so it does not saturate the ADC input.
 *
 *   3. SAMPLE    Read the precession signal from the LTC1855 SPI ADC and store
 *                each 16-bit sample in the 23LC1024 SPI SRAM.  The loop runs
 *                as fast as possible; actual rate is measured via the RTC
 *                32.768 kHz interrupt and reported to the Pi.
 *
 *   4. TRANSMIT  Send the actual sample rate, sample count, and all ADC values
 *                to the Pi over serial.
 *
 *   5. COOL DOWN Wait cool_down_period ms for the MOSFET to cool.  During this
 *                phase serial commands are still processed, so the Pi can send
 *                the next run's configuration without risking a serial-buffer
 *                overflow.  An EXECU received during cool-down is queued and
 *                executed automatically when cool-down completes.
 *
 * Background acquisition (BKGND command):
 *   Runs SAMPLE + TRANSMIT only — the coil is never energised, so the record
 *   contains just amplifier noise and ambient interference (mains harmonics,
 *   etc.).  The Pi subtracts its spectrum from a normal measurement's spectrum
 *   to suppress interference that falls inside the Larmor band.  No settle
 *   delay (there is no coil transient) and no cool-down (the MOSFET never
 *   conducted).  A BKGND received during cool-down is queued like EXECU.
 *
 * Pin assignments:
 *   D0  Serial TX (to Pi)            D1  Serial RX (from Pi)
 *   D2  Push button (LOW = pressed)  D3  RTC 32.768 kHz interrupt
 *   D4  Coil activate (LOW = on)     D5  RGB Red
 *   D6  RGB Blue                     D7  ADC BUSY (not currently used)
 *   D8  ADC CS / RD                  D9  RGB Green
 *   D10 SRAM CS                      D11 SPI MISO
 *   D12 SPI MOSI                     D13 SPI SCK
 *
 * External devices:
 *   ADC:  LTC1855 — 16-bit differential SPI ADC, signed two's complement output
 *   SRAM: 23LC1024 — 128 KB SPI SRAM (65 536 uint16_t samples maximum)
 *   RTC:  32.768 kHz square wave; rising edges counted to measure elapsed time
 *
 * Serial protocol:
 *   Command/control is ASCII, '\n'-terminated:
 *     Commands  "XXXXX NNNN\n" — 5-char opcode, optional integer parameter
 *     Responses "OK XXXXX: N\n" on success; "ERR: ...\n" on error
 *
 *   Measurement data is sent as a single binary frame (little-endian) for
 *   speed and reliability — roughly 3× fewer bytes than the old line-based
 *   ASCII format and no per-sample text parsing on the Pi:
 *     bytes 0-3  : marker 'P','P','M','D'
 *     bytes 4-7  : actual_sample_rate (uint32)
 *     bytes 8-11 : num_samples        (uint32)
 *     then num_samples × int16 samples (signed two's complement)
 *
 * Libraries: Bounce2, SRAMsimple
 * Quentin McDonald, October 2024
 */

#include <SPI.h>
#include <Bounce2.h>
#include <SRAMsimple.h>
#include <avr/wdt.h>   // hardware watchdog — see "Watchdog safety" below

// ── Pin definitions ──────────────────────────────────────────────────────────
// const uint8_t is preferred over #define: type-safe and visible in debuggers.

const uint8_t PUSHBUTTON_PIN = 2;
const uint8_t INTERRUPT_PIN  = 3;   // RTC 32.768 kHz square-wave input
const uint8_t COIL_PIN       = 4;   // LOW = coil on (optocoupler/MOSFET active-low)
const uint8_t LED_RED_PIN    = 5;
const uint8_t LED_BLUE_PIN   = 6;
// Pin 7 (ADC BUSY) is wired but not used in firmware
const uint8_t ADC_CS_PIN     = 8;   // LTC1855 chip select (= /RD pin)
const uint8_t LED_GREEN_PIN  = 9;
const uint8_t SRAM_CS_PIN    = 10;  // 23LC1024 chip select
// Pins 11-13 are SPI (MISO/MOSI/SCK), managed by the SPI library

// ── Constants ────────────────────────────────────────────────────────────────

// LTC1855 is a ±10 V differential ADC; full-scale range = 20 V, so VREF = 20.
// Only used by the READV debug command.
const float VREF = 20.0f;

// 23LC1024 capacity: 128 KB = 65 536 × 2-byte (uint16_t) samples.
const unsigned long MAX_SAMPLES = 65536UL;

// Self-test value and iteration count for SRAM startup check.
const int TEST_INT    = 42;
const int NUM_MEMTESTS = 10;

// Serial baud rate — must match PPM.py BAUD_RATE.  250000 divides both the
// 8 MHz and 16 MHz AVR clocks exactly (0% baud error, unlike 57600/115200)
// and cuts the ~48 KB data frame transfer from ~8.3 s to ~1.9 s.
const long BAUD_RATE = 250000;

// Command buffer: longest possible command is "COOLD 10000\n" = 12 chars.
const int SERIAL_BUFF_LEN = 32;

// RTC square-wave frequency for elapsed-time measurement during sampling.
const float RTC_FREQ_HZ = 32768.0f;

// ── Watchdog safety ──────────────────────────────────────────────────────────
// The only hazardous fault in this instrument is the coil being left energised.
// At ~8 A through the ~1.5 Ω polarising coil that is ~90 W dissipated in a
// winding rated for 6-second pulses; if the MCU ever locks up mid-polarisation
// the coil would otherwise stay on indefinitely (overheating / deep-discharging
// the battery).  A fuse cannot catch this — the fault current equals the normal
// 8 A pulse current, so only DURATION distinguishes them.  The hardware watchdog
// bounds that duration instead: loop() (and the long record/transmit loops) must
// call wdt_reset() at least this often, or the AVR resets.  A reset drives every
// pin high-impedance → COIL_PIN floats → optocoupler LED dark → MOSFET gate
// pulled to +12 V → coil OFF (the same fail-safe state as boot), so a hang can
// leave the coil on for at most ~one watchdog period rather than forever.
//
// WDTO_8S is the ATmega328P maximum.  It is chosen for margin, NOT tightness: it
// must never false-trip during a legitimate blocking section (a full-buffer
// transmit is ~5 s over 250000 baud, plus up to ~4 s of acquisition), because a
// spurious reset mid-run corrupts the data frame — the exact failure signature
// we just eliminated on the host side.  Worst-case stuck-on time is roughly
// coil_activation_time + 8 s (~14 s at the 6 s default) — bounded and thermally
// survivable, versus unbounded without the watchdog.
const uint8_t WATCHDOG_TIMEOUT = WDTO_8S;

// ── State machine ─────────────────────────────────────────────────────────────
// Non-blocking design: the main loop never calls delay() except for the brief
// sample_delay settle period.  This keeps the serial port responsive during the
// long polarise and cool-down phases and prevents buffer overflow on multi-run
// measurements.

enum MeasurementState {
    STATE_IDLE,       // waiting for EXECU command or button press
    STATE_POLARISING, // coil energised; waiting for coil_activation_time to expire
    STATE_COOLING     // MOSFET cool-down after data sent; commands still accepted
};

MeasurementState measurement_state = STATE_IDLE;
unsigned long    state_start_ms    = 0;

// Set true when EXECU arrives during cool-down; the measurement starts
// automatically as soon as cool-down completes.
bool measurement_requested = false;

// Set true (together with measurement_requested) when BKGND arrives during
// cool-down, so the queued run is executed as a background acquisition.
bool background_requested = false;

// ── Globals ───────────────────────────────────────────────────────────────────

// Incremented by timer_isr() on each 32.768 kHz rising edge.
// Must be volatile because it is written in an ISR and read in the main loop.
// unsigned long prevents negative wrap-around (long could go negative after
// ~18 hours of continuous interrupts, though this never occurs in practice).
volatile unsigned long interrupt_counter = 0;

SRAMsimple      sram;
Bounce2::Button button = Bounce2::Button();

char serial_buff[SERIAL_BUFF_LEN];

// Measurement parameters — Pi overrides these before each run via commands.
// Defaults match PPM.py defaults so a freshly powered Arduino behaves sensibly
// even if the Pi does not send configuration.
int coil_activation_time = 6000;   // ms  polarisation time (~2 × T1 for water)
int sample_delay         = 500;    // ms  transient settle time after coil off
int cool_down_period     = 10000;  // ms  MOSFET thermal recovery between runs
int sample_rate          = 16000;  // used only to compute num_samples (see SAMRA note)
int sample_time          = 1500;   // ms  ADC sampling window

// ── Structs ───────────────────────────────────────────────────────────────────

struct SampleData {
    unsigned long num_samples;
    unsigned long actual_sample_rate;
};

// ── Forward declarations ──────────────────────────────────────────────────────

void          processCommand();
void          startMeasurement();
void          runBackgroundMeasurement();
SampleData    recordSignal();
void          sendData(unsigned long num_samples, unsigned long actual_sample_rate);
void          writeUint32LE(uint32_t value);
int16_t       read_voltage();
void          spi_transfer_word(uint8_t cs_pin, uint16_t tx, uint16_t *rx);
float         code_to_voltage(uint16_t adc_code, float vref);
void          setRGBLEDColor(int r, int g, int b);
void          timer_isr();
int           getOp(const char *buff);

// ── setup() ──────────────────────────────────────────────────────────────────

void setup() {
    // Disable the watchdog immediately on entry.  After a watchdog reset the
    // WDT stays enabled (with its previous, possibly short timeout) on older
    // bootloaders; if setup() did not finish before it expired the board would
    // reset-loop indefinitely — recoverable only by ISP reflash.  Clearing all
    // reset-source flags (which includes WDRF) is required before WDE can be
    // cleared, so it must precede wdt_disable().  The watchdog is re-armed at the
    // end of setup() once the slow initialisation below is complete.
    MCUSR = 0;
    wdt_disable();

    Serial.begin(BAUD_RATE);
    // If a command arrives partially (serial noise, host crash mid-send),
    // readBytesUntil() gives up after 200 ms rather than blocking forever.
    Serial.setTimeout(200);
    Serial.println(F("\n\nProton Precession Magnetometer - Coil Controller\n"));

    // LED: green = ready
    pinMode(LED_RED_PIN,   OUTPUT);
    pinMode(LED_GREEN_PIN, OUTPUT);
    pinMode(LED_BLUE_PIN,  OUTPUT);
    setRGBLEDColor(50, 200, 50);

    // Push button with internal pull-up; LOW = physically pressed
    button.attach(PUSHBUTTON_PIN, INPUT_PULLUP);
    button.interval(5);
    button.setPressedState(LOW);

    // RTC 32.768 kHz input — interrupt attached only during sampling
    pinMode(INTERRUPT_PIN, INPUT_PULLUP);

    // ADC CS: deassert (HIGH) until a conversion is requested
    pinMode(ADC_CS_PIN, OUTPUT);
    digitalWrite(ADC_CS_PIN, HIGH);

    // Coil MOSFET gate: HIGH = coil OFF (active-low via optocoupler)
    pinMode(COIL_PIN, OUTPUT);
    digitalWrite(COIL_PIN, HIGH);

    // SPI bus — ADC (LTC1855) and SRAM (23LC1024) share MISO/MOSI/SCK.
    // SPI_CLOCK_DIV2 = 8 MHz, within the LTC1855's 10 MHz maximum.
    SPI.begin();
    SPI.setClockDivider(SPI_CLOCK_DIV2);

    // SRAM startup self-test: write and read back TEST_INT at random addresses.
    randomSeed(analogRead(A0));
    bool memory_ok = true;
    for (int i = 0; i < NUM_MEMTESTS; i++) {
        uint32_t addr = random(65536);
        sram.WriteInt(addr, TEST_INT);
        int readback = sram.ReadInt(addr);
        if (readback == TEST_INT) {
            Serial.print(F("Memory check passed: read "));
            Serial.print(readback);
            Serial.print(F(" from address "));
            Serial.println(addr);
        } else {
            // BUG FIX: original code printed "passed" in both branches.
            Serial.print(F("Memory check FAILED: read "));
            Serial.print(readback);
            Serial.print(F(" from address "));
            Serial.print(addr);
            Serial.print(F(", expected "));
            Serial.println(TEST_INT);
            memory_ok = false;
        }
    }
    Serial.println(memory_ok ? F("Memory check done — all passed\n")
                              : F("Memory check done — FAILURES DETECTED\n"));

    // Arm the watchdog now that initialisation is complete.  See the
    // "Watchdog safety" note above for the rationale and fail-safe reasoning.
    wdt_enable(WATCHDOG_TIMEOUT);
    Serial.println(F("Setup done"));
}

// ── loop() ───────────────────────────────────────────────────────────────────

void loop() {
    // Pet the watchdog every iteration.  While IDLE / POLARISING / COOLING the
    // loop spins fast, so a genuine MCU lock-up stops these calls and forces a
    // reset (→ coil OFF) within WATCHDOG_TIMEOUT.  The blocking record/transmit
    // loops pet it internally so they never false-trip on large sample counts.
    wdt_reset();

    button.update();

    // Accept serial commands when idle or cooling.
    // Processing commands during cool-down prevents the 64-byte hardware
    // serial receive buffer overflowing when the Pi sends the next run's
    // configuration immediately after reading the previous run's data.
    if (Serial.available() &&
        (measurement_state == STATE_IDLE || measurement_state == STATE_COOLING)) {
        processCommand();
    }

    switch (measurement_state) {

        case STATE_IDLE:
            if (button.pressed()) {
                startMeasurement();
            }
            break;

        case STATE_POLARISING:
            if (millis() - state_start_ms >= (unsigned long)coil_activation_time) {
                // Proton spins are now aligned along the coil axis.  Switch off
                // the coil; they will precess around Earth's field at the Larmor
                // frequency: f = γ·B/(2π) ≈ 2435 Hz for 57 µT mid-latitude field.
                digitalWrite(COIL_PIN, HIGH);
                setRGBLEDColor(200, 50, 200);  // purple = settling

                // Brief blocking delay for the inductive transient to decay below
                // the ADC input range before sampling begins.
                delay(sample_delay);
                wdt_reset();  // settle delay spans no loop() pet; coil already off

                setRGBLEDColor(200, 200, 50);  // yellow = sampling
                SampleData sd = recordSignal();
                sendData(sd.num_samples, sd.actual_sample_rate);

                // Begin non-blocking cool-down; Pi can send next config now.
                setRGBLEDColor(50, 50, 200);   // blue = cooling
                state_start_ms = millis();
                measurement_state = STATE_COOLING;
            }
            break;

        case STATE_COOLING:
            if (millis() - state_start_ms >= (unsigned long)cool_down_period) {
                setRGBLEDColor(50, 200, 50);   // green = ready
                measurement_state = STATE_IDLE;
                // If the Pi sent EXECU/BKGND while we were cooling, start
                // the queued run immediately.
                if (measurement_requested) {
                    measurement_requested = false;
                    if (background_requested) {
                        background_requested = false;
                        runBackgroundMeasurement();
                    } else {
                        startMeasurement();
                    }
                }
            }
            break;
    }
}

// ── startMeasurement() ───────────────────────────────────────────────────────

void startMeasurement() {
    if (measurement_state != STATE_IDLE) {
        Serial.println(F("ERR: busy"));
        return;
    }
    setRGBLEDColor(200, 50, 30);   // red = polarising
    digitalWrite(COIL_PIN, LOW);   // energise coil
    state_start_ms    = millis();
    measurement_state = STATE_POLARISING;
}

// ── runBackgroundMeasurement() ───────────────────────────────────────────────

void runBackgroundMeasurement() {
    // Sample-only acquisition: the coil is never energised, so the record
    // contains amplifier noise and ambient interference only.  Used by the Pi
    // for background spectral subtraction.
    //
    // Skips the polarise and settle phases (no coil current, no transient)
    // and the cool-down phase (the MOSFET never conducted), so the device
    // returns to IDLE as soon as the data has been sent.  Blocks the main
    // loop for the duration of sampling + transmit, exactly as the normal
    // measurement path does.
    if (measurement_state != STATE_IDLE) {
        Serial.println(F("ERR: busy"));
        return;
    }
    setRGBLEDColor(200, 200, 50);  // yellow = sampling
    SampleData sd = recordSignal();
    sendData(sd.num_samples, sd.actual_sample_rate);
    setRGBLEDColor(50, 200, 50);   // green = ready
}

// ── processCommand() ─────────────────────────────────────────────────────────

void processCommand() {
    // Read one newline-terminated command into serial_buff.
    // readBytesUntil() returns 0 on timeout (200 ms, set in setup()) so a
    // partial or missing command never blocks indefinitely.
    memset(serial_buff, 0, SERIAL_BUFF_LEN);
    int len = Serial.readBytesUntil('\n', serial_buff, SERIAL_BUFF_LEN - 1);
    if (len == 0) return;

    // Trim trailing \r to handle Windows-style CRLF line endings.
    if (serial_buff[len - 1] == '\r') len--;
    serial_buff[len] = '\0';

    if (strncmp(serial_buff, "EXECU", 5) == 0) {
        if (measurement_state == STATE_IDLE) {
            Serial.println(F("OK EXECU"));
            startMeasurement();
        } else if (measurement_state == STATE_COOLING) {
            // Queue the request; it will fire when cool-down ends.
            Serial.println(F("OK EXECU"));
            measurement_requested = true;
        } else {
            Serial.println(F("ERR: busy"));
        }

    } else if (strncmp(serial_buff, "BKGND", 5) == 0) {
        if (measurement_state == STATE_IDLE) {
            Serial.println(F("OK BKGND"));
            runBackgroundMeasurement();
        } else if (measurement_state == STATE_COOLING) {
            // Queue the request; it will fire when cool-down ends.
            Serial.println(F("OK BKGND"));
            measurement_requested = true;
            background_requested  = true;
        } else {
            Serial.println(F("ERR: busy"));
        }

    } else if (strncmp(serial_buff, "ONTIM", 5) == 0) {
        int op = getOp(serial_buff);
        if (op > 0) {
            coil_activation_time = op;
            Serial.print(F("OK ONTIM: "));
            Serial.println(coil_activation_time);
        }

    } else if (strncmp(serial_buff, "SAMPT", 5) == 0) {
        int op = getOp(serial_buff);
        if (op > 0) {
            sample_time = op;
            Serial.print(F("OK SAMPT: "));
            Serial.println(sample_time);
        }

    } else if (strncmp(serial_buff, "SAMRA", 5) == 0) {
        // NOTE: this value controls how many samples are collected
        // (num_samples = sample_rate * sample_time / 1000), NOT the actual
        // sample rate.  The loop runs as fast as SPI transactions allow; the
        // true rate is measured via the RTC interrupt and reported back.
        int op = getOp(serial_buff);
        if (op > 0) {
            sample_rate = op;
            Serial.print(F("OK SAMRA: "));
            Serial.println(sample_rate);
        }

    } else if (strncmp(serial_buff, "DELAY", 5) == 0) {
        int op = getOp(serial_buff);
        if (op >= 0) {
            sample_delay = op;
            Serial.print(F("OK DELAY: "));
            Serial.println(sample_delay);
        }

    } else if (strncmp(serial_buff, "COOLD", 5) == 0) {
        int op = getOp(serial_buff);
        if (op >= 0) {
            cool_down_period = op;
            Serial.print(F("OK COOLD: "));
            Serial.println(cool_down_period);
        }

    } else if (strncmp(serial_buff, "READV", 5) == 0) {
        // Debug: read one ADC sample and print as voltage.
        // VREF = 20 V (LTC1855 ±10 V differential range).
        uint16_t raw     = (uint16_t)read_voltage();
        float    voltage = code_to_voltage(raw, VREF);
        Serial.print(F("Voltage: "));
        Serial.println(voltage);

    } else {
        Serial.print(F("Unknown command: "));
        Serial.println(serial_buff);
    }
}

// ── getOp() ──────────────────────────────────────────────────────────────────

int getOp(const char *buff) {
    // Extract the integer operand from "XXXXX NNNN".
    // The operand starts at index 6 (past the 5-char opcode and one space).
    // atoi() handles the conversion; it returns 0 for missing/non-numeric input.
    if ((int)strlen(buff) > 6) {
        return atoi(&buff[6]);
    }
    return -1;
}

// ── recordSignal() ───────────────────────────────────────────────────────────
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

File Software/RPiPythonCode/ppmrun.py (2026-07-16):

"""
ppmrun.py — Main entry point for the Proton Precession Magnetometer.

Orchestrates hardware collection (via PPM.py), signal analysis (via PPMCalc.py),
and result reporting.  Can also re-analyse previously saved data files without
any hardware connection.

Usage examples
--------------
Single hardware run with default settings::

    python ppmrun.py

Tagged run with 5-cycle averaging and narrow filter::

    python ppmrun.py --tag hillside --runs 5 --low-freq 2200 --high-freq 2700

Run with background subtraction (2 coil-off acquisitions collected first)::

    python ppmrun.py --runs 3 --background-runs 2

Re-analyse an existing data file (no hardware needed)::

    python ppmrun.py --input data/ppm1.dat

Re-analyse with an existing no-sample recording as background::

    python ppmrun.py --input data/ppm1.dat --background-input data/nosample.dat

Settings from an INI file (command line still overrides)::

    python ppmrun.py                       # reads ./ppm.ini if present
    python ppmrun.py --config site.ini     # use a named file
    python ppmrun.py --config site.ini --delay 100   # --delay overrides the file

The file holds a ``[ppm]`` section of long-option names (dashes or underscores)::

    [ppm]
    tag = field_test
    delay = 150
    low-freq = 2200
    high-freq = 2600
    runs = 6

Precedence is command line > config file > built-in default, and the log file
records the effective value and source for every setting.  See ppm.ini.example.

Background subtraction
----------------------
Background acquisitions sample with the coil never energised, recording only
amplifier noise and ambient interference.  Their averaged spectrum is rescaled
to the measurement noise floor and subtracted from the measurement spectrum
before peak detection, suppressing stationary interference — notably mains
harmonics: the 49th harmonic of 50 Hz (2450 Hz) falls inside the Larmor band
and cannot be removed by the bandpass filter.

Multi-run averaging
-------------------
When --runs N > 1, N complete polarise-wait-sample cycles are performed.
The periodograms from all N runs are averaged element-wise before peak
detection.  Averaging in the frequency domain does not require phase alignment
between runs (unlike averaging raw time-domain signals), and improves the
signal-to-noise ratio by approximately √N.

Output directory
----------------
Each invocation creates a timestamped subdirectory:
    <output-dir>/<tag>_YYYY_MM_DD_HH_MM_SS/

All data files, plots, and the session log are written inside this directory
so that multiple runs do not overwrite each other.
"""

import argparse
import configparser
import logging
import os
import sys
from datetime import datetime

import numpy as np
import scipy.signal as sig

import PPMCalc

# Proton gyromagnetic ratio expressed as Hz per microtesla.
# Derived from γ_p = 2.67522 × 10⁸ rad/(s·T) → f = γ_p/(2π) = 42.5775 MHz/T.
# Rearranged: B [µT] = f [Hz] / 42.5775
# For reference: 57200 nT (typical mid-latitude field) → 2435 Hz.
GAMMA_HZ_PER_UT = 42.5775


def build_parser():
    """Build and return the command-line argument parser."""
    p = argparse.ArgumentParser(
        description="Proton Precession Magnetometer data collection and analysis")

    # ── Configuration file ────────────────────────────────────────────────────
    p.add_argument("--config", default="ppm.ini", metavar="FILE",
                   help="INI file of settings, read from the [ppm] section.  "
                        "Any value here overrides the built-in default; a "
                        "command-line option overrides both.  Keys are the long "
                        "option names with or without the leading dashes "
                        "(e.g. 'delay = 150', 'low-freq = 2200').  If the "
                        "default file (ppm.ini) is absent it is silently "
                        "skipped; an explicitly named --config that is missing "
                        "is an error (default: ppm.ini)")

    # ── Serial port ───────────────────────────────────────────────────────────
    p.add_argument("--port", default=None, metavar="DEV",
                   help="Serial port connected to the Arduino, e.g. "
                        "/dev/ttyUSB0 or /dev/ttyAMA0.  Use --list-ports "
                        "to see available ports (default: auto-detect a USB "
                        "serial adapter, falling back to /dev/serial0)")

    p.add_argument("--list-ports", action="store_true",
                   help="Scan and print all available serial ports, then exit. "
                        "Useful for finding the correct --port value when the "
                        "Arduino is connected via USB-serial adapter.")

    # ── Run control ───────────────────────────────────────────────────────────
    p.add_argument("--input", metavar="FILE",
                   help="Analyse an existing data file instead of collecting "
                        "from hardware.  The hardware timing flags are ignored.")

    p.add_argument("--tag", default="PPM", metavar="TAG",
                   help="Descriptive prefix for the output directory name, "
                        "e.g. 'new_amp' → new_amp_2024_01_15_10_30_00/ "
                        "(default: PPM)")

    p.add_argument("--runs", type=int, default=1, metavar="N",
                   help="Number of complete measurement cycles to perform and "
                        "average.  SNR improves by √N but total time scales "
                        "linearly with N (default: 1)")

    p.add_argument("--retries", type=int, default=2, metavar="N",
                   help="How many times to re-attempt a cycle whose data frame "
                        "never arrives.  The coil's switch-off transient can "
                        "wedge the USB-serial adapter's UART engine: the board "
                        "completes the cycle and transmits, but the host's "
                        "handle has gone deaf and every read returns nothing.  "
                        "Re-opening the port resets the adapter and recovers "
                        "the link, so the cycle is simply repeated (the data "
                        "for that cycle is gone either way).  0 disables "
                        "(default: 2)")

    p.add_argument("--background-runs", type=int, default=0, metavar="N",
                   help="Number of background (coil-off) acquisitions to "
                        "collect before the measurement runs.  Their averaged "
                        "spectrum is subtracted from the measurement spectrum "
                        "to suppress stationary interference such as mains "
                        "harmonics — the 49th harmonic of 50 Hz (2450 Hz) "
                        "falls inside the Larmor band.  Background runs are "
                        "fast: no polarise, settle, or cool-down phase "
                        "(default: 0, no subtraction)")
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

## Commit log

2024-10-09 Added Gitignore
    [Pulse Controller.kicad_pcb, Pulse Controller.kicad_sch]
2024-10-09 Folder rearrangement
    [PPM Amplifier.kicad_pcb, PPM Amplifier.kicad_sch]
2024-10-13 V1.0 of PPM Pulse Controller
    Combined with ADC for analysis
    [Pulse Controller.kicad_pcb, Pulse Controller.kicad_sch]
2024-10-14 Added Arduino Sketch for Pulse Controller
    Also rearranged directory structure to separate Hardware and Software
    [PPM Amplifier.kicad_pcb, PPM Amplifier.kicad_sch, Pulse Controller.kicad_pcb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]
2024-10-14 Changed some Caps to SMD
    Also fixed MISO and MOSI assignments
    [Pulse Controller.kicad_pcb, Pulse Controller.kicad_sch]
2024-10-15 PCB for Pulse Controller
    First complete schematic for Amplifier
    [PPM Amplifier.kicad_sch, Pulse Controller.kicad_pcb, Pulse Controller.kicad_sch]
2024-10-17 PCBS update
    Version sent for manufacture for Pulse Controller.
    First complete version for Amplipher
    [PPM Amplifier.kicad_pcb, PPM Amplifier.kicad_sch]
2024-10-20 Update on Amp Layout
    Added power LED
    [PPM Amplifier.kicad_pcb, PPM Amplifier.kicad_sch]
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2024-11-14 Final version of AMP
    Sent to manufacture
    [PPM Amplifier.kicad_pcb, PPM Amplifier.kicad_sch]
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2024-12-14 Added signal reading
    Read signal via ADC and pass to Pi via Serial.
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2024-12-19 Mosfet Bank PCB
    [PPM Mosfet Bank.kicad_pcb, PPM Mosfet Bank.kicad_sch]
2025-01-14 Added 2.0 Version of Signal Amplifier
    [PPM Amplifier v2.0.kicad_pcb, PPM Amplifier v2.0.kicad_sch, PPM Amplifier.kicad_pcb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]
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2026-06-08 Complete PPM software rewrite with CLI, tests, and documentation
    - Rewrote PPM.py with configure(), sendConfiguredValues(), dynamic sleep timing
    - Rewrote PPMCalc.py with load_from_file(), three-panel plots, amplitude envelope,
    parameterised FFT returning peak list, Butterworth bandpass filter
    - Rewrote ppmrun.py as full CLI: --tag, --runs, --input, freq cutoffs, multi-run
    periodogram averaging, timestamped output directories
    - Added ppm_geometry.py: coil orientation diagram for 68°35' inclination
    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
2026-06-08 Update PPM Amplifier v2.0 hardware design and add Gerber outputs
    Updated KiCad schematic and PCB layout; added fabrication outputs
    (Gerber files, drill files, PCBWay BOM/positions/netlist).
    [PCBWay_bom.csv, PCBWay_positions.csv, PPM Amplifier v2.0.kicad_pcb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]
2026-06-08 Add -v/--verbose flag to ppmrun.py for step-by-step progress output
    Prints hardware configuration, per-run sampling results, filter/FFT
    pipeline steps, and frequency resolution in nT at each stage.
    Two new tests cover the flag default and short form.
    [ppmrun.py, test_ppmrun.py]
2026-06-08 Refactor Arduino firmware: bug fixes, state machine, burst SRAM read
    Bug fixes:
    - Memory check FAILED branch now prints "FAILED" (was "passed")
    - Replace undefined CS with CSPIN throughout
    - Replace infinite busy-wait in processCommand() with Serial.readBytesUntil()
    and 200 ms timeout; trim \r for Windows CRLF compatibility
    Structural:
    - Non-blocking state machine (IDLE/POLARISING/COOLING) replaces blocking
    doMeasurement(); serial commands accepted during cool-down preventing
    64-byte buffer overflow on multi-run measurements
    - EXECU during cool-down queued and fired automatically on cool-down completion
    - interrupt_counter changed to volatile unsigned long (was long)
    - All pin definit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
    [PPMPulseControllerADC.ino]
2026-06-08 Add --port and --list-ports options for serial port discovery
    - PPM.py: scan_ports() enumerates available ports via serial.tools.list_ports;
    PPMRun.__init__ accepts port parameter (default /dev/serial0)
    - ppmrun.py: --port DEV overrides the default serial port; --list-ports scans
    and prints all available ports with descriptions and USB hardware IDs, then exits
    - test_ppm.py: stub serial.tools and serial.tools.list_ports submodules so
    the test suite runs without pyserial installed
    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
2026-06-08 Fix serial.tools import error for --list-ports
    Move serial.tools.list_ports import from module level into scan_ports()
    so importing PPM.py never fails due to a missing submodule. Add a clear
    error message directing the user to pip install --upgrade pyserial, and
    wrap the call in ppmrun.py to print it cleanly without a traceback.
    [PPM.py, ppmrun.py]
2026-06-08 Add lat/lon input and fix Southern Hemisphere geometry in ppm_geometry.py
    - Accepts --lat/--lon (default: Christchurch NZ -43.626, 172.726) and
    computes inclination + total field via ppigrf (IGRF-14) or centred-dipole
    fallback; --inclination and --field override if needed
    - Fixes all SH rendering bugs: inclination arcs swapped (now above
    horizontal for negative I), coil-axis arc mirrored to South side,
    B_v symbol changed from ⊗↓ to ⊙↑, "North end elevated" → "South end
    elevated", tilt formula uses 90°−|I| throughout
    - Title now shows location, inclination, total field and expected Larmor
    frequency; print_explanation() shows same plus Larmor freq estimate
    Co-Authored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
    [ppm_geometry.py]
2026-06-08 Fix ppigrf compatibility: use datetime.datetime and .item() scalar extraction
    ppigrf compares dates against pandas Timestamps internally, so datetime.date
    causes a TypeError; switching to datetime.datetime.now() fixes it.
    ppigrf also returns 1-element numpy arrays; np.asarray(...).item() suppresses
    the ndim>0 deprecation warning when casting to float.
    [ppm_geometry.py]
2026-06-08 Add LC capacitor tuning to ppm_geometry.py
    Given the sensor coil inductance, solves C = 1/(L(2πf)²) for the
    required capacitance to resonate at the local Larmor frequency, then
    exhaustively searches all 2^12 combinations of the 12-position DIP
    switch capacitor bank (Table 5.1) to find the closest match.
    Adds --inductance MH CLI arg (default 7.0 mH = book reference 2×3.5 mH).
    Output shows required capacitance, best switch combination with individual
    values, achieved resonant frequency, and percentage error.
    [ppm_geometry.py]
2026-06-08 Transfer measurement data as binary instead of ASCII
    The Arduino now sends sampled ADC data to the Raspberry Pi as a single
    little-endian binary frame rather than one ASCII integer per line:
    marker b'PPMD' | uint32 actual_sample_rate | uint32 num_samples
    | num_samples x int16 samples
    This is ~3x more compact on the wire and removes per-sample text parsing
    for the tens of thousands of samples in a typical run. Command and
    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
2026-06-12 Fix multi-run serial failures, raise baud to 250000, autodetect port
    Multi-run measurements failed two ways, both fixed in PPM.py:
    - Run 2+ timed out waiting for the data marker: the firmware queues an
    EXECU received during MOSFET cool-down and only starts when cool-down
    completes, but the host gave up after the nominal cycle time.
    _sync_to_marker() now takes an overall deadline covering cool_down +
    the full polarise/settle/sample cycle + 2 s margin, retrying the 1 s
    serial timeouts instead of failing on the first empty read.
    - The blind time.sleep() through the hardware cycle let the entire
    binary frame land in the OS serial receive buffer (~16 KB on macOS),
    silently droppin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
    [PPM.py, PPMPulseControllerADC.ino, ppmrun.py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]
2026-06-12 Restore firmware coil_activation_time default to 6000 ms
    The 2000 ms value was a bench-testing leftover; the default is meant to
    match PPM.py's ON_TIME_DEFAULT for standalone (button-triggered) use.
2026-06-12 Add document of analysis, filtering, and pulse-program ideas
    Covers improved frequency estimation (peak interpolation, Hilbert
    phase-slope, decaying-sinusoid fit, zero-crossing counting, spectrogram),
    filtering improvements (SOS, zero-phase, mains-harmonic mitigation,
    background subtraction, windowing), data-quality metrics (SNR, Lorentzian
    linewidth, Allan deviation, IGRF check), and candidate pulse programs
    (background acquisition, T1/delay sweeps, continuous logging, phase
    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
2026-06-12 Add peak interpolation, per-run SNR reporting, and Hann windowing
    Implements the priority-1 items from ANALYSIS_IDEAS.md:
    - PPMCalc.interpolate_peak(): parabolic interpolation through the peak
    periodogram bin and its neighbours, refining detected peak frequencies
    to a fraction of the ~0.67 Hz (~16 nT) bin width. Used by both
    PPMCalc.doFFT() and ppmrun.analyse().
    - PPMCalc.estimate_snr(): peak PSD against the median noise floor in
    100-300 Hz sidebands either side of the peak (median is robust to
    mains-harmonic spikes in the sideband). analyse() reports SNR for
    every run and returns the averaged-spectrum SNR, which report_peaks()
    now prints in dB alongside the field value.
    - H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
    [PPMCalc.py, ppmrun.py, test_ppmcalc.py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]
2026-06-12 Add background acquisition with spectral subtraction
    Implements the priority-2 items from ANALYSIS_IDEAS.md (sections 4.1 and
    2.4): a sample-only acquisition mode for recording amplifier noise and
    ambient interference, and subtraction of its spectrum from the
    measurement spectrum. This suppresses stationary interference that the
    bandpass filter cannot reject -- notably the 49th harmonic of 50 Hz
    mains at 2450 Hz, which lands inside the Larmor band.
    Firmware: new BKGND command runs sample + transmit with the coil never
    energised; no settle delay (no coil transient) and no cool-down (the
    MOSFET never conducted). A BKGND received during cool-down is queued
    like EXECU.
    PPM.py: doMeasurement(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
    [PPM.py, PPMPulseControllerADC.ino, ppmrun.py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]
2026-06-12 Bring ANALYSIS_IDEAS.md up to date with implemented features
    Refresh the intro to describe the current pipeline (Hann window,
    background subtraction, sub-bin peak interpolation, SNR reporting), add
    a status-at-a-glance table covering every item, note that the firmware
    now has two pulse sequences, and mark mains notching as superseded in
    practice by background subtraction.
    https://claude.ai/code/session_01Vn5yx1vTCSuqYtfzejbLA9
2026-06-21 Add plot titles and on-figure peak labelling
    plotSignal() and doFFT() take an optional title; doFFT and the averaged
    FFT in ppmrun label the strongest peaks (red, frequency, deduped within
    40 Hz) with the headline peak also showing the implied field in µT.
    plotSignal now defaults to a 150-sample window on a millisecond axis so
    individual ~2.4 kHz oscillations stay legible. ppmrun gains a --title
    flag defaulting to the run directory name.
    [PPMCalc.py, ppmrun.py]
2026-06-23 Add run-comparison and resonance-suppression analysis tools
    compare_runs.py overlays two PPM run sets (e.g. sample vs no-sample) to
    test for a real, decaying precession signal: it reprocesses every run
    through the PPMCalc pipeline and writes averaged spectrum and RMS-envelope
    overlays. A peak present in both sets, or a flat envelope, indicates
    interference/resonance rather than proton precession.
    suppress_resonance.py peels the steady tank/amp resonance off a record by
    fitting a constant-amplitude sinusoid on the (proton-free) tail and
    subtracting it across the whole record, exposing any decaying signal
    underneath. Supports multi-tone peeling and a no-sample reference overlay.
    Co-Authored-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
    [compare_runs.py, suppress_resonance.py]
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2026-06-24 Add 2026-06-24 addendum: delay measurement + basalt field correction
    Record the raw-counts DELAY comparison (500 vs 150 ms in-band RMS within
    run-to-run scatter -> steady resonance, not a decaying ring-down) and walk
    back the same-day "tank mistuned ~55 Hz low, retune to 2435 Hz" framing: 2435
    is only the IGRF model value, and on a basalt peninsula the local crustal
    anomaly can plausibly put the true Larmor at ~2380 Hz (55.74 uT). Revised next
    step is to search wide and detect by sample-dependence + decay rather than
    chasing an assumed frequency.
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2026-06-24 Add coil-orientation geometry fix to START HERE notes
    Flag the likely geometry trap (axis tilted along the field -> zero signal),
    state the correct meridian tilt as (90-I) from horizontal, and add the
    foolproof E-W horizontal orientation that is perpendicular to the field
    regardless of inclination. Add independent local-direction checks (dip
    needle, phone magnetometer, compass-deflection cross-check) and start the
    sweep from E-W horizontal using compare_runs.py --per-run.
2026-06-24 Add INI config file support to ppmrun.py
    Settings now resolve as command line > config file > built-in default. Read
    the [ppm] section of ppm.ini by default (--config to name another file; an
    explicitly named missing file is fatal, the default one is skipped). Keys are
    long option names with dashes or underscores, type-converted per option, with
    booleans for flags; unknown keys warn, bad values are fatal. Provenance is
    detected via a defaults-suppressed second parse and written to ppm.log as an
    "Effective settings (source in brackets)" block. Add ppm.ini.example, gitignore
    the live ppm.ini, and 8 tests (43 total passing).
    [ppmrun.py, test_ppmrun.py]
2026-06-24 Wait for Arduino boot banner before sending settings
    Opening the serial port toggles DTR and resets the Arduino, which then boots
    ~1-2 s before it accepts commands. The constructor was sending the first run's
    configuration into the still-booting board: the acknowledgements came back
    empty and the boot banner appeared mid-stream as a bogus reply (visible in
    today's logs as empty 'Received response' lines for run 1 only, so run_00 of
    each session likely ran with firmware-default timing).
    PPMRun.__init__ now waits for the boot banner (READY_BANNER, up to
    READY_TIMEOUT_S) via a new _wait_for_ready() before sending anything, then
    flushes the input buffer so the first command gets a clean ack. Ti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
    [PPM.py, test_ppm.py]
2026-06-24 Add averaging_convergence.py — runs-needed diagnostic
    Take one run set and plot candidate-peak SNR vs number of runs averaged
    against the ideal +5*log10(N) curve, plus the noise floor vs N against 1/sqrt(N).
    The run count where the SNR bends away from the ideal line is the point of
    diminishing returns for that noise; a curve that plateaus below it (and a floor
    that stops falling) means the result is interference-limited and more runs will
    not help. Locks onto the strongest in-band line of the full average, or an
    explicit --freq.
    [averaging_convergence.py]
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2026-06-24 Log REV / REV2 control runs in 2026-06-25 debug entry
    Note the polarising-terminals-reversed (REV) and sample-in-other-coil (REV2)
    controls: both peak at the ~2350 Hz mains harmonic like the baseline and the
    band-wide decay scan flags no sample-only decaying feature. Record the caveat
    that a real FID's power spectrum is invariant under both (phase-only flips), so
    they are wiring/artifact sanity checks rather than presence tests -- and they
    pass. First runs confirming the two-phase boot-handshake fix.
2026-06-24 Log oxygen-enhanced sample water as a paramagnetic T2* risk
    The "distilled water" sample is oxygen-enhanced (supersaturated O2). Dissolved
    O2 is paramagnetic and shortens T1 (mildly helpful) and T2/T2* (harmful: faster
    FID decay, broader line). Not the sole cause of the null, but on a basalt site
    where T2* is already gradient-limited it can push the FID below the 100 ms delay
    so it decays before sampling -- consistent with the flat, no-decay records.
    Action: switch to degassed plain distilled water, fill bottle full; test
    oxygen-enhanced vs degassed and a very short delay when weather permits.
2026-06-25 Log microphonic ~100x down, noise now mains (location near service entry)
    The 6/21 200-260 Hz microphonic (22,669 counts grounded) is ~230 counts in
    today's E-W runs (~100x down); strongest low-freq line is now 150 Hz mains.
    Record that today's runs were at a different location closer to where the
    overhead power lines enter the house, which explains the trade from
    microphonic-limited to mains-limited and confirms position dominates mains
    pickup -- so the fix is to get well away from the service entry, ideally
    outdoors. Note the grounded-run caveat to confirm the microphonic is truly gone.
2026-06-25 Log battery-vs-Meanwell option for the coil supply
    Record the option to power the polarising coil from a 12V 16Ah SLA (NOMAD E2
    ULTRA) instead of the 150W Meanwell: trivially capable (9.6A/6s pulse, ~0.16V
    sag, hundreds of runs/charge, maybe slightly more field), removes the SMPS
    switching + mains-ground conducted noise, and chiefly makes the rig portable to
    enable relocation. Note it will NOT by itself fix the radiated 2350/2450 Hz
    sensor-coil mains comb. Practical: J2 wiring, inline fuse, keep clear of sensor.
2026-06-27 Fail fast on rejected EXECU/BKGND instead of marker timeout
    doMeasurement() blindly waited for a data frame after sending the
    command, so a firmware that rejects BKGND (e.g. a build predating the
    background feature, which answers "Unknown command: BKGND") produced a
    baffling 14 s "marker timeout" instead of reporting the real problem.
    send()/sendCommand() now return the Arduino's acknowledgement, and
    doMeasurement() raises immediately on any non-"OK" ack, with a reflash
    hint when the firmware reports an unknown command. Adds two tests
    covering the unknown-command and busy cases (31/31 in test_ppm.py).
    [PPM.py, test_ppm.py]
2026-07-01 Add 50 Hz comb-notch tool to expose the Larmor gap
    Battery-powering the rig left the band dominated by a radiated 50 Hz
    mains-harmonic comb (45th-51st = 2250-2550 Hz). The proton Larmor line for
    the local field (57198 nT -> 2435 Hz) falls in the gap between the 48th and
    49th harmonics, so a narrow notch at every harmonic clears the interference
    without touching the gap.
    comb_notch.py applies zero-phase IIR notches at each mains harmonic in-band,
    then reports the two discriminators: any surviving peak in the Larmor gap
    (spectrum + dB over in-gap median) and the gap envelope first/last-quarter
    decay ratio, with an optional no-sample reference overlay. Style-matched to
    compare_runs.py / suppre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
    [comb_notch.py]
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2026-07-14 Added retry if USB communication between host and ardunio fails during data sending.
    More debugging suggestions.
    [PPM.py, ppmrun.py]
2026-07-14 Latest version of the hardware.
    [PPM Amplifier v2.0.kicad_pcb, PPM Capacitor Bank.kicad_pcb, PPM Capacitor Bank.kicad_sch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]
2026-07-16 Add single-plot FID decay view (plotFilteredEnvelope)
    Add PPMCalc.plotFilteredEnvelope(): plots the whole filtered record in
    one axis with its Hilbert amplitude envelope and an A*exp(-t/T2*)+C fit,
    so an FID's decay is visible as one continuous curve rather than inferred
    from plotSignal()'s three start/middle/end panels. A log_scale option
    plots the envelope on a log Y axis, where a single exponential reads as a
    straight line bending into the noise floor.
    Wire it into ppmrun.py's analysis loop so every run auto-generates
    envelope_NN.png alongside original_NN.png / filtered_NN.png.
    Validated on the 2026-07-16 Groynes SAMPLE_NS run (first confirmed proton
    FID): recovers T2* ~= 1.0 s (wide ba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
    [PPMCalc.py, ppmrun.py, test_ppmcalc.py]
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2026-07-16 Detail the Test 2b INA217 input clamp (placement, diode spec, blanking fallback)
    Expand §4 Test 2b with the concrete front-end design: anti-parallel diodes
    from each U1 input (pins 4/5) to GND (the centre-tapped coil makes to-ground
    the natural, symmetric choice; across-coil and rail-clamp alternatives noted).
    Diode selection driven by clamp tightness + surge survival, not leakage (the
    ~3 Ohm source makes leakage-induced offset negligible): 1N4148 / BAV199, with
    an optional 10-22 Ohm series resistor. Clarify the clamp limits overdrive
    depth (~50x faster recovery) rather than keeping U1 linear, and flag active
    input blanking as the definitive fallback if the passive clamp is insufficient.
    C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
2026-07-16 Add sensor-height lever to basalt gradient-mitigation plan
    Document raising the sensor off the ground as an untried home fix for the
    static-gradient T2* broadening: it is Test 3's site-escape done vertically,
    in place. Add Test 3b to gradient-broadening-hypothesis.md §4 (upward-
    continuation exp(-2*pi*h/lambda) reasoning, the geology-only bound vs
    rig-local ferrous, and the two-height Test 1 survey as its free test), and
    insert it as lever #5 in the §B home-mitigation list in the debug notes
    (renumbering the shim to #6).
    Claude-Session: https://claude.ai/code/session_011RHo8D35zMUwprjwWza3RV
2026-07-17 Record Test 1 gradient survey: home null explained, killer is a shallow object
    Phone magnetometer survey of the home site (2026-07-17), lower deck vs upper
    deck (+3.5 m). Closes out Test 1 from the gradient-broadening hypothesis.
    Lower deck: 5660 nT across 150 mm = 37.7 nT/mm, 19x the pre-registered 300 nT
    threshold and 10x the phone's own drift floor. ΔB ~ 3200 nT across the 85 mm
    bottle => T2* ~ 2.3 ms, dead well inside the ~40 ms blind window. The 2-month
    null is now explained quantitatively AT the failing site, not just inferred
    from the Groynes success.
    The anomaly is a discrete shallow object, not the basalt: a 75 mm-wide +6 uT
    spike whose falloff inverts to a source ~41-58 mm down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
2026-07-17 Ignore the book PDF copy in the repo root
    signalsfromsubatomicworld.pdf sits untracked in the root; the canonical copy
    lives in ~/Documents/EBooks. Named entry rather than *.pdf, to avoid swallowing
    the schematic exports under Hardware/ and debug/ppm_data/ that the debug notes
    reference.
    Claude-Session: https://claude.ai/code/session_01Bn6XnwZ8XorHxuNRqH5zBU
